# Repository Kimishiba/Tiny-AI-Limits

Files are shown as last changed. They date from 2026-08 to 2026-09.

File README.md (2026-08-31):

# ⚡ Tiny AI Limits & Desktop Companion (ESP32-C3)







An open-source, Wi-Fi enabled desktop telemetry companion powered by the ultra-compact **ESP32-C3 SuperMini** microcontroller.

👉 **[Try the In-Browser Hardware Simulator & Showcase Site](https://kimishiba.github.io/Tiny-AI-Limits/)**

It brings your AI developer environment to life with physical desktop hardware — monitoring real-time token quotas, **daily USD ($) spend**, and token telemetry across **Anthropic Claude**, **Google Antigravity**, **OpenRouter**, **DeepSeek**, and more, alerting you when AI agents require plan approvals, and serving as an expressive animated desk companion and synchronized clock.

---

## 🛠️ The Hardware You Can Build

**Tiny AI Limits** is built around a single physical form factor: the **GC9A01 1.28" Circular IPS Cyberdeck Edition**.

<p align="center">
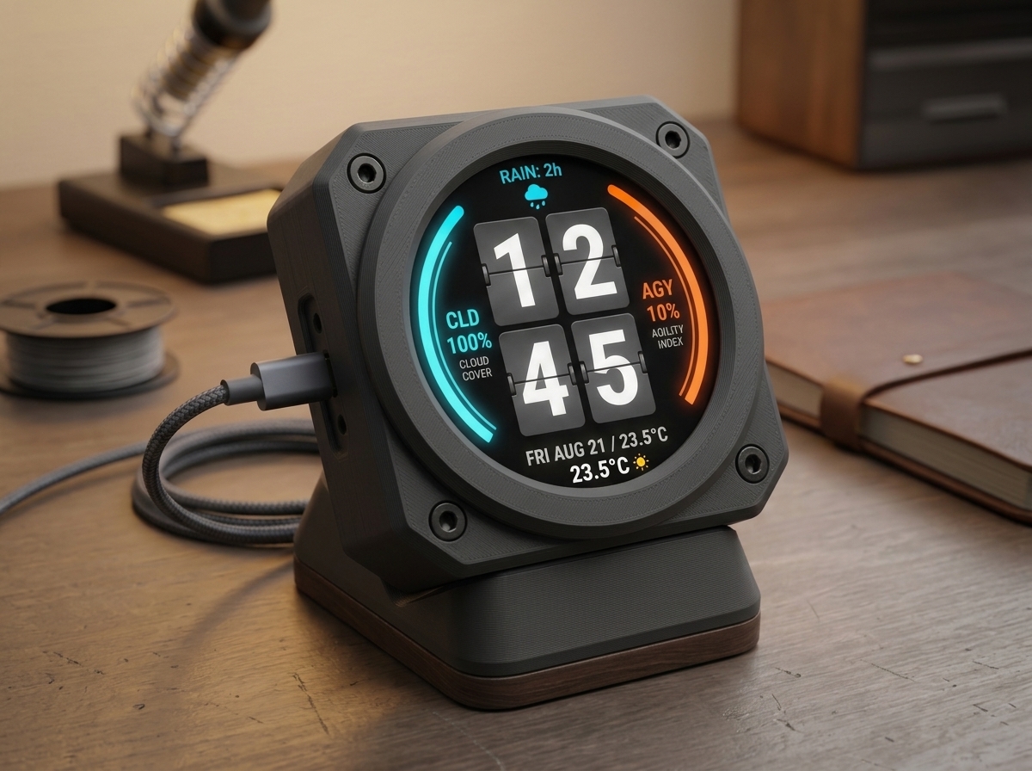
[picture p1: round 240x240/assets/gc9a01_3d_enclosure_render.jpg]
GC9A01 Circular Cyberdeck 3D Render
  
  &nbsp;&nbsp;&nbsp;&nbsp;
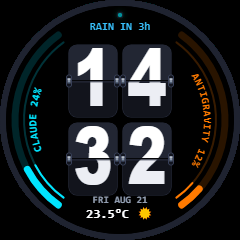
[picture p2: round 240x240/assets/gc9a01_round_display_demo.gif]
GC9A01 Circular Display UI Animation Demo
  
</p>

An industrial sci-fi desktop pod featuring a vibrant **1.28" Circular 240×240 IPS Color Display (GC9A01 SPI)** resting at an ergonomic $18^\circ$ backward tilt on a two-tier modular pedestal.

### ✨ Features:
* **Multi-Agent Status Monitor:** Dynamically replaces the central split-flap clock with a real-time HUD showing live agent activity across Claude Code CLI and Google Antigravity sessions (`WAITING 🟡`, `WORKING 🔵`, `COMPLETE 🟢`).
* **2×2 Split-Flap Flip Clock:** Mechanical split-card matrix animating hour and minute transitions when all agents are idle.
* **Universal Multi-Provider Gauges:** Independently assign any AI service to the Left and Right radial arcs (Claude, Google Antigravity, OpenRouter, DeepSeek, Groq, Mistral).
* **Standard Quota vs Enterprise Spend Modes:**
  * **Standard Quota Mode:** Real-time percentage remaining ($0\% \to 100\%$) and 5-hour rolling reset countdown timer (e.g. `4h 32m`).
  * **Enterprise / PAYG Mode:** Live calendar-day expenditure in **USD ($)** (e.g. `$0.13`), 24-hour token volume in the footer (`28.2k TOK`), and radial arc progression against a customizable **Daily Budget ($ USD)**.
* **Automatic Multi-Model Pricing:** Companion backend automatically scans local transcript turns and calculates exact pricing per model (Sonnet 3.7 / 3.5, Haiku, Opus, cache read/write).
* **Top Crown Connection & Rain Forecast:** Live telemetry heartbeat pulse and rain status (`Rain in 3h`, `Rain Now`, `No Rain`).
* **Stacked Bottom Sub-HUD:** Day & Date, live temperature with weather condition icons, and real-time **Agent Attention Alert** banner overrides (`AGENT ALERT: ALLOW BASH`, `ANSWER Q`, `APPROVE PLAN`).
* **Enclosure Architecture:** Support-free 3D-printable pod with $4\times$ counterbored brass M3 socket head cap screws, raised decorative ring, and a two-tier pedestal stand (Dark Walnut wood base plate with 4 alignment pillars + matte dark truncated trapezoidal cradle trunk).

<p align="center">
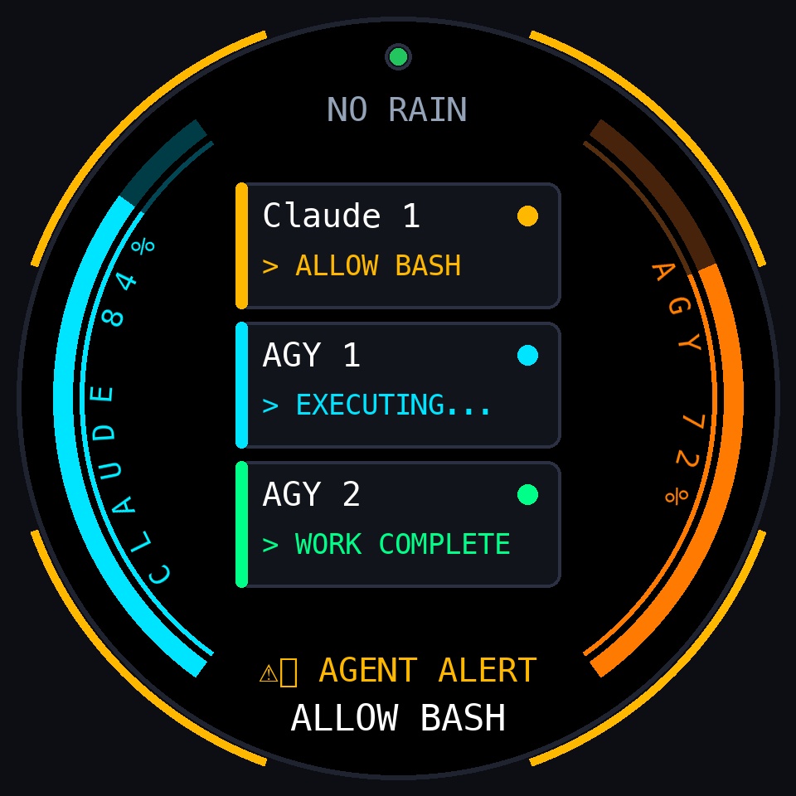
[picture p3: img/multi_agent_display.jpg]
Multi-Agent Status Monitor on GC9A01 Display
  
</p>

---

## 📊 Specifications

| Aspect | Detail |
| :--- | :--- |
| **Display Type** | 1.28" Round Color IPS (240×240) |
| **Interface** | High-Speed SPI |
| **Primary Theme** | Cyberdeck Split-Flap Clock & Dual Radial HUD |
| **Multi-Agent HUD** | Real-Time 3-Row Agent State Matrix (`WAITING`, `WORKING`, `COMPLETE`) |
| **Claude & Antigravity Gauges** | Dual Continuous $180^\circ$ Radial Arcs |
| **Agent Approval Warning** | High-Contrast Yellow/Orange Sub-HUD Alert + Kinetic Amber Hazard Ring |
| **Weather & Rain Forecast** | Top Crown Indicator + Temperature Sub-HUD |
| **Desk Stand** | Modular Two-Tier Pedestal (Walnut + Cradle) |

---

## 🛒 Bill of Materials (BOM) & Purchasing Guide

For a complete parts list, exact component specifications, and direct purchasing links (**Amazon**, **AliExpress**, **Waveshare**, **Adafruit**), see the dedicated BOM documentation:

* 📦 [**`BOM/README.md`**](bom/README.md) — Quick-Start Shopping Kit & Assembly Cost Summary.
* 📋 [**`BOM/BOM.md`**](bom/BOM.md) — Comprehensive Bill of Materials with verified purchasing links.

---

## 🔌 Hardware & Wiring Schematics

### 1. ESP32-C3 SuperMini Pinout (Microcontroller)
The ultra-compact ESP32-C3 SuperMini board powers the device via USB-C (3.3V logic).

---

### 2. GC9A01 Circular Display Wiring (Hardware SPI)

| GC9A01 Display Pin | ESP32-C3 SuperMini Pin | Description |
| :--- | :--- | :--- |
| **VCC** | **3V3** | 3.3V Power Rail |
| **GND** | **GND** | Ground |
| **SCL / SCLK** | **GPIO 4** | SPI Clock |
| **SDA / MOSI** | **GPIO 6** | SPI MOSI (Data) |
| **DC** | **GPIO 7** | Data / Command Control |
| **CS** | **GPIO 5** | Chip Select |
| **RST / RES** | **GPIO 1** | Hardware Reset |
| **BLK** | **GPIO 0** (or 3V3) | Backlight PWM / Enable |

*(For breadboard hookup instructions, see [`WIRING.md`](WIRING.md)).*

---

## 🖨️ 3D Printing & Enclosure Assembly

All enclosure CAD models are **100% support-free FDM 3D printable** and available in both parametric OpenSCAD sources and verified watertight STLs:

### Models Included (`round 240x240/enclosure/`):
* `gc9a01_springlatch_enclosure_flat.stl` — **Springlatch Edition:** 100% Print-in-Place articulated clamshell enclosure with Clockspring-style compliant wavy spring latch, push-button locking tabs, GC9A01 display mount, snap-fit ESP32-C3 cradle, and $18^\circ$ desktop kickstand pads (Flat 180° orientation, zero screws needed).
* `gc9a01_front_bezel.stl` — Front bezel display carrier with anti-shadow conical bevel and M3 counterbores.
* `gc9a01_main_housing.stl` — Enclosure bucket with lowered USB-C port and M3 corner pilot holes.
* `gc9a01_stand_tier1_base.stl` — Tier 1 base plate with 4 alignment pillars and rubber feet recesses (ideal for wood PLA or dark walnut).
* `gc9a01_stand_tier2_trunk.stl` — Tier 2 sculpted monolithic pedestal trunk with 4 slide sockets and $18^\circ$ V-saddle cradle notch.
* `gc9a01_desk_stand.stl` — Unified single-piece monolithic desk stand.

---

## 📖 Frequently Asked Questions (FAQ)

Have questions about the project, components, or setup? Check out the [FAQ](FAQ.md) for quick answers!

---

## 🚀 Getting Started

### 1. Build & Flash Firmware
Using **PlatformIO**:

```bash
# Build firmware
python -m platformio run

# Upload to ESP32 over USB-C
python -m platformio run --target upload
```

### 2. Launch the PC Companion Backend
The companion service monitors your local AI agent transcripts, queries live Antigravity token limits, fetches local weather data, and advertises itself via zero-config mDNS:

* **macOS:** Double-click **`Tiny Screen.app`** (native executable application with dedicated menu bar icon) or run `./TinyScreen.command`.
* **CLI / Cross-Platform:**
```bash
# Install dependencies
pip install -r backend/requirements.txt

# Launch backend
python backend/app.py
```
*(To rebuild or customize the macOS application bundle, run `./scripts/build_mac_app.sh`).*

### 3. USB WiFi Provisioning & Gauge Customization
With the device plugged in via USB-C, open **[`http://localhost:5000/setup`](http://localhost:5000/setup)** in Google Chrome or Microsoft Edge:
1. **Wi-Fi Setup:** Select the board's serial port, scan for networks, and enter your credentials. This also pairs the board to your machine.
2. **Configure Dual HUD Gauges:** Choose which AI service appears on the **Left** and **Right** radial arcs (Anthropic Claude, Google Antigravity, OpenRouter, DeepSeek, Groq, Mistral).
3. **Select Plan / Usage Mode per Provider:**
   * **Standard Quota (5h / Hourly Reset Timer):** Ideal for Claude Pro / Antigravity standard plans with 5-hour rolling quotas. Displays $\%$ remaining and time until quota resets (`4h 32m`).
   * **Enterprise Mode (Spend in $ & 24h Tokens):** Ideal for Enterprise, Team, or Pay-As-You-Go accounts. Displays live spend in **`$`** inside the corridor card (`$0.13`), total 24h token volume in the footer (`28.2k TOK`), and tracks progress against your customizable **Daily Budget ($ USD)**.
4. **Custom Cloud API Keys:** For cloud LLMs (OpenRouter, DeepSeek, Mistral, Groq), enter your API key in the collapsible accordion.

---

## 🔗 Multiple Boards on One Network

If several people run Tiny AI Screen on the same Wi-Fi (a shared office or household), each board needs to know *which* companion app is its own. Otherwise a board can pick up a colleague's app and display their Claude Code / Antigravity quotas.

**Pairing** solves this. Each companion app generates a stable `pair_id` (stored in `~/.tiny_ai_screen/config.json`), and a paired board talks only to the computer it was paired with.

* **Direct Serial Setup** (recommended) pairs the board automatically — no extra step.
* **"Connect & Set Up WiFi"** (Improv) can only send Wi-Fi credentials; the protocol has no room for an address. After it finishes, pair the board with the **"Pair an Existing Board"** box on the setup page, entering the board's IP.
* If your computer's IP changes (DHCP lease renewal), a paired board re-finds it automatically by matching `pair_id` against the mDNS TXT records. If that fails, re-pair with the same box.

**Pairing is one-way.** Once a board has been paired, it never goes back to picking whichever companion answers first — even if it loses track of its host. It will show no data and wait to be re-paired rather than risk reading someone else's stats.

**The top crown status arc tells you which mode a board is in:**

| Status Arc | Meaning |
| --- | --- |
| Green arc (pulsing) | Paired & connected, reading from your companion app |
| Amber arc | Connected but **unpaired** — the figures may not be yours |
| Red arc | No connection |

Each board also claims a unique mDNS name derived from its MAC — `tinyscreen-F030.local` rather than a shared `tinyscreen.local` — so several boards can coexist on one subnet.

> **Upgrading an existing board?** Boards flashed before pairing existed keep working: they fall back to mDNS discovery, and show the amber/unpaired indicator while they do. That fallback is exactly what can latch onto the wrong companion, so **re-run Direct Serial Setup once** after updating the firmware. After that the board is pinned for good.

---

## 🎨 Interactive Browser Prototype & Visualizer

Preview and interact with all screens, animations, and telemetry states in real time:

* **Full Display Emulator:** `http://localhost:5000/emulator`

---

## 📂 Repository Structure

```
├── backend/                  # Python Flask companion service & token trackers
│   ├── app.py
│   └── claude_statusline.py
├── round 240x240/            # GC9A01 1.28" Round IPS Edition
│   ├── enclosure/            # Parametric OpenSCAD & watertight STLs
│   │   ├── generate_stl.py
│   │   ├── gc9a01_cyberdeck_enclosure.scad
│   │   ├── gc9a01_front_bezel.stl
│   │   ├── gc9a01_main_housing.stl
│   │   ├── gc9a01_stand_tier1_base.stl
│   │   ├── gc9a01_stand_tier2_trunk.stl
│   │   └── gc9a01_desk_stand.stl
│   └── assets/               # 3D concept renders, animated demo GIF & mascot frames
│       ├── gc9a01_3d_enclosure_render.jpg
│       └── gc9a01_round_display_demo.gif
├── emulator/                 # Interactive browser visualizers & emulators
│   ├── index.html            # Canvas emulator for the round HUD
│   └── setup.html            # WebSerial USB Wi-Fi provisioning
├── img/                      # 3D product renders & animation demos
├── src/                      # ESP32-C3 Arduino C++ firmware
│   └── main.cpp
├── platformio.ini            # PlatformIO build configuration
├── WIRING.md                 # Detailed pinout & wiring documentation
└── README.md
```

---

## 📄 License
MIT License. Feel free to build, customize, and share your own desktop AI companion!

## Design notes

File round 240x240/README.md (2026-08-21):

# 🔘 GC9A01 1.28″ Round Display Cyberdeck (240×240)

An ultra-compact desktop telemetry HUD and 2×2 mechanical split-flap flip clock designed for the **GC9A01 1.28″ circular IPS display (240×240)** powered by the **ESP32-C3 SuperMini**.

Enclosure Front View
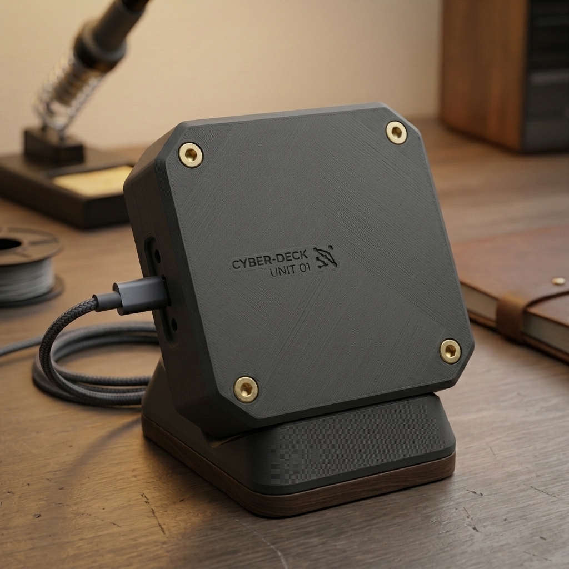
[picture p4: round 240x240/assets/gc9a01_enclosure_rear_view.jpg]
Enclosure Rear View


---

## 🌟 Features

* **Center 2×2 Split-Flap Clock:** Vintage mechanical flip digits (`12` top / `45` bottom) with tall $46\times 68\text{px}$ aspect ratio, dual-tone split creases, side hinge pin brackets, and animated 3D flap perspective folding.
* **Dual Flanking Radial Telemetry Gauges:**
  * **Left Gauge (Cyan):** Claude AI Quota remaining ($0\%$ at bottom $\to 100\%$ at top) with curved inside label `CLD %`.
  * **Right Gauge (Orange):** Antigravity Quota remaining ($0\%$ at bottom $\to 100\%$ at top) with curved inside label `AGY %`.
* **Top Crown Rain Metric:** Real-time weather integration indicating hours until next rain (`RAIN: 2h 🌧️` / `NO RAIN ☀️` / `RAIN NOW 🌧️`).
* **Stacked Bottom Sub-HUD:**
  * Line 1: Day & Date (`FRI AUG 21`)
  * Line 2: Live Temperature & Weather Icon (`23.5°C ☀️`)
  * Dynamic Alert Override: `⚠️ AGENT ALERT` + `APPROVE PLAN` with pulsing outer watch bezel.
* **Interactive Browser Emulator:** Full simulation at `http://localhost:5000/round` with screen type switcher, live telemetry sliders, and instant manual flip triggers.

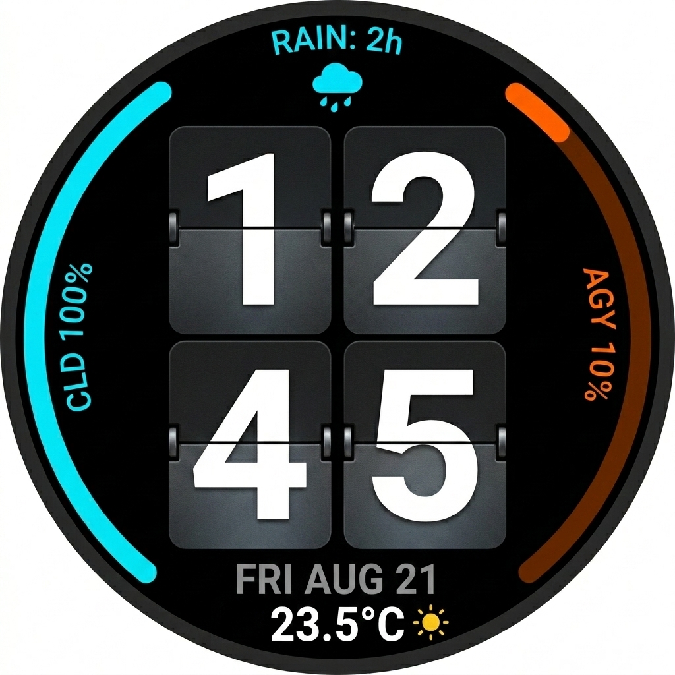
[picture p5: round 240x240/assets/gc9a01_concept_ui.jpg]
UI Concept


---

## 🖨️ 3D Printed Cyberdeck Enclosure

All 3D printable STL files and parametric CAD models are located in [`enclosure/`](enclosure/):

* **[`gc9a01_front_bezel.stl`](enclosure/gc9a01_front_bezel.stl):** Front plate with circular retention lip and counterbored M2 screw pockets.
* **[`gc9a01_main_housing.stl`](enclosure/gc9a01_main_housing.stl):** $22\text{mm}$ deep chassis with cavity for the ESP32-C3 SuperMini and USB-C port cutout.
* **[`gc9a01_desk_stand.stl`](enclosure/gc9a01_desk_stand.stl):** $20^\circ$ ergonomic angled desk base with cable relief channel.
* **[`gc9a01_cyberdeck_enclosure.scad`](enclosure/gc9a01_cyberdeck_enclosure.scad):** Parametric OpenSCAD source file.

---

## 🔌 Hardware Pinout (GC9A01 to ESP32-C3 SuperMini)

| GC9A01 Pin | ESP32-C3 SuperMini Pin | Function | Notes |
| :--- | :--- | :--- | :--- |
| **VCC** | `3V3` | Power Input | $3.3\text{V}$ Logic & Power |
| **GND** | `GND` | Ground | Common Ground |
| **SCL / SCK** | `GPIO 4` | SPI Clock | Hardware SPI SCLK |
| **SDA / MOSI** | `GPIO 6` | SPI MOSI | Hardware SPI Master Out |
| **DC** | `GPIO 7` | Data / Command | Command/Data Selection |
| **CS** | `GPIO 5` | Chip Select | Active Low |
| **RST** | `GPIO 1` | Hardware Reset | Active Low |
| **BLK / LED** | `3V3` or `GPIO 0` | Backlight | PWM Dimmable on GPIO 0 |

---

## 🚀 Running the Emulator

1. Start the Flask telemetry backend:
   ```bash
   python backend/app.py --server-only
   ```
2. Open your browser:
   * **Round Screen Direct:** [http://localhost:5000/round](http://localhost:5000/round)
   * **Main Emulator:** [http://localhost:5000/emulator](http://localhost:5000/emulator)

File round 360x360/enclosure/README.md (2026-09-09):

# 🖨️ GC9B72 2.1″ Round Display (360×360) Cyberdeck Enclosure (Heritage Edition)

3D printable enclosure files, slicer settings, hardware BOM, and assembly instructions for the **2.1-Inch GC9B72 Cyberdeck Desk Console**, engineered directly following the **240×240 Unit 01 Heritage Architecture** with the **Option 2 Rear-Loading Screen Architecture**:
* **100% Symmetrical 84mm Square Chassis ($84.0\text{mm} \times 84.0\text{mm}$)**
* **Option 2 Rear-Loading Screen Architecture (Direct M2 Tab Clamping):**
  * **100% Seamless Monolithic Front Face:** Clean solid front plate with a prominent raised circular bezel rim ($\varnothing 72.0\text{mm}$, $+2.8\text{mm}$ elevation) and a continuous anti-shadow conical viewing funnel expanding from $\varnothing 54.0\text{mm}$ at the screen shelf to $\varnothing 60.0\text{mm}$ at the ring summit.
  * **Zero Front Screws & Zero Exposed Cutouts:** The rectangular PCB tab, solder joints, flex ribbon, and 10-pin header are completely concealed inside the enclosure.
  * **Solid Front Retaining Lip:** $2.62\text{mm}$ continuous circular flange prevents display glass from ever pushing out the front.
  * **Direct M2 Screen Tab Clamping with Rising Boss Pillars:** 2x solid $\varnothing 4.40\text{mm}$ cylindrical boss pillars rise $1.80\text{mm}$ from the deepened tab pocket floor ($Z = 4.20\text{mm}$) up to the screen seating plane ($Z = 2.40\text{mm}$) at $X = \pm 12.20\text{mm}$, $Y = -31.50\text{mm}$ matching the blueprint `2-R1` holes. Each pillar contains a blind $\varnothing 1.70\text{mm}$ pilot hole ($3.6\text{mm}$ deep) allowing direct M2 screws from the back of the screen.
  * **Deepened Tab Relief & DuPont Clearance:** The tab pocket floor is recessed to $Z = 4.20\text{mm}$ with an extra $2.2\text{mm}$ trench over the header ($Y = -34.0\text{mm}$), giving ample room for forward-facing DuPont pins and solders around the rising pillars while leaving $\ge 2.40\text{mm}$ solid front wall thickness.
  * **Internal Rear Clamp Bracket (Optional / Legacy):** Preserved for backward compatibility, but no longer required when using the 2x direct M2 tab screws.
* **Chamfering & Edge Bevels:** $45^\circ$ outer bottom perimeter chamfer ($1.2\text{mm} \times 45^\circ$) + $7.0\text{mm} \times 45^\circ$ corner chamfers
* **Flush-Edge Microcontroller Mounting:** ESP32-S3/C3 SuperMini mounted **only $1.2\text{mm}$ from the outer left flank** for flush USB-C cable seating
* **Shaved-Depth USB-C Port:** Precision oval/stadium cutout ($r_{inner}=1.95\text{mm}$) with $45^\circ$ conical lead-in entry flare
* **High-Airflow Cooling System:**
  * 7 $\times$ vertical exhaust vents with $45^\circ$ peaked roof along top wall ($Y = +42\text{mm}$)
  * Contour-following horizontal rear aeration rows in outer zones ($|Y| \ge 16.5\text{mm}$)
  * Safe under-ESP32 cooling grille
* **Precision M.2-Style Screw Retention System (G0 Approved):**
  * **Bifurcated Front Capture Ears:** Left ($Y = -9.65\text{ to } -5.00\text{mm}$) and Right ($Y = +5.00\text{ to } +9.65\text{mm}$) ears with $45^\circ$ self-supporting lead-in chamfers trap front PCB shoulders against lift and pull-out, leaving central $10.0\text{mm}$ open for the USB-C metal shell.
  * **Expanded Clone Tolerances:** $19.30\text{mm}$ pocket width, $Z = 5.90\text{mm}$ ear height, $24.20\text{mm}$ longitudinal span swallows AliExpress board variations ($1.2 - 1.6\text{mm}$ thickness, $18.2 - 18.9\text{mm}$ width).
  * **Mechanical Thrust Stop Rib ($X = -17.0\text{mm}$):** Absorbs 100% of USB-C insertion forces directly into the chassis floor.
  * **Rear Standoff Post ($X = -11.5\text{mm}$):** $\varnothing 7.00\text{mm}$ post with thick $2.175\text{mm}$ solid plastic wall (5 perimeters) and $\varnothing 2.65\text{mm}$ pilot hole, eliminating hoop stress blowout. Positioned $> 5.5\text{mm}$ behind the ceramic antenna element to protect 2.4GHz Wi-Fi/BLE from RF detuning.
  * **Precision M3 Clamp Tab (`gc9b72_esp32_clamp_tab.stl`):** $11.50 \times 7.50 \times 4.00\text{mm}$ bridge tab with captive retention ring and 100% planar bed face for support-free printing in $\sim 2.5\text{ mins}$.
* **Dual Elevated DuPont Clearance Trenches:** Starts at $Z = 6.0\text{mm}$ with $45^\circ$ self-supporting bottom ramps along both the bottom wall (for screen 10-pin DuPont headers) and opposite right wall (for internal jumper bundle routing and side accessories).
* **Fasteners:**
  * 2x M2 $\times$ 4mm or 5mm Socket Head / Pan Head / Self-Tapping Screws for direct screen tab clamping ($\varnothing 1.70\text{mm}$ blind pilot holes in Front Face)
  * 4x M3 $\times$ 16mm Socket Head Cap Screws for Chassis Corners ($\varnothing 2.50\text{mm}$ direct-tap pilot posts)
  * 1x M3 $\times$ 6mm or 8mm Socket Head or Button Head Cap Screw for ESP32 Hold-Down Tab

---

## 📁 Included CAD & STL Files

All models are located in [`round 360x360/enclosure/`](./):

| File | Description | Outer Dims ($W \times D \times H$) | Print Time (est.) |
| :--- | :--- | :---: | :---: |
| **`gc9b72_front_face.stl`** | Monolithic Symmetrical 84mm Square Front Plate with prominent raised circular bezel rim, continuous conical viewing funnel, precision 31.2mm rear screen pocket, 2x direct M2 blind pilot holes, DuPont pin forward relief pocket, and 4x M3 corner countersunk holes | **$84.0 \times 84.0 \times 9.8\text{ mm}$** | ~45 mins |
| **`gc9b72_rear_clamp.stl`** | *(Optional / Heritage)* Slim Full-Footprint 84mm Sandwich Clamp Plate with 4x M3 corner clearance holes, center ventilation port, and precision 32.0mm screen PCB tab window | **$84.0 \times 84.0 \times 1.6\text{ mm}$** | ~12 mins |
| **`gc9b72_main_housing.stl`** | Symmetrical 84mm Square Housing Pod with tolerance-based press fit cradle, micro-crush ribs, front capture ears, shaved USB-C port, peaked roof vents, and 4x direct tap corner posts | **$84.0 \times 84.0 \times 28.0\text{ mm}$** | ~55 mins |
| **`gc9b72_stand_tier1_base.stl`** | Stand Tier 1 Accent Base Plate with 4x rubber feet pockets and alignment sockets | $94.0 \times 88.0 \times 6.0\text{ mm}$ | ~25 mins |
| **`gc9b72_stand_tier2_trunk.stl`** | Stand Tier 2 Cradle Trunk with $22^\circ$ V-saddle for 84mm pod and $26\text{mm}$ rear cable channel | $90.0 \times 85.0 \times 29.0\text{ mm}$ | ~50 mins |
| **`gc9b72_monolithic_stand.stl`** | Single-piece combined desk stand for 84mm square pod | $94.0 \times 88.0 \times 32.0\text{ mm}$ | ~70 mins |
| **`gc9b72_top_bezel.stl`** | *(Legacy / Optional)* External Circular Top Bezel Ring for front-clamping configurations | $74.6 \times 66.8 \times 4.5\text{ mm}$ | ~20 mins |
| **`gc9b72_cyberdeck_enclosure.scad`**| Fully parametric OpenSCAD master source model (Parts 0–6) | — | — |
| **`generate_stl.py`** | High-performance Python Manifold generator for watertight binary STLs | — | — |

---

## 🔩 Hardware Bill of Materials (BOM)

| Item | Quantity | Purpose | Notes |
| :--- | :---: | :--- | :--- |
| **GC9B72 2.1″ Round IPS TFT Display ($360\times 360$)** | 1 | Circular color display module | GoldenMorning / EstarDyn 10-pin SPI |
| **ESP32-S3 SuperMini / Zero (or C3 SuperMini)** | 1 | Microcontroller board | Press-fit into integrated cradle with crush ribs |
| **M2 $\times$ 4mm or 5mm Screws** | 2 | Clamps screen tab directly to Front Face | Direct taps into $\varnothing 1.70\text{mm}$ blind holes |
| **M3 $\times$ 16mm Socket Head Cap Screws** | 4 | Fastens Front Face directly to Main Housing Pod | Direct taps into $\varnothing 2.50\text{mm}$ corner posts |
| **8mm $\times$ 1.5mm Adhesive Rubber Feet** | 4 | Fitted into stand base recesses for non-slip desk grip | Optional |
| **USB-C Cable (Braided or Standard)** | 1 | Power & data connection through left port | Plugs into flush ESP32 port |

---

## 🛠️ Step-by-Step Assembly Sequence

1. **Install and Clamp the Display Module:**
   * Place the `gc9b72_front_face` face-down on a soft surface.
   * Drop the GC9B72 display module into the rear pocket cavity from behind. The round glass seats flush against the internal $2.62\text{mm}$ retaining lip, and the forward-facing DuPont header pins/solders clear into the dedicated relief trench.
   * Fasten 2x M2 $\times$ 4mm or 5mm screws through the screen's bottom tab mounting holes into the blind $\varnothing 1.70\text{mm}$ pilot holes. Tighten gently until snug. The screen is now 100% rigidly clamped to the front faceplate!
2. **Wire the Display:**
   * Plug female DuPont jumpers directly onto the 10-pin header.
3. **Install the Microcontroller (Tool-Free Drop-In Press Fit):**
   * Align the ESP32 directly over the open U-cradle with the USB-C connector facing the left wall port.
   * Press the board straight down onto the internal support ledges. The 4x vertical micro-crush ribs yield slightly against the fiberglass edges to firmly lock the board in place against the dual rear thrust corner shoulders ($X = -17.6\text{mm}$).
   * Connect the DuPont jumpers to the corresponding SPI pins on the ESP32.
4. **Close the Console:**
   * Mate the Main Housing Pod directly onto the back of the Front Face.
   * Thread the 4x M3 $\times$ 16mm screws into the corner counterbored holes from the front and tighten until snug. The entire console is assembled!

---

## ⚙️ Slicer Print Settings (Bambu Studio / PrusaSlicer / OrcaSlicer)

* **Material:** 
  * Main Housing & Rear Clamp: Matte Charcoal Black PLA / PETG.
  * Front Face Plate: Matte Charcoal Black with optional accent color ring or single color.
  * Stand Base: Wood PLA or Walnut Brown PLA.
* **Perimeters / Walls:** **`4` walls minimum** (ensures 100% solid plastic around the $\varnothing 2.05\text{mm}$ and $\varnothing 2.50\text{mm}$ pilot holes and cradle retaining clips).
* **Layer Height:** `0.16mm` or `0.20mm`.
* **Top / Bottom Solid Layers:** `4` top, `4` bottom.
* **Infill:** `20% Gyroid` or `Grid`.
* **Supports:** **NONE NEEDED** when oriented properly:
  * **Front Face:** Print flat front face-up (or face-down on a textured PEI sheet).
  * **Rear Clamp:** Print flat on build plate. Allow the spring steel build plate to cool completely to room temperature before removing to prevent deflection of the slim 1.6mm bottom bridge.
  * **Main Housing:** Print with rear backplate on build plate (cavity opening facing up).
  * **Desk Stand:** Print flat on bottom surface.

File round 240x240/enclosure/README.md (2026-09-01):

# 🖨️ GC9A01 1.28″ Round Display & ESP32-C3 SuperMini Cyberdeck Enclosure

3D printable enclosure files, slicer settings, hardware BOM, and assembly instructions for the **Tiny AI Limits Round Cyberdeck Desk Console** (reengineered directly from the concept 3D renders [`gc9a01_3d_enclosure_render.jpg`](../assets/gc9a01_3d_enclosure_render.jpg) and [`gc9a01_enclosure_rear_view.jpg`](../assets/gc9a01_enclosure_rear_view.jpg)).

> [!IMPORTANT]
> **Bottom DuPont Wire Drop Trench + Slim 26mm Depth:**
> * **Bottom Wire Drop Trench ($20\text{mm} \times 12\text{mm}$):** Positioned directly beneath the GC9A01 7-pin header ($Y = -24.74\text{mm}$), allowing DuPont connectors to plug in and drop directly into the desk stand's $20\text{mm}$ cable channel with zero vertical pinch.
> * **Direct Screen Bolting:** 2 $\times$ M2 threaded pilot holes on the front bezel matching the GC9A01 bottom tab mounting holes ($19.26\text{mm}$ pitch).
> * **Self-Locking Pin Standoffs:** 16 pin-registration blind holes ($2.54\text{mm}$ pitch) + rear thrust stop to lock the ESP32-C3 against insertion force.
> * **Sculpted Two-Tier Pedestal Stand:** $22^\circ$ ergonomic V-saddle cradle with tapered body, $20\text{mm}$ rear cable channel, and optional standalone accent base plate.

---

## 📁 Included CAD & STL Files

All models are located in [`round 240x240/enclosure/`](file:///c:/Users/Alex/Documents/Antigravity/Tiny%20AI%20Limits/round%20240x240/enclosure/):

| File | Description | Outer Dims ($W \times D \times H$) | Print Time (est.) |
| **[`gc9a01_springlatch_enclosure_flat.stl`](file:///Users/alessandrolongoni/Documents/Antigravity/Tiny%20AI%20Limits/round%20240x240/enclosure/gc9a01_springlatch_enclosure_flat.stl)** | **Springlatch 100% Print-in-Place Enclosure** with Clockspring-style compliant wavy spring latch, push-button locking tabs, GC9A01 viewing window, ESP32-C3 snap cradle, and kickstand pads (Flat 180° unfolded) | $56 \times 116 \times 20.0\text{mm}$ | ~60 mins |
| **[`gc9a01_springlatch_base.stl`](file:///Users/alessandrolongoni/Documents/Antigravity/Tiny%20AI%20Limits/round%20240x240/enclosure/gc9a01_springlatch_base.stl)** | Springlatch Lower Base Housing with $18^\circ$ kickstand pads, 4x rubber feet pockets, USB-C port, and ESP32-C3 cradle | $56 \times 58 \times 20.0\text{mm}$ | ~40 mins |
| **[`gc9a01_springlatch_lid.stl`](file:///Users/alessandrolongoni/Documents/Antigravity/Tiny%20AI%20Limits/round%20240x240/enclosure/gc9a01_springlatch_lid.stl)** | Springlatch Upper Hinged Lid with conical anti-shadow bezel, screen pocket, and compliant serpentine spring latch | $56 \times 58 \times 9.5\text{mm}$ | ~25 mins |
| **[`gc9a01_springlatch_enclosure.scad`](file:///Users/alessandrolongoni/Documents/Antigravity/Tiny%20AI%20Limits/round%20240x240/enclosure/gc9a01_springlatch_enclosure.scad)** | Parametric OpenSCAD source for Springlatch Edition (Parts 0–3: Flat PiP, Base, Lid, Closed preview) | — | — |
| **[`generate_springlatch_stl.py`](file:///Users/alessandrolongoni/Documents/Antigravity/Tiny%20AI%20Limits/round%20240x240/enclosure/generate_springlatch_stl.py)** | High-performance Python Manifold generator for watertight Springlatch STLs | — | — |
| **[`gc9a01_front_bezel.stl`](file:///Users/alessandrolongoni/Documents/Antigravity/Tiny%20AI%20Limits/round%20240x240/enclosure/gc9a01_front_bezel.stl)** | **V2.2 Front Bezel Plate** with flat flush mating base at $Z = 0$, $\varnothing 33.0\text{mm}$ conical anti-shadow window, $\varnothing 39.4\text{mm}$ screen pocket, 2 blind M2 pilot holes, and 4 M3 counterbored corner pockets | $54.4 \times 54.4 \times 11.0\text{mm}$ | ~25 mins |
| **[`gc9a01_mid_clamp.stl`](file:///Users/alessandrolongoni/Documents/Antigravity/Tiny%20AI%20Limits/round%20240x240/enclosure/gc9a01_mid_clamp.stl)** | Sandwich mid clamp diagonal X-brace with $7.0\text{mm}$ cross arms, forward compression pads, $\varnothing 14.0\text{mm}$ center component-relief hole, and open wiring quadrants | $54.4 \times 54.4 \times 2.6\text{mm}$ | ~10 mins |
| **[`gc9a01_main_housing.stl`](file:///Users/alessandrolongoni/Documents/Antigravity/Tiny%20AI%20Limits/round%20240x240/enclosure/gc9a01_main_housing.stl)** | Support-free $27.5\text{mm}$ deep **V2.2 Main Housing Pod** with 100% flat flush mating rim at $Z = 27.5\text{mm}$, snug $3.90\text{mm}$ USB-C port cutout ($Z = 6.60\text{mm}$), widened $18.70\text{mm}$ ESP32 carriage ($+0.20\text{mm}$ clearance), inside floor debossed "V2.2", 4x conical corner coring pockets, and dual DuPont trenches | $54.4 \times 54.4 \times 27.5\text{mm}$ | ~38 mins |
| **[`gc9a01_main_housing_legacy.stl`](file:///Users/alessandrolongoni/Documents/Antigravity/Tiny%20AI%20Limits/round%20240x240/enclosure/gc9a01_main_housing_legacy.stl)** | Legacy $27.5\text{mm}$ deep main housing with single bottom DuPont wire trench (preserved for rollback) | $54.4 \times 54.4 \times 27.5\text{mm}$ | ~45 mins |
| **[`gc9a01_minimalist_stand.stl`](file:///Users/alessandrolongoni/Documents/Antigravity/Tiny%20AI%20Limits/round%20240x240/enclosure/gc9a01_minimalist_stand.stl)** | Minimalist open A-frame cradle desk stand with $22^\circ$ tilt, front retaining lip, open triangular side window, and cable slot | $48 \times 62 \times 44.0\text{mm}$ | ~30 mins |
| **[`gc9a01_desk_stand.stl`](file:///Users/alessandrolongoni/Documents/Antigravity/Tiny%20AI%20Limits/round%20240x240/enclosure/gc9a01_desk_stand.stl)** | Sculpted two-tier pedestal cradle stand with $22^\circ$ V-saddle & slide-in pod channel | $64 \times 68 \times 29.0\text{mm}$ | ~45 mins |
| **[`gc9a01_stand_tier1_base.stl`](file:///Users/alessandrolongoni/Documents/Antigravity/Tiny%20AI%20Limits/round%20240x240/enclosure/gc9a01_stand_tier1_base.stl)** | Standalone Tier-1 bottom plate with 4 alignment pillars for wood PLA or dual-material printing | $64 \times 68 \times 8.5\text{mm}$ | ~20 mins |
| **[`gc9a01_stand_tier2_trunk.stl`](file:///Users/alessandrolongoni/Documents/Antigravity/Tiny%20AI%20Limits/round%20240x240/enclosure/gc9a01_stand_tier2_trunk.stl)** | Tier-2 cradle trunk with alignment sockets and $22^\circ$ V-saddle | $62 \times 66 \times 24.0\text{mm}$ | ~40 mins |
| **[`gc9a01_cyberdeck_enclosure.scad`](file:///Users/alessandrolongoni/Documents/Antigravity/Tiny%20AI%20Limits/round%20240x240/enclosure/gc9a01_cyberdeck_enclosure.scad)** | Fully parametric OpenSCAD source file (part 0 to 7) | — | — |
| **[`generate_stl.py`](file:///Users/alessandrolongoni/Documents/Antigravity/Tiny%20AI%20Limits/round%20240x240/enclosure/generate_stl.py)** | Standalone Boolean CSG mesh generator script generating 100% watertight binary STLs | — | — |

---

## 🔩 Hardware Bill of Materials (BOM)

| Item | Quantity | Purpose |
| :--- | :---: | :--- |
| **GC9A01 1.28″ Round IPS SPI Display** | 1 | Circular $240\times 240$ color screen module |
| **ESP32-C3 SuperMini** | 1 | Microcontroller board (pin headers soldered facing up) |
| **Female-to-Female DuPont Jumpers (10cm)** | 7 | Standard jumper wires for SPI wiring harness |
| **M3 $\times$ 35mm Socket Head Cap Screws** | 4 | Fastens Front Bezel $\to$ Mid Clamp $\to$ Main Housing |
| **M3 Brass Heat-Set Inserts / Direct Tap** | 4 | Main housing corner posts |
| **8mm $\times$ 1.5mm Adhesive Rubber Feet** | 4 | Fitted into stand base recesses for non-slip desk grip |
| **USB-C Cable (Braided or Right-Angle)** | 1 | Power delivery & firmware flashing |

---

## ⚙️ Slicer Print Settings (Cura / PrusaSlicer / Bambu Studio / OrcaSlicer)

* **Material:** Matte Charcoal Black PLA / PETG for the housing & bezel, Accent color (e.g. Orange / Cyan / White) for the Mid Clamp, Wood PLA or Walnut Brown for the stand base.
* **Layer Height:** `0.16mm` or `0.20mm`.
* **Perimeters / Walls:** `3` walls (for solid screw hole threading and spring flexures).
* **Top/Bottom Solid Layers:** `4` top, `4` bottom.
* **Infill:** `20% Gyroid` or `Grid`.
* **Supports:** **NO SUPPORTS NEEDED** when oriented properly:
  * **Springlatch Full PiP Assembly (`gc9a01_springlatch_enclosure_flat.stl`):** Print flat unfolded on build plate ($180^\circ$ orientation). The self-supporting $45^\circ$ conical hinge pins and compliant spring air slits print completely support-free.
  * **Front Bezel:** Print face-down on build plate (flat side down).
  * **Mid Clamp:** Print flat on build plate (compression lip facing up).
  * **Main Housing:** Print with rear face on build plate (open front cavity facing up).
  * **Desk Stand:** Print flat on base bottom (angled V-saddle cradle facing up).

---

## 🪗 Springlatch Edition: Zero-Hardware Tool-less Operation

The **Springlatch Edition** (`gc9a01_springlatch_enclosure_flat.stl`) allows 100% screwless, tool-less assembly:

1. **Print in One Piece:** Print the entire assembly unfolded flat on your 3D printer bed in ~60 minutes.
2. **First Flex (Break-In):** Gently wiggle the hinge to break free the $0.38\text{mm}$ print-in-place clearance cones until it swings smoothly through $180^\circ$.
3. **Mount Electronics:**
   * Snap the **ESP32-C3 SuperMini** into the lower tub cradle (held securely by the compliant snap arm).
   * Insert the **GC9A01 1.28″ Round Display** into the upper lid's rear pocket.
   * Connect the 7-wire SPI harness between the board and display.
4. **Push-to-Close Auto Latch:** Swing the lid closed. The dual front locking hooks ride up the base's $45^\circ$ lead-in ramps, flexing the serpentine spring back until snapping securely into the undercut catches.
5. **Desk Operation:** The integrated rear kickstand pads keep the console resting at an ergonomic $18^\circ$ viewing angle on your desk. Press the center tactile thumb button to flex the spring and pop open the lid anytime.

---

## 🪛 Assembly Step-by-Step

1. **Insert Screen into Front Bezel:** Drop the GC9A01 display face-down into the rear pocket of the front bezel.
2. **Position Mid Clamp:** Place the **Mid Clamp** behind the screen so the circular compression collar rests against the rear fiberglass rim of the PCB.
3. **Mount ESP32-C3 & Wire Harness:** Drop the ESP32-C3 SuperMini into the main housing standoffs and connect the 7 SPI jumper wires between the **GC9A01** and **ESP32-C3 SuperMini**:
   * `SCL` $\to$ `GPIO 4`
   * `SDA` $\to$ `GPIO 6`
   * `CS` $\to$ `GPIO 5`
   * `DC` $\to$ `GPIO 7`
   * `RST` $\to$ `GPIO 1`
   * `BLK` $\to$ `3V3` or `GPIO 0`
   * `VCC` $\to$ `3V3` / `GND` $\to$ `GND`
4. **Fasten 3-Piece Sandwich:** Mate Front Bezel $\to$ Mid Clamp $\to$ Main Housing and secure with 4 $\times$ M3 corner screws. Tightening the corner screws compresses the mid clamp against the screen PCB, locking it rigidly against the front window.
5. **Slot into Stand:** Slide the assembled pod into the sculpted $22^\circ$ V-saddle desk cradle and connect your USB-C cable through the chamfered port opening.

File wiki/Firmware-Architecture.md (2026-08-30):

# 💻 Firmware Architecture & Internals

The **Tiny AI Limits** firmware is written in C++ for the ESP32-C3 microcontroller using the Arduino framework and **PlatformIO**. It features a non-blocking rendering engine, hardware-accelerated SPI communication, smooth antialiased circular HUD math, and low-latency mDNS network discovery.

---

## 🛠️ Build System & PlatformIO Configuration

The project uses `platformio.ini` to declare hardware architecture, compiler optimizations, and pin definitions for `TFT_eSPI` directly in `build_flags`:

```ini
[env:esp32-c3-supermini]
platform = espressif32
board = esp32-c3-devkitm-1
framework = arduino
monitor_speed = 115200
board_build.flash_mode = dio
board_build.f_flash = 80000000L
board_build.f_cpu = 160000000L

lib_deps =
    bodmer/TFT_eSPI@^2.5.43
    bblanchon/ArduinoJson@^7.0.0
    ESPmDNS

build_flags =
    -DUSER_SETUP_LOADED=1
    -DGC9A01_DRIVER=1
    -DTFT_WIDTH=240
    -DTFT_HEIGHT=240
    -DTFT_MISO=-1
    -DTFT_MOSI=6
    -DTFT_SCLK=4
    -DTFT_CS=5
    -DTFT_DC=7
    -DTFT_RST=1
    -DTFT_BL=0
    -DSPI_FREQUENCY=40000000
```

---

## 🎨 Graphics Pipeline & Double-Buffered Sprites

To eliminate screen tearing and flickering on the 240×240 circular display, all HUD elements are rendered into off-screen **`TFT_eSprite`** memory buffers in the ESP32-C3 internal SRAM before being pushed via DMA/Hardware SPI to the GC9A01 controller.

```
 ┌─────────────────────────────────────────────────────────────┐
 │                      ESP32-C3 SRAM                          │
 │                                                             │
 │  ┌───────────────────────────────────────────────────────┐  │
 │  │                 TFT_eSprite HUD Layer                 │  │
 │  │                                                       │  │
 │  │   [Radial Arcs]       [Text Glyphs]   [Mascot Frame]  │  │
 │  │        │                    │               │         │  │
 │  │        └──────────────┬─────┴───────────────┘         │  │
 │  │                       ▼                               │  │
 │  │              Rendered HUD Buffer (240x240)            │  │
 │  └───────────────────────┬───────────────────────────────┘  │
 └──────────────────────────┼──────────────────────────────────┘
                            ▼ High-Speed SPI (40 MHz)
 ┌─────────────────────────────────────────────────────────────┐
 │            GC9A01 Controller Framebuffer                    │
 │               (Circular 240×240 IPS Panel)                  │
 └─────────────────────────────────────────────────────────────┘
```

---

## 📐 Radial Arc Trigonometric Math

The dual gauge HUD renders continuous arcs spanning from $135^\circ$ to $405^\circ$ ($270^\circ$ sweep) or twin $180^\circ$ semi-circles.

### Arc Coordinate Projection Formula
For a given center $(x_0, y_0)$ and radius $r$, points on the radial arc at angle $\theta$ (in radians) are calculated as:

$$x = x_0 + r \cdot \cos(\theta)$$
$$y = y_0 + r \cdot \sin(\theta)$$

In the firmware, angles are interpolated linearly between starting angle $\theta_{\text{start}}$ and ending angle $\theta_{\text{end}}$ corresponding to normalized percentage $p \in [0.0, 1.0]$:

$$\theta(p) = \theta_{\text{start}} + p \cdot (\theta_{\text{end}} - \theta_{\text{start}})$$

Smooth segmented antialiasing is achieved by stepping in $\Delta\theta \approx 1^\circ$ increments, drawing thick line segments between inner radius $r_{\text{inner}}$ and outer radius $r_{\text{outer}}$.

---

## 🚦 Firmware State Machine

The main execution loop operates as an asynchronous, non-blocking finite state machine (FSM):

```mermaid
stateDiagram-v2
    [*] --> STATE_BOOT: Power On / Reset
    STATE_BOOT --> STATE_WIFI_CONNECTING: Load NVS Credentials
    
    STATE_WIFI_CONNECTING --> STATE_MDNS_DISCOVERY: Wi-Fi Connected
    STATE_WIFI_CONNECTING --> STATE_PAIRING_RADAR: No Wi-Fi / Bad Creds
    
    STATE_MDNS_DISCOVERY --> STATE_ACTIVE_HUD: Host Found & Paired
    STATE_MDNS_DISCOVERY --> STATE_UNPAIRED_FALLBACK: Host Found (Unpaired)
    STATE_MDNS_DISCOVERY --> STATE_DISCONNECTED: Host Lookup Timeout
    
    STATE_ACTIVE_HUD --> STATE_ACTIVE_HUD: HTTP 200 OK (every 2s)
    STATE_ACTIVE_HUD --> STATE_DISCONNECTED: Consecutive HTTP Errors
    
    STATE_DISCONNECTED --> STATE_MDNS_DISCOVERY: Retry mDNS Poll
    STATE_PAIRING_RADAR --> STATE_WIFI_CONNECTING: Serial Config Received
```

### State Definitions
1. **`STATE_BOOT`:** Initializes hardware GPIOs, SPI bus, TFT display, loads saved configuration from Non-Volatile Storage (NVS).
2. **`STATE_WIFI_CONNECTING`:** Attempts connection to stored SSID. Displays connecting spinner.
3. **`STATE_PAIRING_RADAR`:** Activated when no Wi-Fi credentials exist. Listens for WebSerial configuration and pulses the radar ring.
4. **`STATE_MDNS_DISCOVERY`:** Queries the local subnet for `_tinyscreen._tcp` services to resolve the host companion IP address.
5. **`STATE_ACTIVE_HUD`:** Actively polls `/api/limits` every 2000ms. Renders the real-time agent matrix, dual arcs, weather crown, and alert indicators.
6. **`STATE_DISCONNECTED`:** Triggered if 3 consecutive HTTP poll attempts fail. Renders red status crown and retries mDNS host resolution.

---

## 💾 Non-Volatile Storage (NVS Preferences)

The firmware uses the ESP32 `Preferences` library (stored in the flash NVS partition) to maintain persistent state across power cycles:

| Key | Type | Description |
| :--- | :--- | :--- |
| `wifi_ssid` | `String` | Wi-Fi network SSID |
| `wifi_pass` | `String` | Wi-Fi WPA2 pre-shared key |
| `pair_id` | `String` | UUIDv4 token matching the host companion app |
| `host_ip` | `String` | Last known static/cached IP address of the host |
| `gauge_l` | `String` | Left gauge provider identifier (e.g. `claude`) |
| `gauge_r` | `String` | Right gauge provider identifier (e.g. `antigravity`) |

---

## ⚡ Serial Command Protocol

In addition to standard Improv Wi-Fi serial frames, the ESP32 firmware accepts ASCII commands over USB-C CDC:

* `WIFI:<ssid>:<password>:<pair_id>\n` — Stores Wi-Fi credentials and binds the board to the provided host `pair_id`.
* `PAIR:<pair_id>\n` — Updates or overrides the paired host UUID without changing Wi-Fi credentials.
* `INFO?\n` — Returns board MAC address, firmware version, IP address, and current pairing status.
* `RESET\n` — Clears NVS preferences and reboots into setup mode.

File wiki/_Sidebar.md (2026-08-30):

### 🚀 Getting Started
* [[Home]]
* [[Quick Start Guide|Quick-Start-Guide]]
* [[Hardware & Wiring|Hardware-&-Wiring]]

### 💻 Architecture & Internals
* [[Firmware Architecture|Firmware-Architecture]]
* [[Backend Companion App|Backend-Companion-App]]
* [[AI Providers & Quota Tracking|AI-Providers-&-Quota-Tracking]]
* [[Pairing & Multi-Board Setup|Pairing-&-Multi-Board-Setup]]
* [[WebSerial Provisioning & Web UI|WebSerial-Provisioning-&-Web-UI]]

### 🛠️ Hardware & Fabrication
* [[3D Printing & Enclosure Assembly|3D-Printing-&-Enclosure-Assembly]]
* [[Bill of Materials (BOM)|Hardware-&-Wiring#bill-of-materials-bom]]

### ❓ Support & Diagnostics
* [[Troubleshooting & FAQ|Troubleshooting-&-FAQ]]

---
[⭐ GitHub Repository](https://github.com/Kimishiba/Tiny-AI-Limits)

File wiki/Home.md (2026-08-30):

# Welcome to the Tiny AI Limits Wiki

**Tiny AI Limits** (also known as **Tiny AI Screen**) is an open-source, ultra-compact physical desktop telemetry HUD. Powered by an **ESP32-C3 SuperMini** microcontroller and a vibrant **GC9A01 240×240 circular IPS display**, it provides continuous, ambient visibility into your AI coding workflows, token quotas, agent state lifecycles, and environmental context.

```
                  ┌─────────────────────────────────┐
                  │       TINY AI SCREEN HUD        │
                  │                                 │
                  │      ╭───────────────────╮      │
                  │    ╭─╯  TOP CROWN ARC    ╰─╮    │
                  │   ╭╯   (Weather / Rain)   ╰╮    │
                  │  ╭╯                        ╰╮   │
                  │  │ [CLAUDE]        [AGY]    │   │
                  │  │  84% LEFT      $0.12     │   │
                  │  │ (5h Reset)   (Daily Lim) │   │
                  │  │ ──────────────────────── │   │
                  │  │ AGENT 1: WAITING  (Gray) │   │
                  │  │ AGENT 2: WORKING  (Blue) │   │
                  │  │ AGENT 3: COMPLETE (Grn)  │   │
                  │  ╰╮                        ╭╯   │
                  │   ╰╮   HAZARD ALERT RING  ╭╯    │
                  │    ╰─╮ (Needs Approval!) ╭─╯    │
                  │      ╰───────────────────╯      │
                  │        ESP32-C3 SuperMini       │
                  └─────────────────────────────────┘
```

---

## 🌟 Core Highlights

* **Dual $180^\circ$ Continuous Radial Gauges:** Track any two supported AI providers simultaneously (e.g. Anthropic Claude on the left, Google Antigravity on the right).
* **Multi-Agent 3-Row State Matrix:** Real-time visual matrix displaying subagent lifecycle states (`WAITING`, `WORKING`, `COMPLETE`) with color-coded pulsing badges.
* **Intelligent Plan & Quota Tracking Modes:**
  * **Standard Quota Mode:** Real-time percentage remaining and countdown to the next rolling 5-hour quota reset window (`4h 32m`).
  * **Enterprise Mode:** Live dollar spend tracking (`$0.13`), total 24-hour token volume (`28.2k TOK`), and progress bars measured against a customizable daily budget limit.
* **Agent Approval Ring & Sub-HUD Alert:** High-contrast kinetic amber hazard ring when an agent is awaiting interactive tool approval or user confirmation.
* **Dynamic Weather & Precipitation Crown:** Integrated top-crown arc showing temperature, weather conditions, and rain forecasts from Open-Meteo.
* **Zero-Config mDNS & Secure Host Pairing:** Automatic host discovery via `_tinyscreen._tcp.local.` with cryptographic `pair_id` verification to prevent cross-talk in multi-board office environments.
* **WebSerial Browser Provisioning:** Zero-driver Wi-Fi and gauge configuration directly from Google Chrome or Microsoft Edge via WebSerial.
* **100% Support-Free 3D Printable Enclosure:** Parametric OpenSCAD design with snap-fit bezels, M3 counterbores, and modular two-tier wooden/PLA desk pedestal stands.

---

## 📚 Complete Wiki Documentation

| Chapter | Topic & Overview |
| :--- | :--- |
| 🚀 [[Quick Start Guide\|Quick-Start-Guide]] | 15-minute quickstart from hardware assembly and flashing to backend pairing. |
| 🔌 [[Hardware & Wiring\|Hardware-&-Wiring]] | Complete BOM, ESP32-C3 SuperMini pinouts, GC9A01 SPI schematics, and power rails. |
| 💻 [[Firmware Architecture\|Firmware-Architecture]] | Deep dive into the ESP32 C++ firmware, TFT_eSPI sprites, radial math, and state machines. |
| 🐍 [[Backend Companion App\|Backend-Companion-App]] | Flask architecture, Zero-Config mDNS daemon, REST API schema, and transcript parsers. |
| 🤖 [[AI Providers & Quota Tracking\|AI-Providers-&-Quota-Tracking]] | Complete guide to configuring Claude, Antigravity, OpenRouter, DeepSeek, Groq, Mistral, and more. |
| 🔐 [[Pairing & Multi-Board Setup\|Pairing-&-Multi-Board-Setup]] | Deep dive into `pair_id` handshakes, mDNS TXT records, and crown status indicators. |
| 🌐 [[WebSerial Provisioning & Web UI\|WebSerial-Provisioning-&-Web-UI]] | USB-C serial provisioning, gauge customizer, and real-time browser Canvas emulator. |
| 🖨️ [[3D Printing & Enclosure Assembly\|3D-Printing-&-Enclosure-Assembly]] | OpenSCAD parametric parameters, slicer settings, assembly instructions, and stand models. |
| 🩺 [[Troubleshooting & FAQ\|Troubleshooting-&-FAQ]] | Solutions for flashing errors, SPI glitches, Wi-Fi connectivity, mDNS issues, and quota parsing. |

---

## 🏗️ Architecture Overview

```mermaid
graph TD
    subgraph "Workstation / Laptop"
        A[Claude Code / Antigravity Transcripts] --> D[Python Companion App]
        B[Cloud AI APIs: OpenRouter / DeepSeek] --> D
        C[Open-Meteo Weather API] --> D
        D --> E[mDNS Daemon _tinyscreen._tcp]
        D --> F[Flask REST API :5000/api/limits]
    end

    subgraph "Tiny AI Screen (ESP32-C3)"
        G[mDNS Discovery Engine] -.->|Locates Host| E
        H[HTTP Client] -->|Polls JSON Telemetry| F
        H --> I[HUD Telemetry Engine]
        I --> J[TFT_eSPI Sprite Renderer]
        J --> K[GC9A01 240x240 Circular IPS]
    end

    subgraph "Web Browser (Chrome/Edge)"
        L[WebSerial USB Provisioner] -->|Serial WiFi & Pairing| TinyScreen_USB[ESP32 USB-C]
    end
```

---

## 🤝 Community & Support

* **Source Code Repository:** [GitHub - Kimishiba/Tiny-AI-Limits](https://github.com/Kimishiba/Tiny-AI-Limits)
* **Bug Reports & Feature Requests:** [GitHub Issues](https://github.com/Kimishiba/Tiny-AI-Limits/issues)
* **License:** [MIT License](https://github.com/Kimishiba/Tiny-AI-Limits/blob/main/README.md#license)

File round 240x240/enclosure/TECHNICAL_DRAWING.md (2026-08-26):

# 📐 GC9A01 1.28″ Cyberdeck Desk Enclosure — Technical Drawing & CAD Specification

**Document ID:** `DOC: CD-240-DWG`  
**Revision:** `v2.4 (DuPont-Cleared Edition)`  
**Source Vector Blueprint:** [`gc9a01_cyberdeck_technical_drawing.svg`](gc9a01_cyberdeck_technical_drawing.svg)  
**High-Resolution Render:** [`gc9a01_cyberdeck_technical_drawing.png`](gc9a01_cyberdeck_technical_drawing.png)  
**Parametric CAD Source:** [`gc9a01_cyberdeck_enclosure.scad`](gc9a01_cyberdeck_enclosure.scad)  
**Direct 3D Mesh Generator:** [`generate_stl.py`](generate_stl.py)

---

## 🖼️ Multi-View Engineering Blueprint

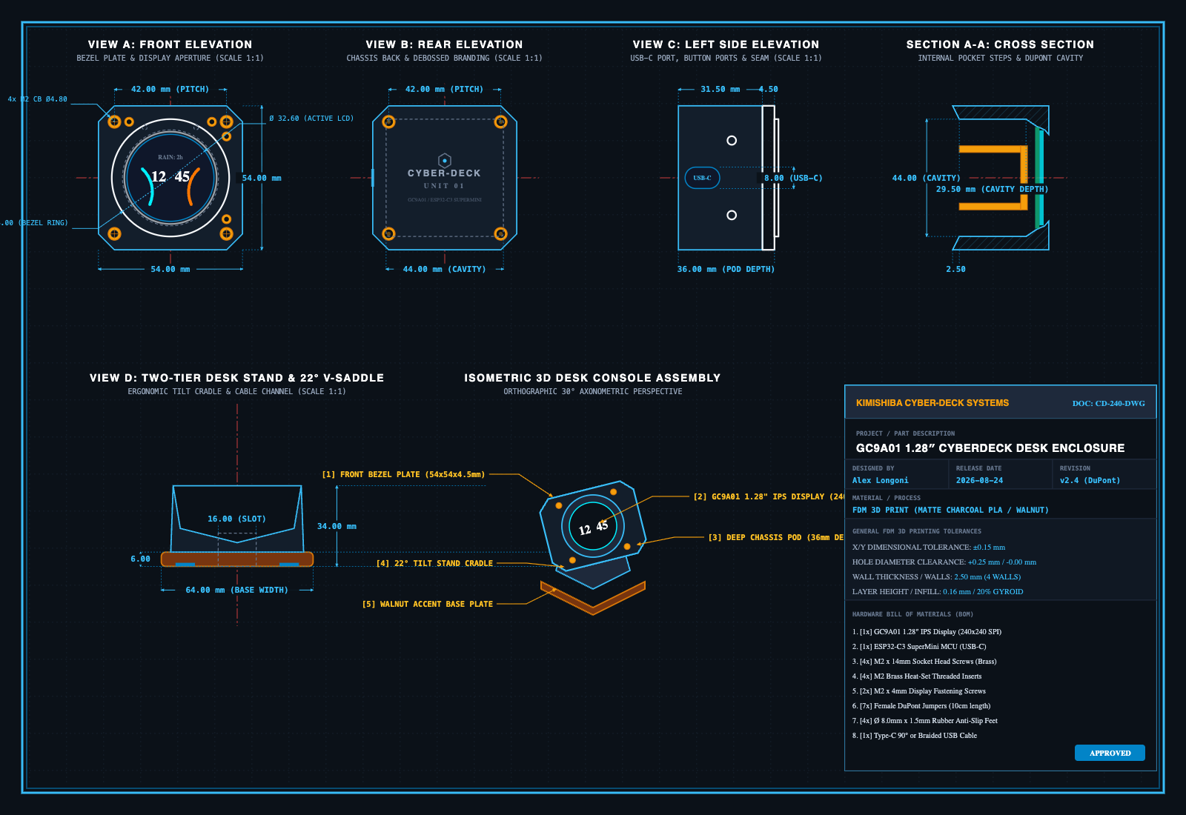
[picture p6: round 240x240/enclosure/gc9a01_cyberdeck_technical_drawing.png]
Engineering Blueprint


---

## 🎯 Coordinate Origin & Datum System

* **Primary Coordinate Datum $(0, 0, 0)$:** Center of the front display glass aperture on the front face of the bezel plate.
* **$X$-Axis:** Horizontal (Left $-X$, Right $+X$).
* **$Y$-Axis:** Vertical (Bottom $-Y$, Top $+Y$).
* **$Z$-Axis:** Depth (Front Bezel Face $+Z$, Rear Wall $-Z$).

---

## 📐 Dimensional Specification by View

### 1. View A: Front Elevation (Bezel Plate)
* **Outer Profile:** Chamfered Square / Octagon: $54.00\text{mm} \times 54.00\text{mm}$.
* **Corner Chamfers:** $4 \times 6.00\text{mm} \times 45^\circ$.
* **Raised Visor Trim Ring:** $\varnothing 44.00\text{mm}$ outer diameter, height $+1.50\text{mm}$ ($Z = 4.5\text{mm} \to 6.0\text{mm}$).
* **Active Display Window Aperture:** $\varnothing 32.60\text{mm}$ through-hole with an inner $45^\circ$ viewing chamfer expanding to $\varnothing 34.60\text{mm}$ on the front.
* **Glass Retention Recess Step:** $\varnothing 36.00\text{mm} \times 1.60\text{mm}$ deep (locates the $35.6\text{mm}$ display glass lens).
* **Primary Corner Fastener Array:** 
  * 4 Holes at $(X, Y) = (\pm 21.00\text{mm}, \pm 21.00\text{mm})$ ($42.00\text{mm}$ square pitch).
  * Through-hole: $\varnothing 2.60\text{mm}$ (M2 / M2.5 clearance).
  * Counterbore Head Pocket: $\varnothing 4.80\text{mm} \times 2.20\text{mm}$ deep.
* **Secondary Accent Screw Pockets:**
  * Paired brass screw pockets at $(+15.5, -21.0)$, $(+21.0, -15.5)$, $(-15.5, -21.0)$, $(+21.0, +15.5)\text{mm}$.
  * Recess: $\varnothing 3.40\text{mm} \times 1.20\text{mm}$ deep with $\varnothing 1.80\text{mm}$ pilot.
* **Direct Screen Fastening Holes:**
  * 2 M2 pilot holes on rear of bezel at $(X = \pm 9.63\text{mm}, Y = -18.91\text{mm})$.
  * Thread depth: $3.20\text{mm}$, hole diameter: $\varnothing 1.80\text{mm}$.

---

### 2. View B: Rear Elevation (Chassis Back)
* **Chassis Outer Profile:** $54.00\text{mm} \times 54.00\text{mm}$ with $6.00\text{mm} \times 45^\circ$ corner chamfers.
* **Rear Wall Thickness:** $2.50\text{mm}$ solid floor.
* **Rear Corner Threaded Insert Sockets:**
  * 4 Pockets at $(X, Y) = (\pm 21.00\text{mm}, \pm 21.00\text{mm})$.
  * M2 Brass Insert Bore: $\varnothing 3.20\text{mm} \times 4.00\text{mm}$ deep with $\varnothing 4.80\text{mm}$ outer collar.
* **Debossed Branding Area:**
  * **Hex Circuit Icon:** Width $16.00\text{mm}$, centered at $(0, +23.00\text{mm})$, depth $0.60\text{mm}$.
  * **Typography Line 1:** `"CYBER-DECK"` (Font Height: $3.50\text{mm}$, Tracking: $+2.0$, depth $0.50\text{mm}$).
  * **Typography Line 2:** `"UNIT 01"` (Font Height: $2.80\text{mm}$, Tracking: $+3.0$, depth $0.50\text{mm}$).

---

### 3. View C: Left Side Elevation (Ports & Profile)
* **Total Assembly Pod Depth:** $36.00\text{mm}$.
  * Front Bezel Plate Thickness: $4.50\text{mm}$ ($+1.50\text{mm}$ raised ring = $6.00\text{mm}$ total).
  * Main Housing Chassis Depth: $31.50\text{mm}$.
* **USB-C Port Cutout:**
  * Dimensions: $13.00\text{mm}$ wide (along $Y$) $\times 8.00\text{mm}$ tall (along $Z$).
  * Corner Radius: $R = 4.00\text{mm}$ (Full stadium oval).
  * Center Position: $X = -27.00\text{mm}$ (outer left face), $Y = 0.00\text{mm}$, $Z = 9.00\text{mm}$ from back face.
* **Side Tactile Button / LED Ports:**
  * 2 Ports: $\varnothing 3.20\text{mm}$ at $Y = \pm 14.00\text{mm}$, $Z = 20.00\text{mm}$ from back face.

---

### 4. Section A-A: Internal Cavity Cross-Section
* **Main Electronics Cavity:** $44.00\text{mm} \times 44.00\text{mm} \times 29.50\text{mm}$ usable interior depth.
* **DuPont Connector Clearance:** Provides $>28\text{mm}$ vertical/horizontal clearance for standard $14.0\text{mm}$ female DuPont housings.
* **GC9A01 Display Pocket (Front):**
  * Circular PCB Section: $\varnothing 38.60\text{mm} \times 4.00\text{mm}$ deep.
  * Connector Tab Extension: $23.60\text{mm}$ wide $\times 26.80\text{mm}$ long from center.
* **ESP32-C3 SuperMini Mounting Rails:**
  * Standoff Height: $2.50\text{mm}$ above rear floor (solder joint clearance).
  * Rail Spacing: Centered along pin rows at $Y = \pm 7.62\text{mm}$ ($15.24\text{mm} / 0.60\text{″}$ pitch).
  * **16 Pin-Locking Registration Holes:** 2 rows of 8 holes ($\varnothing 1.50\text{mm} \times 2.00\text{mm}$ deep, $2.54\text{mm} / 0.10\text{″}$ pitch).
  * **Rear Mechanical Thrust Stop:** $+X$ end stop block ($2.50\text{mm} \times 18.40\text{mm} \times 5.50\text{mm}$) absorbing Type-C insertion force.

---

### 5. View D: Two-Tier Desk Stand & 22° V-Saddle
* **Base Footprint (Tier 1):** $64.00\text{mm} \times 68.00\text{mm} \times 6.00\text{mm}$ with $R = 6.00\text{mm}$ rounded corners.
* **Pyramidal Trunk (Tier 2):** Height $28.00\text{mm}$, tapering from $58\text{mm} \times 58\text{mm}$ to $54\text{mm} \times 54\text{mm}$ top.
* **Ergonomic Cradle Tilt Angle:** $22.00^\circ$ backward incline.
* **V-Saddle Pocket Dimensions:** Octagonal cutout $54.80\text{mm} \times 40.00\text{mm} \times 6.20\text{mm}$ chamfer.
* **Rear Cable Pass-Through Channel:** $16.00\text{mm}$ wide $\times 14.00\text{mm}$ tall.
* **Underside Anti-Slip Foot Recesses:** 4 Pockets $\varnothing 8.20\text{mm} \times 1.40\text{mm}$ deep at $(X, Y) = (\pm 22.00\text{mm}, \pm 24.00\text{mm})$.

---

## 🛠️ Recommended CAD Reconstruction Steps (Fusion 360 / SolidWorks / FreeCAD)

```mermaid
graph TD
    A[1. Base Octagon Sketch: 54x54mm with 6mm Chamfers] --> B[2. Extrude Main Housing: 31.5mm Depth]
    B --> C[3. Shell / Pocket Internal Cavity: 44x44x29.5mm]
    C --> D[4. Front GC9A01 Blueprint Pocket: 38.6mm Dia + 23.6mm Tab]
    D --> E[5. Cut Left USB-C Slot: 13x8mm Oval]
    E --> F[6. Add ESP32 Pin-Locking Standoff Rails & Thrust Stop]
    F --> G[7. Drill 4 Corner M2 Pilot Holes: 42mm Pitch x 14mm Deep]
    
    H[8. Front Bezel Sketch: 54x54mm Octagon] --> I[9. Extrude Bezel Base: 4.5mm + 1.5mm Visor Ring]
    I --> J[10. Cut Active Window: 32.6mm Dia + 45° Chamfer]
    J --> K[11. Step Glass Pocket: 36.0mm Dia x 1.6mm Deep]
    K --> L[12. Drill 4 M2 Counterbore Holes & 2 Screen Tab Pilots]
```

---

## 🔩 Hardware Fastener & Bill of Materials Table

| Ref | Component | Spec / Dimensions | Qty | Mounting Location |
| :---: | :--- | :--- | :---: | :--- |
| **1** | GC9A01 LCD Module | 1.28″ Round IPS SPI ($240\times 240$) | 1 | Front stepped pocket |
| **2** | ESP32-C3 SuperMini | RISC-V 160MHz MCU with USB-C | 1 | Internal bottom rails |
| **3** | Bezel Fastening Screws | $\text{M2} \times 14\text{mm}$ Socket Cap (Brass) | 4 | Corner holes into housing |
| **4** | Threaded Heat-Set Inserts | $\text{M2} \times 3.5\text{mm}$ Brass Inserts | 4 | Housing corner posts |
| **5** | Display Tab Screws | $\text{M2} \times 4\text{mm}$ Self-tapping or Machine | 2 | Bezel rear tab pilots |
| **6** | Wiring Harness | 7-Pin Female-to-Female DuPont ($10\text{cm}$) | 7 | SPI internal loop |
| **7** | Anti-Slip Desk Bumpers | $\varnothing 8.0\text{mm} \times 1.5\text{mm}$ Silicone/Rubber | 4 | Base plate underside pockets |
| **8** | USB Power Cable | USB-C Right-Angle or Braided Type-C | 1 | Left-side port routing |

---

## 🖨️ FDM 3D Printing Guidelines

* **No Supports Required:**
  * **Front Bezel:** Print face-down on smooth/textured PEI sheet.
  * **Main Housing:** Print with rear face flat on build plate (open pocket facing $+Z$).
  * **Desk Stand:** Print base-down with V-saddle pointing up.
* **Filament Recommendation:** Matte Charcoal Black PLA / PETG (body) + Walnut Wood PLA (Tier 1 base plate).

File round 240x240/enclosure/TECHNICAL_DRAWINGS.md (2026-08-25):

# 📐 GC9A01 Cyberdeck Enclosure - Mechanical Engineering Technical Drawings

Comprehensive mechanical engineering drawing sheets and dimensional specifications for CAD modeling (Fusion 360, FreeCAD, SolidWorks, Blender, Onshape, Rhino).

---

## 📑 Drawing Sheets Overview

### 1. Sheet 1: Front Bezel Display Carrier (`GC9A01-BEZEL-01`)
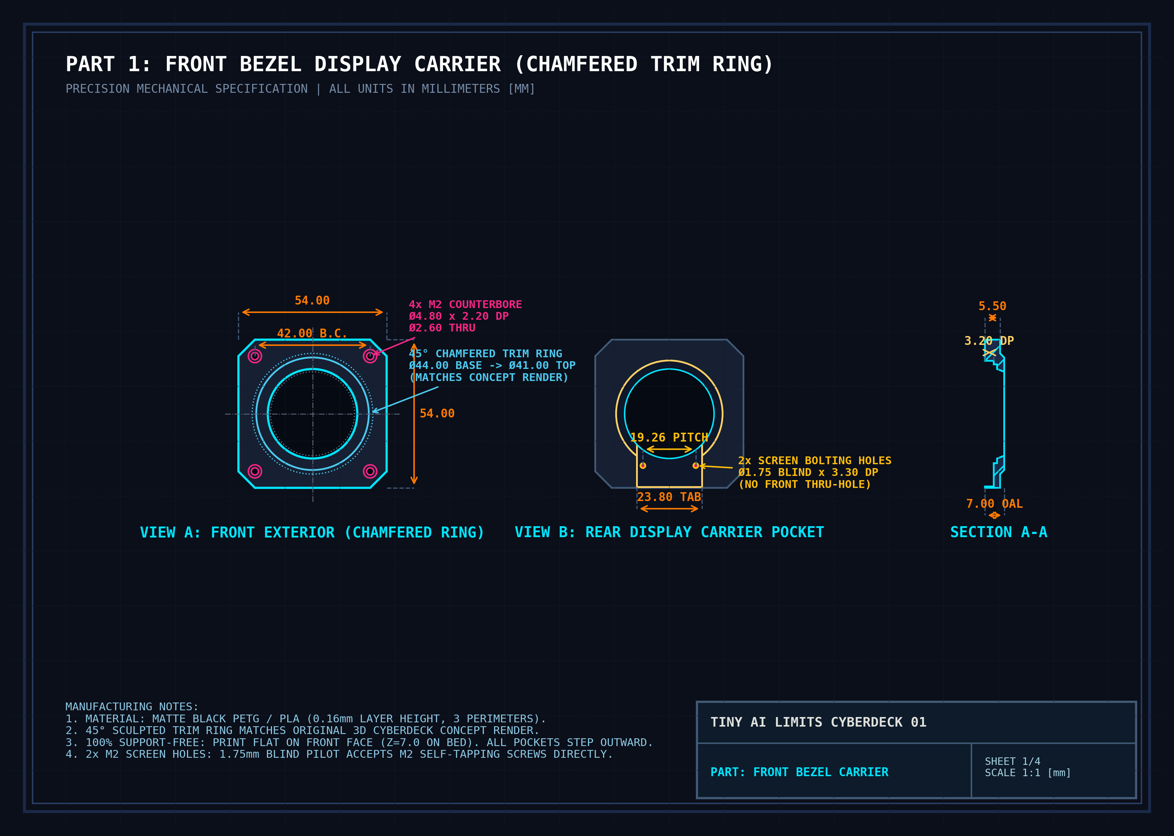
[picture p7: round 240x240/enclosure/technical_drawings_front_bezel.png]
Sheet 1: Front Bezel Plate


* **Function:** Precision carrier holding the display glass, PCB, and retaining screws flush.
* **Outer Profile:** $54.00\text{mm} \times 54.00\text{mm}$ with $6.00\text{mm} \times 45^\circ$ corner chamfers.
* **Plate Thickness:** $5.50\text{mm}$ carrier body $+ 1.50\text{mm}$ raised decorative trim ring ($\varnothing 44.00\text{mm}$) = $7.00\text{mm}$ Overall Length (OAL).
* **Active Screen Viewport:** $\varnothing 33.00\text{mm}$ through-hole with $36.4^\circ$ inner bevel ring (aperture dia $\varnothing 38.60\text{mm}$).
* **Glass Lens Retention Step:** $\varnothing 36.40\text{mm} \times 1.80\text{mm}$ deep (from rear, $+0.80\text{mm}$ clearance).
* **Full PCB Retention Pocket:** $\varnothing 39.00\text{mm}$ circular top $+ 24.00\text{mm}$ wide bottom tab down to $Y = -26.60\text{mm}$ ($3.30\text{mm}$ deep into bezel from rear, $+1.00\text{mm}$ tolerance, straight cylinder).
* **Top Relief Notch:** $18.00\text{mm} \text{ wide} \times 23.00\text{mm} \text{ height}$ extended clearance for top solder/ribbon overhang.
* **Reverse Catch Detents:** $4 \times$ discrete $0.35\text{mm}$ forward-locking shelves at rear pocket entrance ($Z = 1.1\text{mm}$) locking the PCB forward against the front stop.
* **Screen Bolting Pilot Holes:** $2 \times \varnothing 1.75\text{mm}$ blind pilot holes at $X = \pm 9.63\text{mm}, Y = -18.91\text{mm}$ ($19.26\text{mm}$ pitch), depth $3.30\text{mm}$ from rear (leaves solid front face).

* **Corner Enclosure Screws:** $4 \times$ M2 through-holes ($\varnothing 2.60\text{mm}$) with counterbore pockets ($\varnothing 4.80\text{mm} \times 2.20\text{mm}$ deep) at $X = \pm 21.00\text{mm}, Y = \pm 21.00\text{mm}$ ($42.00\text{mm}$ Bolt Circle).
* **3D Print Orientation:** Print flat on front face ($Z = 7.0\text{mm}$ on bed). **Zero supports required.**

---

### 2. Sheet 2: Main Housing Pod (Open Tub - 100% Support-Free) (`GC9A01-BODY-26`)
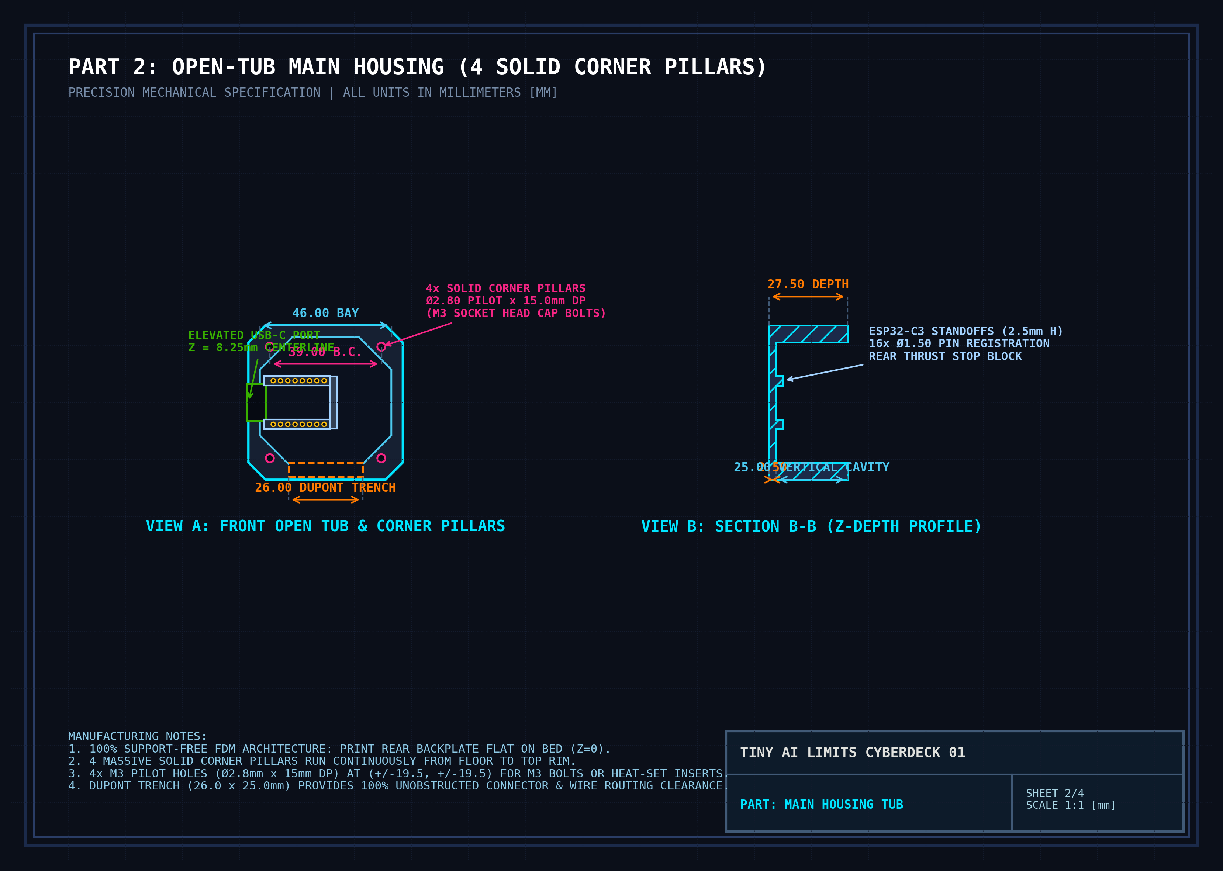
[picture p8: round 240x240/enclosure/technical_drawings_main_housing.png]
Sheet 2: Main Housing Pod


* **Function:** Open electronics bucket with continuous vertical walls and zero mid-air ceilings.
* **Outer Profile:** $54.00\text{mm} \times 54.00\text{mm} \times 27.50\text{mm}$ depth with $6.00\text{mm} \times 45^\circ$ corner chamfers.
* **Solid Enclosed Bottom Wall:** 100% continuous, solid outer perimeter walls (zero exterior bottom slits or holes).
* **Electronics & Wire Cavity:** $46.00\text{mm} \times 46.00\text{mm} \times 25.00\text{mm}$ continuous vertical open tub from floor ($Z = 2.5\text{mm}$) to top rim ($Z = 27.5\text{mm}$).
* **Corner Screw Pillars:** $4 \times$ solid pillars running from floor to rim with $\varnothing 2.80\text{mm} \times 15.00\text{mm}$ pilot holes at $X = \pm 19.50\text{mm}, Y = \pm 19.50\text{mm}$ ($39.00\text{mm}$ Bolt Circle) for M3 screws or heat-set brass inserts.
* **DuPont Connector & Wire Trench:** $26.00\text{mm} \text{ wide} \times 5.00\text{mm} \text{ deep}$ internal trench ($Y = -21.00\text{mm} \to -26.00\text{mm}$) running full depth ($25.00\text{mm}$), keeping a solid $1.00\text{mm}$ outer bottom wall.
* **Elevated USB-C Port:** Precision oval cutout with $45^\circ$ lead-in chamfer centered at $Z = 8.25\text{mm}$ on left wall at $X = -27.00\text{mm}$.
* **ESP32-C3 SuperMini Mounting:**
  * Standoff rails at $Y = \pm 7.62\text{mm}$ ($0.6''$ pin row spacing), height $2.50\text{mm}$.
  * $16 \times \varnothing 1.50\text{mm}$ blind pin-registration holes ($2.00\text{mm}$ deep) at $2.54\text{mm}$ pitch along $X$.
  * Rear mechanical thrust stop block ($2.50\text{mm}$ thick) at $+X$ end.
* **3D Print Orientation:** Print flat on rear backplate ($Z = 0$ on bed). **Zero supports required.**

---

### 3. Sheet 3: Sculpted Two-Tier Desk Stand (`GC9A01-STAND-01`)
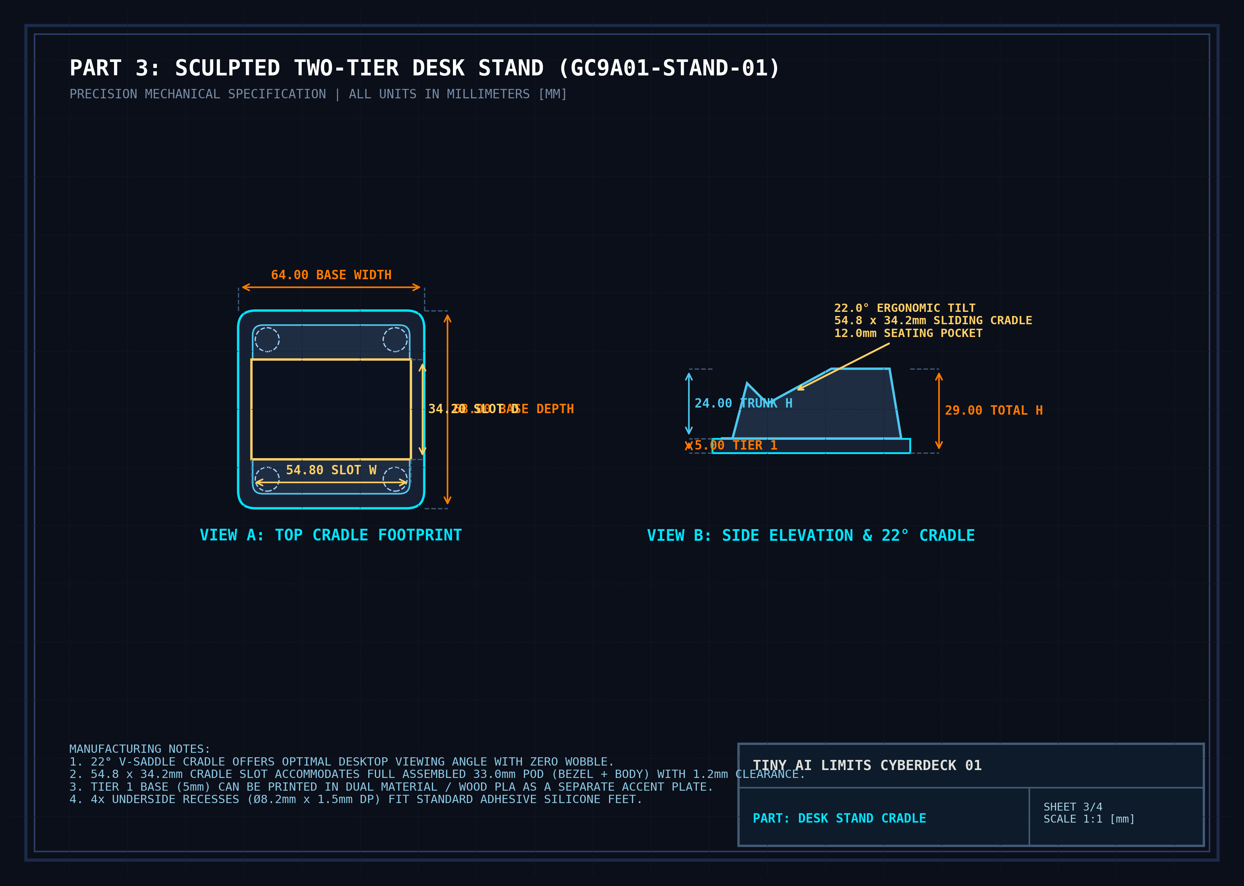
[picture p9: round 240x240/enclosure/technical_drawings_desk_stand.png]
Sheet 3: Sculpted Desk Stand


* **Tier 1 Base Plate:** $64.00\text{mm} \text{ wide} \times 68.00\text{mm} \text{ deep} \times 5.00\text{mm} \text{ height}$ with $R = 6.00\text{mm}$ rounded corners and $4 \times$ upward alignment pins ($\varnothing 5.00\text{mm} \times 3.50\text{mm}$).
* **Tier 2 Pyramidal Trunk:** $24.00\text{mm}$ height ($62.0\times 66.0\text{mm}$ base tapering to $54.0\times 58.0\text{mm}$ top) for a $29.00\text{mm}$ total stand height.
* **Cradle Sliding Slot:** $54.80\text{mm} \text{ wide} \times 34.20\text{mm} \text{ depth} \times 12.00\text{mm} \text{ seating pocket}$ at an ergonomic **$22.0^\circ$ backward tilt**, accommodating the full $33.00\text{mm}$ assembled pod (housing + bezel) with $1.20\text{mm}$ smooth slide clearance.
* **Anti-Slip Rubber Foot Recesses:** $4 \times \varnothing 8.20\text{mm} \times 1.50\text{mm}$ deep on underside ($X = \pm 22.00\text{mm}, Y = \pm 24.00\text{mm}$).

---

### 4. Sheet 4: Exploded System Assembly & Hardware BOM
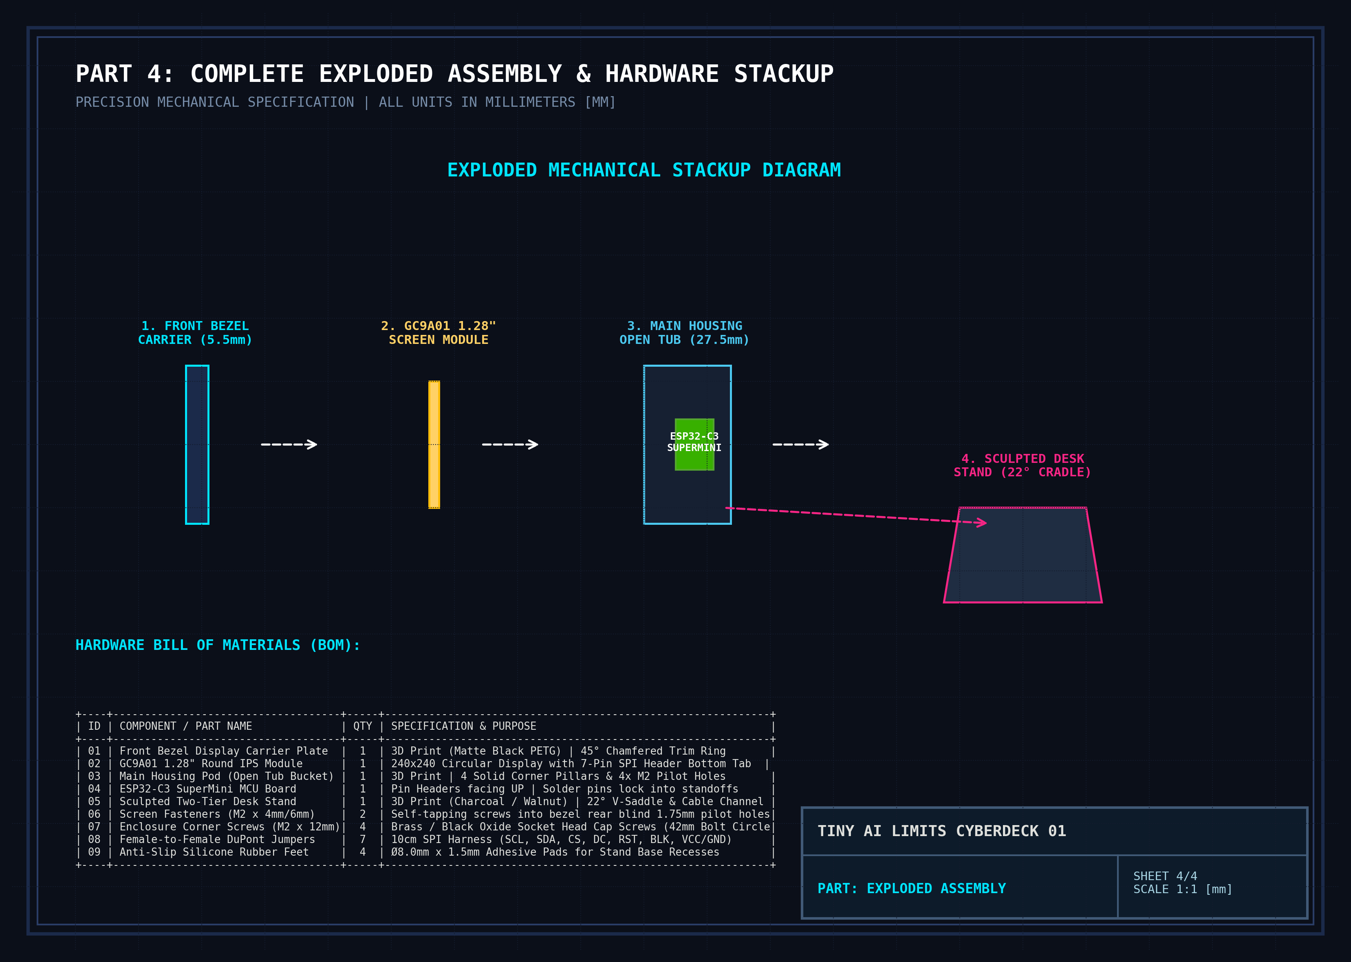
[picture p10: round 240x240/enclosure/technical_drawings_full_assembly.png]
Sheet 4: Exploded Assembly & BOM


* **Stackup Sequence:**
  1. Front Bezel Display Carrier ($5.50\text{mm}$)
  2. GC9A01 1.28″ Round Display Module ($3.10\text{mm}$) — fastened to bezel with $2 \times$ M2 screws
  3. Main Housing Pod Open Tub ($27.50\text{mm}$) with ESP32-C3 SuperMini inside
  4. Sculpted Two-Tier Desk Stand ($29.00\text{mm}$)
* **Hardware BOM:**
  * $2 \times \text{M2} \times 4\text{mm} / 6\text{mm}$ pan/socket screws (screen to bezel)
  * $4 \times \text{M3} \times 12\text{mm} / 16\text{mm}$ socket head cap screws (bezel to housing)
  * $4 \times \varnothing 8.0\text{mm}$ adhesive rubber feet
  * $7 \times 10\text{cm}$ female-to-female DuPont jumper wires

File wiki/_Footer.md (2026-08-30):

---
*Tiny AI Limits Wiki — Open-source physical desktop companion for autonomous AI coding agents.*  
*Maintained with ❤️ by the Tiny AI Limits Community.*

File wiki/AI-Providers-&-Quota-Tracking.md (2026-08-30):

# 🤖 AI Providers & Quota Tracking

**Tiny AI Limits** includes modular provider adapters capable of parsing local agent session transcripts, reading statusline hooks, or querying cloud model management APIs.

---

## 📋 Supported Providers Matrix

| Provider Identifier | Service Name | Data Source / Mechanism | Supported Modes |
| :--- | :--- | :--- | :--- |
| **`claude`** | Anthropic Claude | Claude Code session transcripts & statusline | Standard (5h Reset) / Enterprise |
| **`antigravity`** | Google Antigravity | Antigravity engine telemetry & token logs | Standard / Enterprise |
| **`openrouter`** | OpenRouter.ai | Cloud `/api/v1/auth/key` endpoint | Enterprise (\$ Spend & Credits) |
| **`deepseek`** | DeepSeek | Cloud `/user/balance` API | Enterprise (\$ Spend & Tokens) |
| **`groq`** | Groq Cloud | Cloud rate limits & token analytics | Standard / Enterprise |
| **`mistral`** | Mistral AI | Cloud usage analytics API | Standard / Enterprise |
| **`copilot`** | GitHub Copilot | Local editor session telemetry | Standard (% Quota) |
| **`cursor`** | Cursor IDE | Local composer session transcripts | Standard (% Quota) |
| **`gemini`** | Google Gemini API | Cloud Generative Language API | Standard / Enterprise |
| **`codex`** | OpenAI Codex / GPT-4o | Usage & Billing API | Enterprise (\$ Spend) |

---

## ⚙️ Gauge Modes: Standard vs. Enterprise

Each of the two radial arcs (Left Gauge and Right Gauge) can be independently configured in either of two operating modes:

```
    STANDARD QUOTA MODE                     ENTERPRISE SPEND MODE
 ╭─────────────────────────╮             ╭─────────────────────────╮
 │     [CLAUDE CODE]       │             │      [ANTIGRAVITY]      │
 │                         │             │                         │
 │        84.5%            │             │         $0.13           │
 │      REMAINING          │             │       SPEND TODAY       │
 │                         │             │                         │
 │     Resets: 4h 32m      │             │      28.2k TOKENS       │
 ╰─────────────────────────╯             ╰─────────────────────────╯
```

### 1. Standard Quota Mode
* **Target Users:** Claude Pro, Claude Team, Antigravity standard plans with 5-hour sliding-window quotas.
* **Corridor Center:** Displays remaining quota percentage (`84.5%`).
* **Footer:** Displays active countdown until the current rolling 5-hour quota window resets (`4h 32m`).
* **Radial Arc Sweep:** Tracks remaining quota from $100\%$ down to $0\%$.

### 2. Enterprise / Pay-As-You-Go Mode
* **Target Users:** Enterprise accounts, pay-as-you-go API keys (OpenRouter, DeepSeek, Groq, Mistral).
* **Corridor Center:** Displays today's live dollar spend in **`$`** (e.g. `$0.13`).
* **Footer:** Displays total 24-hour token consumption (e.g. `28.2k TOK`).
* **Radial Arc Sweep:** Fills upward against your user-defined **Daily Budget ($ USD)**.

---

## 🔑 Provider Configuration Guide

### 1. Anthropic Claude (Claude Code)
Claude Code stores real-time session transcripts and usage metrics locally on your machine.
* **Automatic Detection:** The companion app automatically detects Claude Code statusline files at `~/.claude/` or active shell hooks.
* **No API Key Required:** Runs 100% locally from your local CLI session.

### 2. Google Antigravity
The companion connects directly to the local Antigravity daemon and workspace transcripts to calculate real-time token utilization and active subagent states.

### 3. OpenRouter.ai
1. Generate an API Key at [openrouter.ai/keys](https://openrouter.ai/keys).
2. Open `http://localhost:5000/setup`.
3. In the **Cloud API Keys** accordion, paste your key into the **OpenRouter API Key** field.
4. Click **Save Settings**.

### 4. DeepSeek, Groq, and Mistral
1. Acquire your API keys from their respective developer dashboards.
2. Enter them into the configuration UI at `http://localhost:5000/setup`.
3. The companion service will automatically query token usage and account balances on a 60-second polling cycle.

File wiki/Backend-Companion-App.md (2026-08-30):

# 🐍 Backend Companion App & Server Architecture

The **Tiny AI Limits** companion application is a lightweight Python service built on **Flask** and **Zeroconf**. It runs locally on your workstation, continuously aggregating agent state telemetry, monitoring quota budgets, fetching local weather forecasts, and serving a high-performance REST API to paired hardware displays.

---

## 🏛️ System Architecture

```
 ┌────────────────────────────────────────────────────────────────────────┐
 │                      Host Workstation (Python 3.10+)                    │
 │                                                                        │
 │  ┌─────────────────────────┐         ┌──────────────────────────────┐  │
 │  │   AI Agent Transcripts  │         │    Cloud Provider APIs       │  │
 │  │  (Claude Code / AGY)    │         │ (OpenRouter / DeepSeek / etc)│  │
 │  └────────────┬────────────┘         └──────────────┬───────────────┘  │
 │               │                                     │                  │
 │               ▼                                     ▼                  │
 │  ┌──────────────────────────────────────────────────────────────────┐  │
 │  │                 Provider Adapter Engine (providers/)             │  │
 │  │        Standard 5h Reset Calculator  |  Spend & Token Aggregator  │  │
 │  └──────────────────────────────────┬───────────────────────────────┘  │
 │                                     │                                  │
 │                                     ▼                                  │
 │  ┌──────────────────────────────────────────────────────────────────┐  │
 │  │                         Flask REST Service                       │  │
 │  │                                                                  │  │
 │  │   /api/limits      /api/pairing      /setup      /emulator        │  │
 │  └────────────┬─────────────────────────────────────────────────────┘  │
 │               │                                                        │
 │               ▼                                                        │
 │  ┌─────────────────────────┐                                           │
 │  │    mDNS Zeroconf Daemon │ ──> Advertises _tinyscreen._tcp.local.     │
 │  │   (Broadcasts pair_id)  │     with host IP & TXT record             │
 │  └─────────────────────────┘                                           │
 └────────────────────────────────────────────────────────────────────────┘
```

---

## 🌐 REST API Endpoints

### 1. `GET /api/limits`
The primary telemetry payload polled by both physical displays and the browser emulator.

#### Example JSON Response
```json
{
  "status": "ok",
  "pair_id": "e83f12a9-c091-49b8-a726-0e7841c5d98a",
  "left_gauge": {
    "provider": "claude",
    "name": "Claude 3.7 Sonnet",
    "percent_remaining": 84.5,
    "reset_in_seconds": 16320,
    "reset_formatted": "4h 32m",
    "mode": "standard",
    "status": "healthy"
  },
  "right_gauge": {
    "provider": "antigravity",
    "name": "Google Antigravity",
    "spend_usd": 0.13,
    "budget_usd": 5.00,
    "tokens_24h": 28240,
    "tokens_formatted": "28.2k",
    "percent_used": 2.6,
    "mode": "enterprise",
    "status": "healthy"
  },
  "agents": [
    {
      "id": "agent-1",
      "name": "CAD Specialist",
      "state": "WORKING",
      "requires_approval": false,
      "updated_at": 1740000000
    },
    {
      "id": "agent-2",
      "name": "Firmware Architect",
      "state": "WAITING",
      "requires_approval": true,
      "updated_at": 1740000010
    },
    {
      "id": "agent-3",
      "name": "QA Tester",
      "state": "COMPLETE",
      "requires_approval": false,
      "updated_at": 1740000020
    }
  ],
  "weather": {
    "temperature_c": 21.5,
    "weather_code": 0,
    "condition": "Clear Sky",
    "precipitation_probability": 0,
    "is_day": 1
  }
}
```

### 2. `POST /api/pairing`
Handles browser pairing requests and manual IP pinning.
* **Payload:** `{"pair_id": "UUID", "device_ip": "192.168.1.150"}`
* **Response:** `{"status": "paired", "message": "Device successfully registered"}`

### 3. `GET /api/weather`
Returns standalone meteorological data calculated from Open-Meteo's non-commercial geocoded API.

---

## 📡 Zero-Config mDNS Discovery

The companion backend automatically starts a Zeroconf service daemon advertising on the local network:

```python
from zeroconf import ServiceInfo, Zeroconf

desc = {
    b'pair_id': current_pair_id.encode('utf-8'),
    b'version': b'2.0.0',
    b'port': b'5000'
}

info = ServiceInfo(
    "_tinyscreen._tcp.local.",
    f"TinyScreen-{hostname}._tinyscreen._tcp.local.",
    addresses=[socket.inet_aton(local_ip)],
    port=5000,
    properties=desc
)

zeroconf.register_service(info)
```

When an ESP32 boots, it scans for `_tinyscreen._tcp` services, inspects the `pair_id` property in the TXT record, and immediately resolves the host's IP address without requiring hardcoded network settings.

---

## 📁 Configuration File (`~/.tiny_ai_screen/config.json`)

User configurations, provider API keys, and paired hardware UUIDs are stored in your home directory:

```json
{
  "pair_id": "e83f12a9-c091-49b8-a726-0e7841c5d98a",
  "left_provider": "claude",
  "left_mode": "standard",
  "right_provider": "antigravity",
  "right_mode": "enterprise",
  "daily_budget_usd": 5.00,
  "weather": {
    "enabled": true,
    "latitude": 37.7749,
    "longitude": -122.4194
  },
  "api_keys": {
    "openrouter": "sk-or-v1-...",
    "deepseek": "sk-...",
    "groq": "gsk_...",
    "mistral": "..."
  }
}
```

---

## 🧪 Automated Testing & QA

The backend features a comprehensive `pytest` test suite with 100% endpoint coverage:

```bash
# Run backend test suite
pytest backend/tests/ -v

# Run with test coverage report
pytest --cov=backend backend/tests/
```

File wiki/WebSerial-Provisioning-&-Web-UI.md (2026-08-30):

# 🌐 WebSerial Provisioning & Web UI

**Tiny AI Limits** provides a browser-based management and emulation suite accessible at `http://localhost:5000`. It features zero-install **WebSerial API** USB provisioning, live gauge configuration, and a full-fidelity HTML5 Canvas hardware emulator.

---

## ⚡ WebSerial USB Provisioning Interface (`/setup`)

Built using the modern W3C **WebSerial API**, the setup interface enables direct bidirectional serial communication between Google Chrome / Microsoft Edge and the ESP32-C3 microcontroller over standard USB-C without requiring external driver installations or CLI flashing tools.

```
 ┌────────────────────────────────────────────────────────────────────────┐
 │                    TINY AI SCREEN - DEVICE SETUP                       │
 │                                                                        │
 │  ┌──────────────────────────────────────────────────────────────────┐  │
 │  │ 🔌 STEP 1: CONNECT & PROVISION VIA SERIAL                        │  │
 │  │                                                                  │  │
 │  │   [ Connect Board (Direct Serial Setup) ]                         │  │
 │  │                                                                  │  │
 │  │   SSID: [ MyOfficeWiFi          ]                                │  │
 │  │   PASS: [ •••••••••••••••••     ]                                │  │
 │  │                                                                  │  │
 │  │   [ CONFIGURE & PAIR TO THIS HOST ]                              │  │
 │  └──────────────────────────────────────────────────────────────────┘  │
 │                                                                        │
 │  ┌──────────────────────────────────────────────────────────────────┐  │
 │  │ 🎛️ STEP 2: DUAL HUD GAUGE CUSTOMIZER                             │  │
 │  │                                                                  │  │
 │  │   LEFT GAUGE:   [ Anthropic Claude   ▼ ]   MODE: (•) 5h Reset    │  │
 │  │   RIGHT GAUGE:  [ Google Antigravity ▼ ]   MODE: (•) Spend ($)   │  │
 │  │                                                                  │  │
 │  │   DAILY BUDGET ($ USD): [   5.00 ]                               │  │
 │  └──────────────────────────────────────────────────────────────────┘  │
 └────────────────────────────────────────────────────────────────────────┘
```

### Key Features of `/setup`:
* **Direct Serial Protocol:** Sends `WIFI:<ssid>:<pass>:<pair_id>` strings directly over the WebSerial text stream.
* **Improv Wi-Fi Compatibility:** Full fallback support for the standardized Improv-WiFi BLE/Serial protocol.
* **Live Configuration Sync:** Changes made to gauge providers or daily budget limits are immediately saved to `~/.tiny_ai_screen/config.json` and pushed to the display.
* **Collapsible Cloud API Keys:** Clean, secure accordions for entering OpenRouter, DeepSeek, Groq, and Mistral API keys with local encryption.

---

## 🖥️ Full Display Browser Emulator (`/emulator`)

The project includes an interactive 60 FPS HTML5 Canvas visualizer that faithfully reproduces all graphics routines, radial math, mascot animations, and alert states of the physical circular display.

```
                       ╭────────────────────────╮
                     ╭─╯        21.5°C          ╰─╮
                    ╭╯      CLEAR SKY (0% RAIN)   ╰╮
                   ╭╯                              ╰╮
                   │  [CLAUDE]           [AGY]      │
                   │   84.5%             $0.13      │
                   │  REMAINING         SPEND TODAY │
                   │  (4h 32m)          (28.2k TOK) │
                   │ ────────────────────────────── │
                   │ AGENT 1: CAD SPECIALIST (WORK) │
                   │ AGENT 2: ARCHITECT     (WAIT)  │
                   │ AGENT 3: QA TESTER     (DONE)  │
                   ╰╮                              ╭╯
                    ╰╮     PULSING GREEN CROWN    ╭╯
                     ╰─╮   (PAIRED & ACTIVE)    ╭─╯
                       ╰────────────────────────╯
```

### Capabilities of the Browser Visualizer:
1. **Live Data Binding:** Polls `/api/limits` in real time, reflecting exactly what the physical hardware renders.
2. **State Simulation Controls:** Test suite toolbar to inject mock states, trigger agent approval warnings, simulate network disconnections, and test weather forecast transitions.
3. **Circular Anti-Aliasing:** Replicates the 240×240 pixel circular boundary mask and pixel aspect ratio of the GC9A01 panel.
4. **Development Sandboxing:** Perfect for designing new UI widgets, mascot animations, or themes without needing hardware connected.

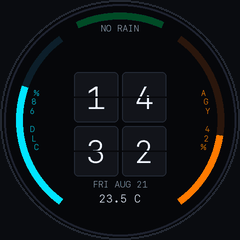
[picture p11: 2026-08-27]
docs/assets/concepts/concept_b_breathing_glow.gif

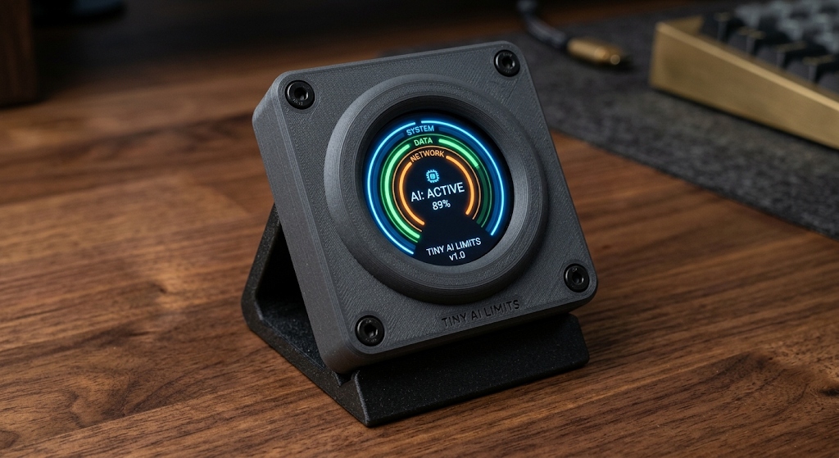
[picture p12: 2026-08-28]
docs/assets/concepts/minimalist_desk_stand_reference.jpg

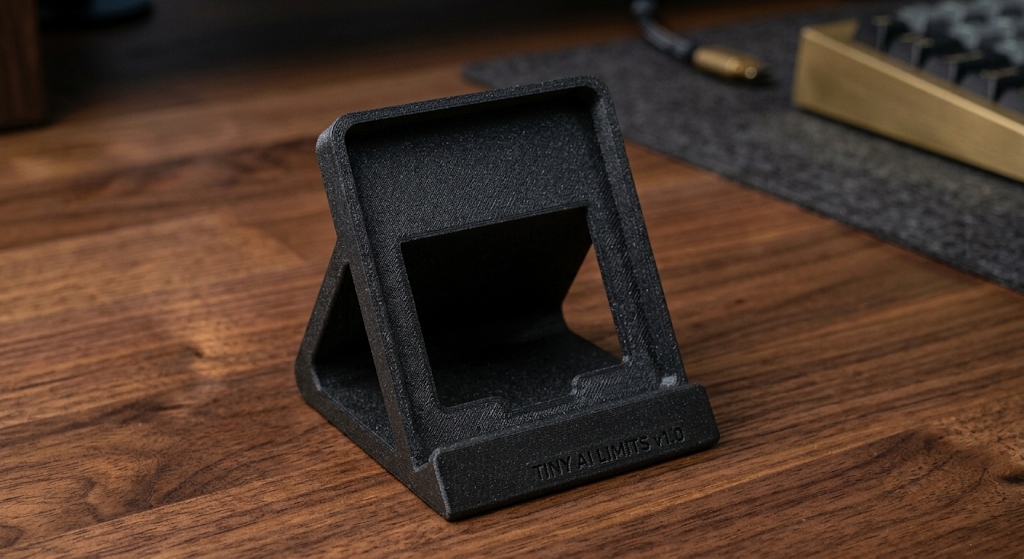
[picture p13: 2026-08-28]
docs/assets/concepts/stand_empty_reference.jpg

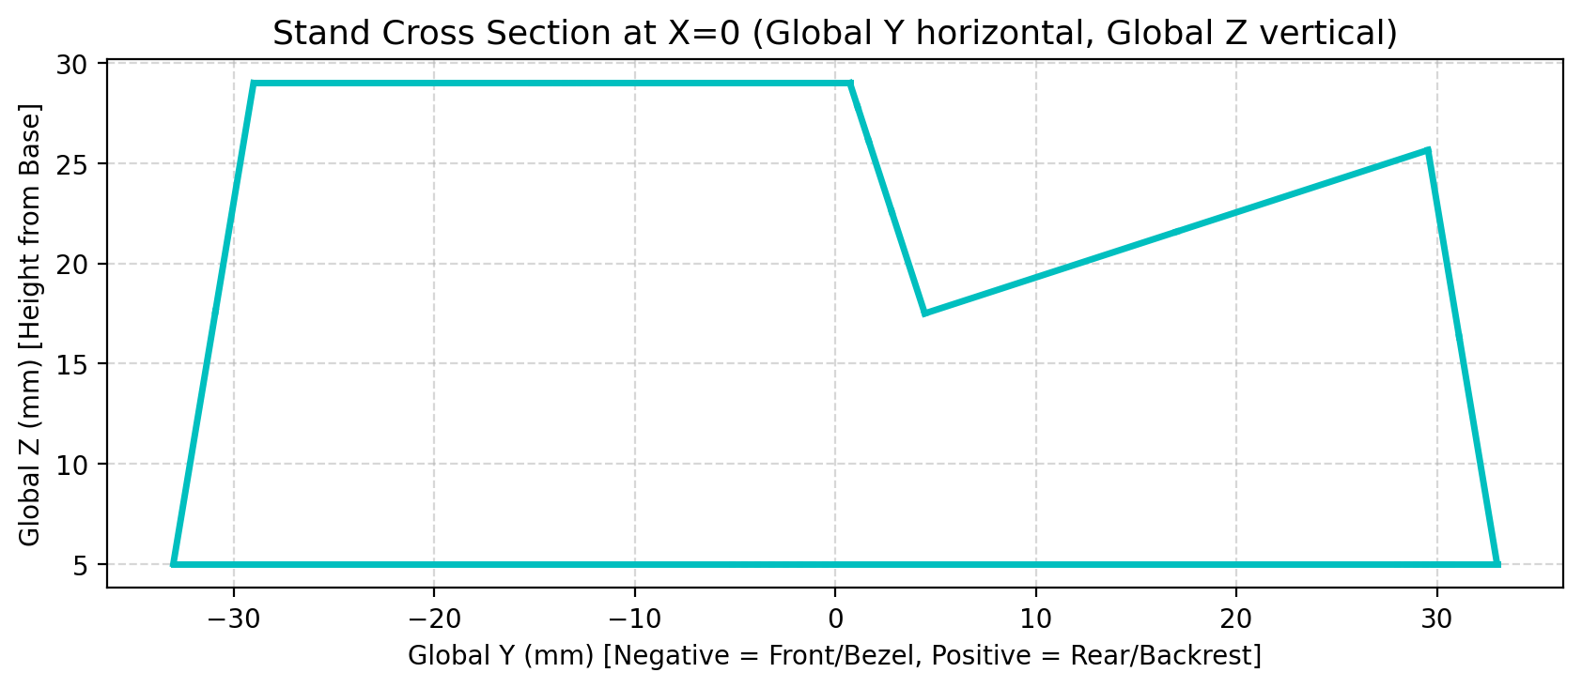
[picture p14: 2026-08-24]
docs/assets/round/stand_cross_section.png

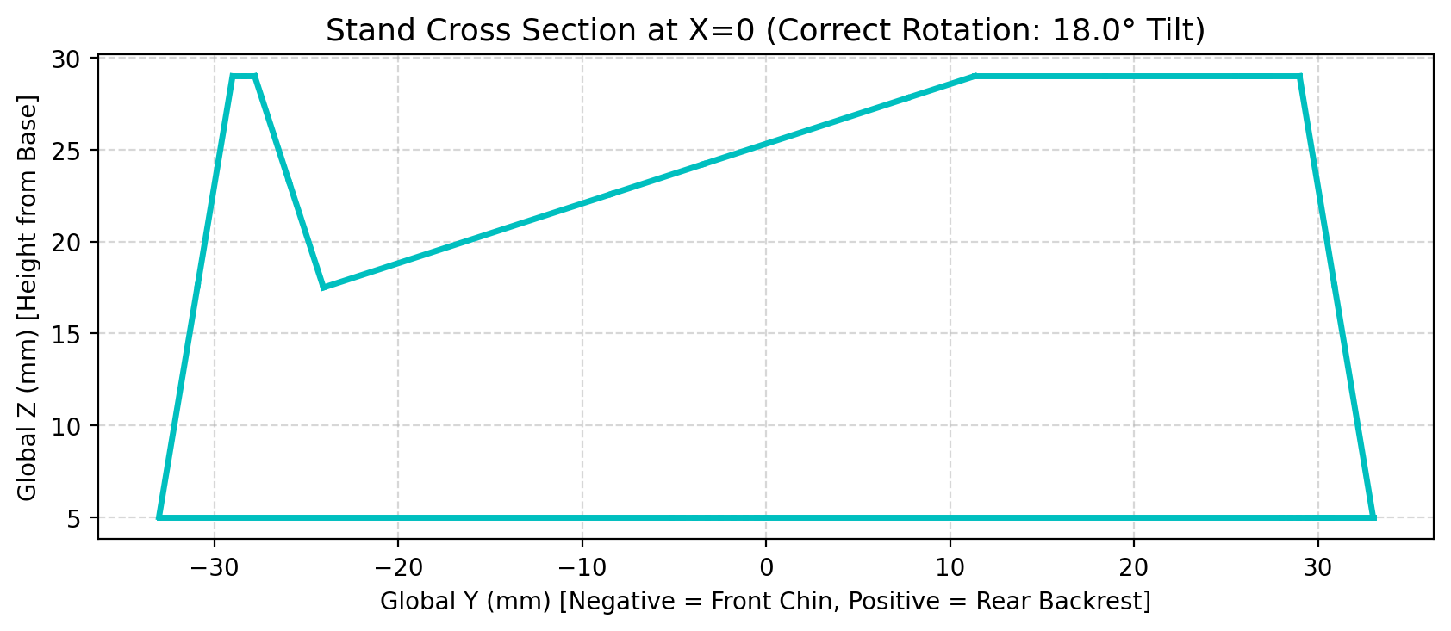
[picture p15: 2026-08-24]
docs/assets/round/stand_cross_section_corrected.png

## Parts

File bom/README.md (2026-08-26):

# 🛒 Bill of Materials (BOM) & Purchasing Guide

Welcome to the hardware sourcing guide for **Tiny AI Limits & Desktop Companion**!

This guide lists all the electronic components, hardware fasteners, wiring, and 3D printing supplies needed to assemble your device, along with verified purchasing links across global retailers (**Amazon US/EU**, **AliExpress**, **Waveshare**, and **Adafruit**).

---

## 📦 Quick-Start Shopping Kit

Everything you need for one complete build:

```mermaid
graph TD
    A["GC9A01 Round Cyberdeck Build"] --> B["ESP32-C3 SuperMini (~$3.00)<br>1.28' GC9A01 IPS Screen (~$4.50)<br>4x M3x16mm Socket Screws (~$1.00)<br>4x DuPont/Silicone Wires (~$0.50)"]
    B --> C["Total Estimated Cost: ~$9.00 - $15.00"]
```

---

## 📋 Comprehensive Parts List

For full part numbers, direct links, and component notes, see the dedicated [**`BOM.md`**](./BOM.md) file.

### 1.28" Circular IPS Cyberdeck Edition

| Component | Quantity | Key Spec | Estimated Price |
| :--- | :---: | :--- | :---: |
| **ESP32-C3 SuperMini** | 1 | USB-C, RISC-V, Wi-Fi 4 + BLE 5, 3.3V | $2.50 – $4.00 |
| **GC9A01 1.28" Round IPS LCD** | 1 | 240×240 SPI (8-pin or 7-pin header) | $3.80 – $6.00 |
| **M3 × 16mm Socket Head Screws** | 4 | Brass or Black Oxide Stainless Steel | $1.00 |
| **Hookup Wires / DuPont Jumpers** | 7–8 | 28/30 AWG flexible silicone (10cm) | $0.50 |
| **Rubber Bumper Feet** | 4 | 6mm–8mm self-adhesive silicone pads | $0.50 |
| **USB-C Data Cable** | 1 | USB-A to USB-C or USB-C to USB-C | Existing / $2.00 |

---

## 🖨️ 3D Printing Materials

* **Main Enclosure & Stand Trunk:** Matte Charcoal, Gunmetal Gray, or Galaxy Black PLA / PETG / ABS.
* **Tier 1 Stand Base Plate (Optional):** Wood PLA (Dark Walnut or Pine) for an organic contrast finish, or standard Black PLA.
* **Slicer Settings:**
  * Layer Height: `0.16mm` or `0.20mm`
  * Infill: `15% - 20%` (Gyroid or Grid)
  * Supports: **None needed** (all models designed 100% support-free with 45° self-supporting chamfers)

---

## 🛠️ Recommended Tools

* 2.5mm Hex / Allen Key (for M3 socket head screws)
* Soldering iron (only needed if your ESP32-C3 or display module ships without pre-soldered header pins)
* Wire stripper / snips (if using bare silicone hookup wire)

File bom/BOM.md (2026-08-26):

# 📋 Bill of Materials (BOM) — Tiny AI Limits

Complete component specifications and verified purchasing links for building the **Tiny AI Limits & Desktop Companion**.

---

## ⚡ Core Electronics

### 1. ESP32-C3 SuperMini Microcontroller (Required)
* **Description:** Ultra-compact development board featuring the Espressif ESP32-C3 RISC-V 32-bit single-core SoC (160 MHz), built-in 2.4 GHz Wi-Fi 4 & Bluetooth 5 (LE), 400KB SRAM, 4MB Flash, and native USB-C.
* **Dimensions:** 22.5 mm × 18 mm × 4 mm
* **Quantity:** 1
* **Purchasing Links:**
  * [AliExpress (ESP32-C3 SuperMini ~ $2.50)](https://www.aliexpress.com/w/wholesale-ESP32-C3-SuperMini.html)
  * [Amazon US (ESP32-C3 SuperMini 3-Pack ~ $12.99)](https://www.amazon.com/s?k=esp32-c3+supermini)
  * [Amazon EU/DE (ESP32-C3 SuperMini ~ €4.50)](https://www.amazon.de/s?k=esp32-c3+supermini)

---

### 2. Display: GC9A01 1.28" Circular IPS Color LCD (240×240)
* **Description:** 1.28-inch round full-color IPS TFT LCD screen module with GC9A01 controller, SPI 4-wire interface, 240×240 resolution, 65K RGB colors, and 3.3V logic level.
* **Header Pins:** 8-pin or 7-pin header (`VCC`, `GND`, `SCL`, `SDA`, `DC`, `CS`, `RST`, `BLK`).
* **Quantity:** 1
* **Purchasing Links:**
  * [Waveshare 1.28" Round LCD Module (Official ~ $7.99)](https://www.waveshare.com/1.28inch-touch-lcd-240x240.htm)
  * [AliExpress (GC9A01 1.28" Round Display ~ $3.80)](https://www.aliexpress.com/w/wholesale-GC9A01-1.28-inch-round-lcd.html)
  * [Amazon US (GC9A01 1.28" Round SPI Display ~ $8.99)](https://www.amazon.com/s?k=GC9A01+1.28+round+display)
  * [Amazon EU/DE (GC9A01 1.28 Zoll Rundes Display ~ €8.50)](https://www.amazon.de/s?k=GC9A01+1.28+display)

---

## 🔩 Hardware Fasteners & Enclosure Components

### 3. M3 × 16mm (or M3 × 12mm) Socket Head Cap Screws
* **Description:** M3 metric machine screws with cylindrical socket cap head (DIN 912 / ISO 4762), 2.5mm hex drive. Brass provides a premium industrial cyberdeck aesthetic; black oxide or stainless steel also look great.
* **Quantity:** 4 per pod
* **Purchasing Links:**
  * [Amazon US (M3 Brass Socket Head Screws Assortment ~ $9.99)](https://www.amazon.com/s?k=m3+brass+socket+head+cap+screws)
  * [Amazon EU/DE (M3 Zylinderschrauben Innensechskant ~ €7.99)](https://www.amazon.de/s?k=M3+Zylinderschrauben+Innensechskant)
  * [AliExpress (M3 Brass / Black Socket Screws ~ $1.50)](https://www.aliexpress.com/w/wholesale-M3-socket-head-cap-screws-brass.html)

---

### 4. Non-Slip Adhesive Rubber Bumper Feet
* **Description:** 6 mm to 8 mm diameter hemispherical clear or black silicone rubber bumper pads with adhesive backing. Fits into the 4 molded recesses on the bottom of the Tier 1 stand base to prevent sliding.
* **Quantity:** 4 per stand
* **Purchasing Links:**
  * [Amazon US (Self-Adhesive Rubber Bumper Pads ~ $4.99)](https://www.amazon.com/s?k=rubber+bumper+feet+adhesive+small)
  * [Amazon EU/DE (Selbstklebende Gummifüße ~ €3.99)](https://www.amazon.de/s?k=Gummifuesse+selbstklebend)
  * [AliExpress (Silicone Bumper Pads 100pcs ~ $1.20)](https://www.aliexpress.com/w/wholesale-silicone-rubber-feet-adhesive.html)

---

### 5. Flexible Hookup Wire / Female-to-Female DuPont Jumpers
* **Description:** 28 AWG or 30 AWG stranded silicone flexible wire (or 10cm Female-to-Female 2.54mm pitch DuPont ribbon cables).
* **Quantity:** 7–8 wires for the GC9A01 SPI hookup.
* **Purchasing Links:**
  * [Amazon US (28/30 AWG Silicone Hookup Wire Spool Kit ~ $9.99)](https://www.amazon.com/s?k=30+awg+silicone+wire)
  * [Amazon US (10cm Female-to-Female DuPont Jumpers ~ $4.99)](https://www.amazon.com/s?k=dupont+cables+female+to+female+10cm)
  * [AliExpress (Silicone Wire 30AWG / DuPont Cables ~ $1.50)](https://www.aliexpress.com/w/wholesale-30awg-silicone-wire.html)

---

### 6. USB-C Cable (Data & Power)
* **Description:** Standard USB Type-C cable (USB-A to USB-C or USB-C to USB-C) capable of data transfer (required for initial firmware flashing and Web Serial Wi-Fi setup).
* **Length:** 0.5m – 1.5m
* **Quantity:** 1

---

## 🧵 3D Printing Filament Guide

| Part | Recommended Filament Type | Recommended Color / Finish | Approx. Filament Weight |
| :--- | :--- | :--- | :---: |
| **Main Housing Bucket** | PLA / PETG / ABS | Matte Charcoal / Galaxy Black | ~18 g |
| **Front Display Bezel** | PLA / PETG / ABS | Matte Black or Gunmetal Gray | ~10 g |
| **Tier 2 Pedestal Trunk** | PLA / PETG / ABS | Matte Dark Gray or Black | ~24 g |
| **Tier 1 Base Plate** | Wood PLA / Standard PLA | Dark Walnut / Teak Wood PLA | ~14 g |

---

## 📊 Summary of Total Build Cost

| Item | Budget Source (AliExpress) | Fast Domestic Source (Amazon) |
| :--- | :---: | :---: |
| **ESP32-C3 SuperMini** | $2.50 | $4.50 |
| **GC9A01 1.28" Round LCD** | $3.80 | $7.99 |
| **M3 Screws & Bumper Feet** | $1.20 | $3.00 |
| **Wires & Filament** | $1.00 | $1.50 |
| **Estimated Total:** | **~$8.50** | **~$16.99** |

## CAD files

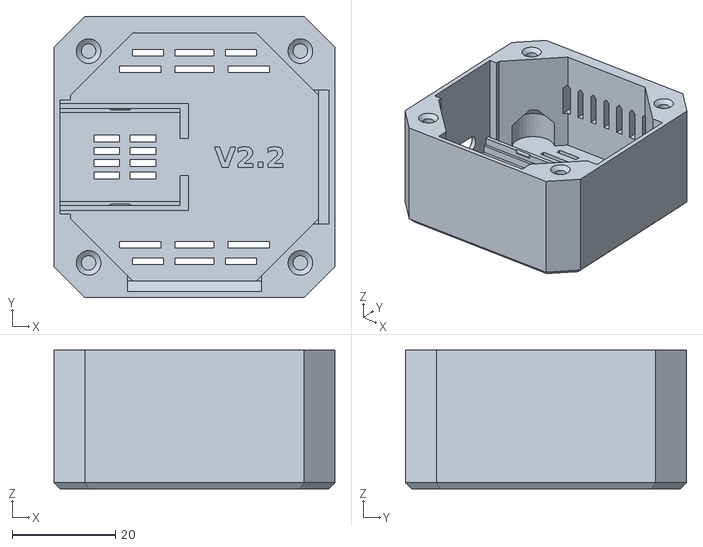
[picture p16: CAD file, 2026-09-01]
round 240x240/enclosure/gc9a01_main_housing.stl
54.4 x 54.4 x 26.8

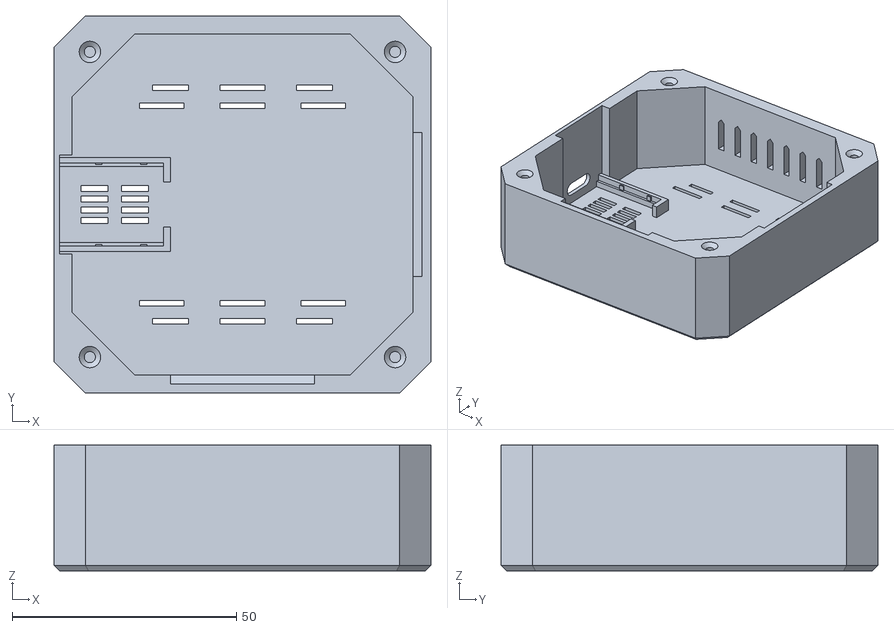
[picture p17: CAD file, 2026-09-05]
round 360x360/enclosure/gc9b72_main_housing.stl
84.0 x 84.0 x 28.0

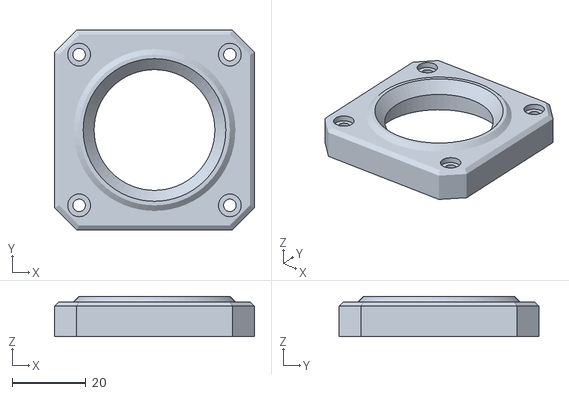
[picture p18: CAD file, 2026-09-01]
round 240x240/enclosure/gc9a01_front_bezel.stl
54.4 x 54.4 x 11.0

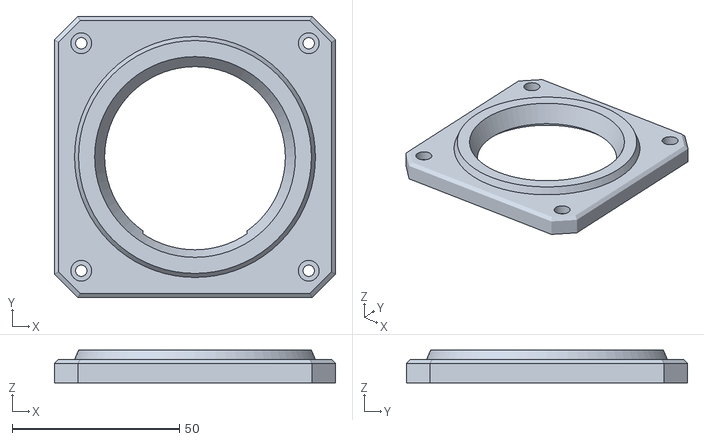
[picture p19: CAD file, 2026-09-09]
round 360x360/enclosure/gc9b72_front_face.stl
84.0 x 84.0 x 9.80

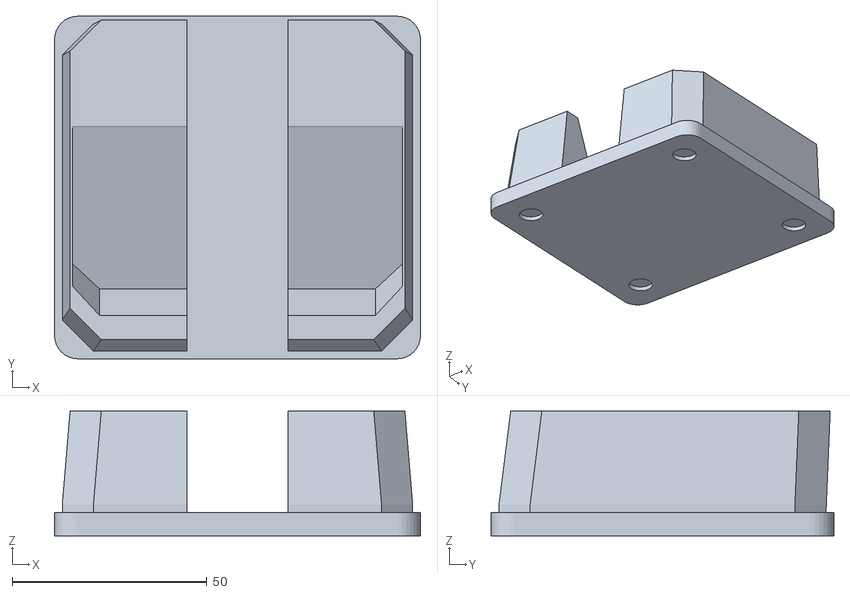
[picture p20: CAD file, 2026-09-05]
round 360x360/enclosure/gc9b72_monolithic_stand.stl
94.0 x 88.0 x 32.0

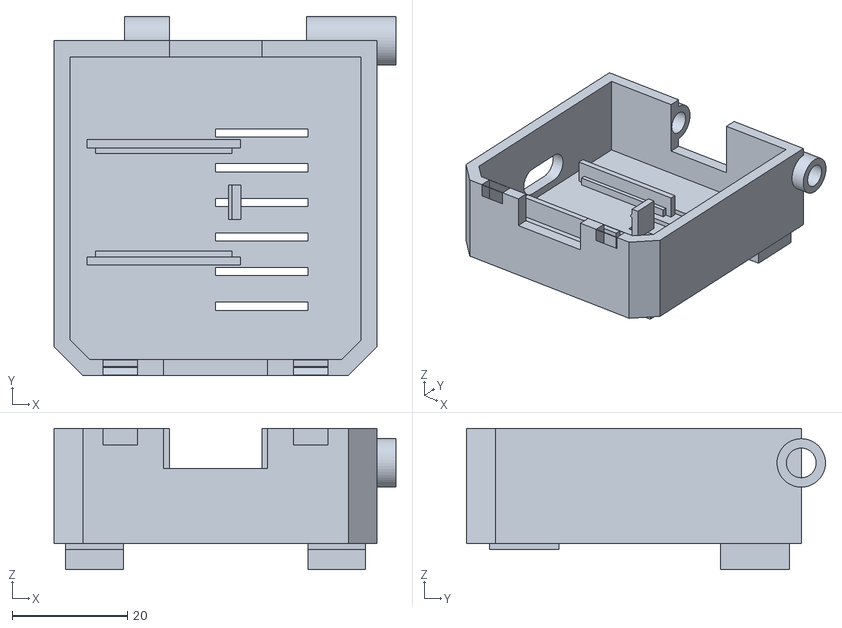
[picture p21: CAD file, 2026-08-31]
round 240x240/enclosure/gc9a01_springlatch_base.stl
59.2 x 62.2 x 24.5

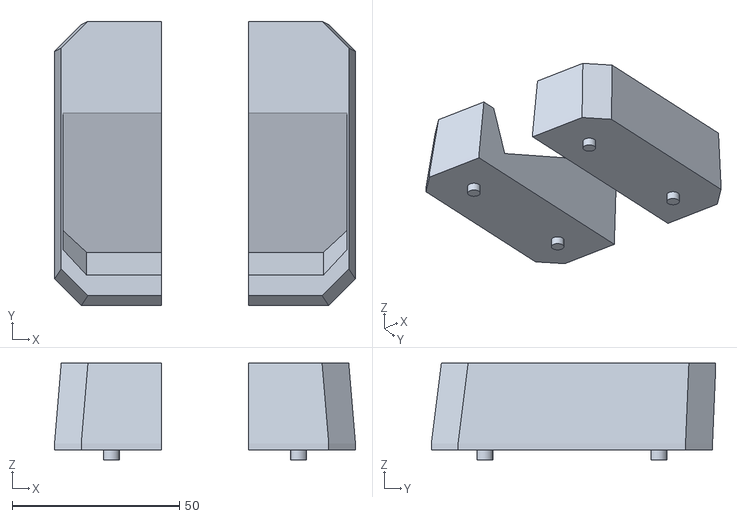
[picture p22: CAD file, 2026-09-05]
round 360x360/enclosure/gc9b72_stand_tier2_trunk.stl
90.0 x 85.0 x 29.0

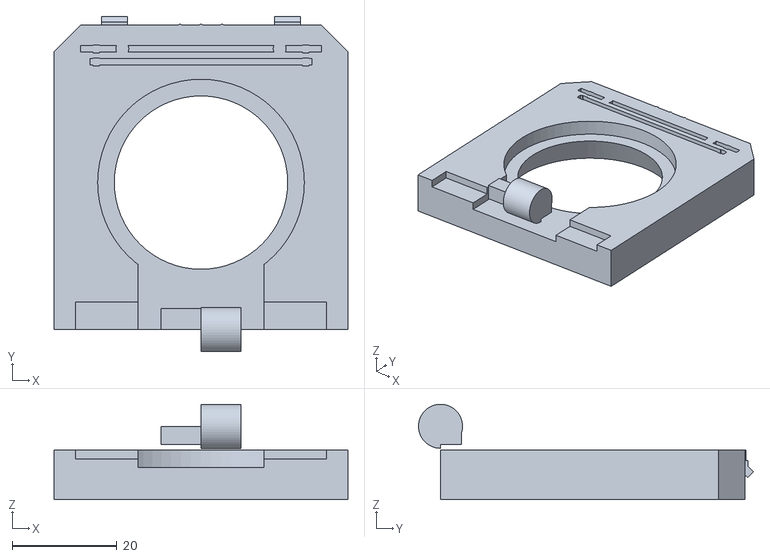
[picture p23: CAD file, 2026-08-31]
round 240x240/enclosure/gc9a01_springlatch_lid.stl
56.0 x 63.9 x 18.2

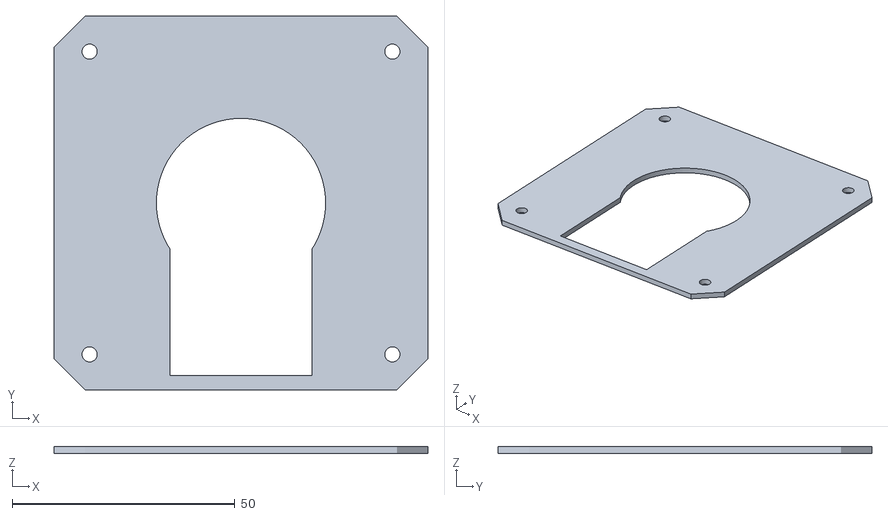
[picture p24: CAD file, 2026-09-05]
round 360x360/enclosure/gc9b72_rear_clamp.stl
84.0 x 84.0 x 1.60

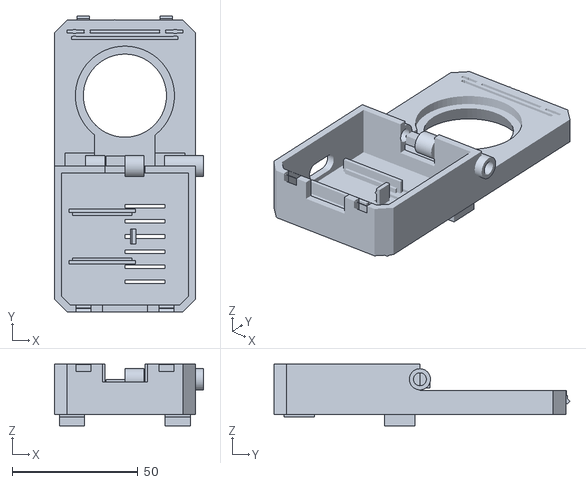
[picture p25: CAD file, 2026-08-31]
round 240x240/enclosure/gc9a01_springlatch_enclosure_flat.stl
59.2 x 117.7 x 24.5

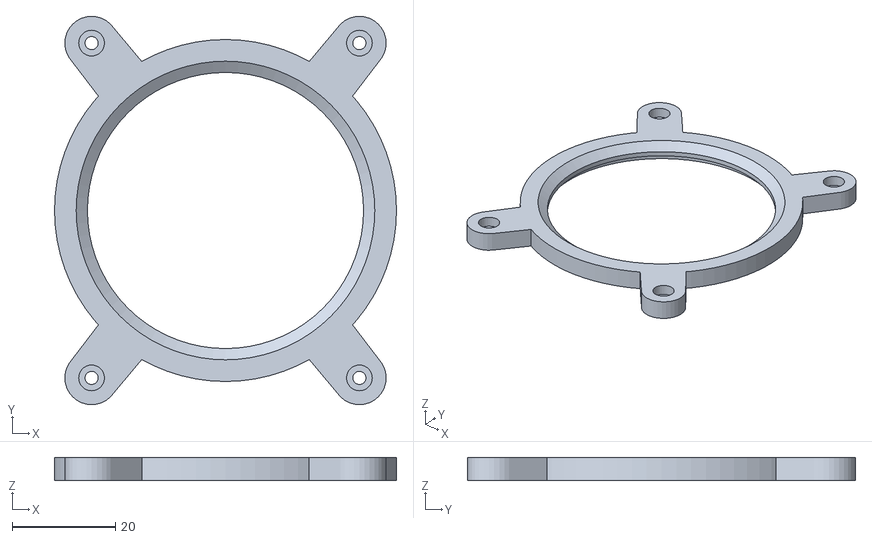
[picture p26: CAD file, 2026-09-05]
round 360x360/enclosure/gc9b72_top_bezel.stl
66.4 x 75.4 x 4.50

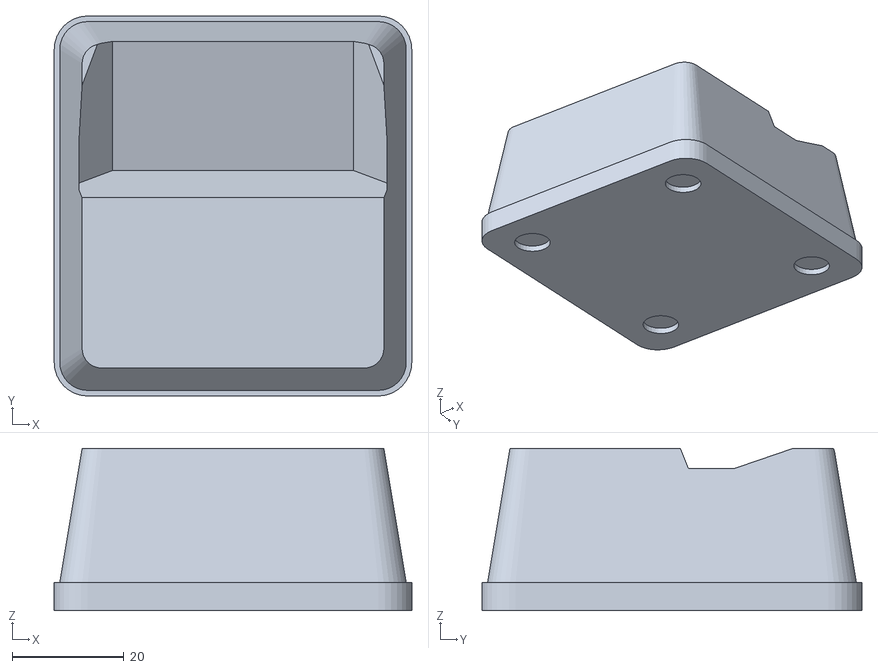
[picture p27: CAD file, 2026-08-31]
round 240x240/enclosure/gc9a01_desk_stand.stl
64.0 x 68.0 x 29.0

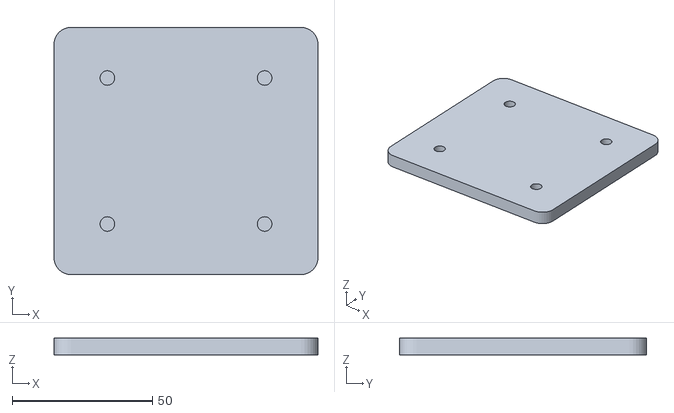
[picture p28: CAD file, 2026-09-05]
round 360x360/enclosure/gc9b72_stand_tier1_base.stl
94.0 x 88.0 x 6.00

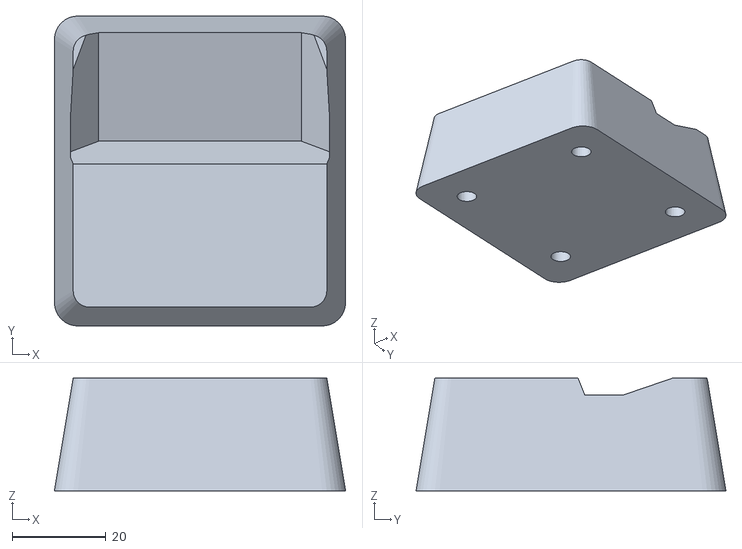
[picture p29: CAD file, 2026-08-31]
round 240x240/enclosure/gc9a01_stand_tier2_trunk.stl
62.0 x 66.0 x 24.0

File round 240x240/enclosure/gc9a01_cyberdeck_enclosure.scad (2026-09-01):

// =========================================================================
// GC9A01 1.28" Circular IPS Display & ESP32-C3 SuperMini Cyberdeck Enclosure
// Parametric OpenSCAD Source Model (Replicating the Cyberdeck Unit 01 Desk Concept)
// 100% Support-Free FDM 3D Printable Architecture
// =========================================================================

$fn = 64; // High resolution curves for 3D printing

// --- PARAMETERS ---
part = is_undef(part) ? 2 : part; // 0 = Assembly Preview, 1 = Front Bezel (60° Male Tongue), 2 = Main Housing (V2.1, 60° Female Socket), 4 = Stand Tier 1 Base, 5 = Stand Tier 2 Trunk, 6 = Monolithic Pedestal Stand, 7 = Minimalist Cradle Stand, 8 = Main Housing Legacy (Single Trench)

// Outer Dimensions
enclosure_width  = 54.4; // Outer width & height (mm) — 54.4mm yields exact 1.2mm (3x 0.4mm perimeters) thin walls
housing_depth    = 26.84; // Open-tub housing depth (mm) - capped uniformly at 26.84mm
bezel_thickness  = 5.5;  // Display carrier front bezel plate thickness (mm)
chamfer_size     = 6.0;  // Cyberdeck corner chamfers (mm)
outer_chamfer    = 1.2;  // Standard perimeter 45-degree outer edge chamfer (mm)

// Display Pocket Dimensions
display_active_dia = 33.0; // Active LCD A.A clearing diameter at glass plane (mm)
display_funnel_top = 38.8; // Wide front opening diameter (36.4° conical anti-shadow slope) (mm)
display_glass_dia  = 36.6; // Glass / Backlight step (mm)
display_pcb_dia    = 39.6; // Circular PCB body (38.0mm blueprint + 1.6mm generous clearance) (mm)
display_tab_w      = 26.0; // Bottom connector tab width (mm) - Expanded for soldered DuPont connector clearance
display_tab_h      = 25.90; // Tab height from center (mm) - Leaves exactly 1.30mm outer wall (3 perimeters)
display_pcb_depth  = 3.4;  // Bezel rear pocket depth (mm)

// Mid Clamp Sandwich Plate Parameters
mid_clamp_thickness = 2.0;  // Mid clamp sandwich plate thickness (mm)
mid_clamp_lip_h     = 0.6;  // Forward circular compression collar protrusion (mm)
mid_clamp_inner_dia = 34.0; // Central component clearance opening (mm)
mid_clamp_outer_dia = 38.6; // Outer compression rim diameter (mm)

// Direct Screen Bolting Blind Pilot Holes
screen_bolt_x      = 9.63;  // Half of 19.26mm hole-to-hole pitch (mm)
screen_bolt_y      = -18.91; // Y distance from screen center (mm)
screen_bolt_dia    = 1.75;  // Blind pilot holes (mm)
screen_bolt_depth  = 3.2;   // Blind depth from rear pocket (mm)

// Bezel Corner Screws (M3 Socket Cap Screws)
screw_bolt_circle  = 41.0; // 41mm center-to-center square (x=+/-20.50, y=+/-20.50)
screw_hole_dia     = 3.4;  // M3 clearance through-hole (mm)
screw_head_dia     = 6.2;  // M3 socket cap head counterbore (mm)
screw_head_depth   = 3.2;  // Counterbore pocket depth (mm)
screw_pilot_dia    = 2.8;  // M3 pilot / self-tapping hole (mm)

// Internal Cavity & ESP32-C3 SuperMini Mounting
cavity_w           = 48.0; // 48mm wide internal bay (3.0mm slim perimeter walls) (mm)
cavity_chamfer     = 12.0; // 12.0mm corner chamfers (mm)
floor_t            = 2.0;  // Rear wall floor thickness (mm)
esp_l              = 23.2; // ESP32-C3 PCB length along X (mm)
esp_w              = 18.70; // ESP32-C3 SuperMini PCB width along Y (mm) (+0.20mm tolerance)
esp_standoff_h     = 3.2;  // ESP32 standoff rail height (mm)
esp_center_x       = -10.0;// Center offset along X (mm)
usbc_center_z      = 6.60; // USB-C port centerline (centered on USB-C metal shell at Z=6.60mm)

// Stand Parameters
stand_base_w       = 64.0; // Tier 1 base width (mm)
stand_base_d       = 68.0; // Tier 1 base depth (mm)
stand_base_h       = 5.0;  // Tier 1 base height (mm)
stand_trunk_h      = 24.0; // Tier 2 cradle trunk height (mm)
stand_tilt_deg     = 22.0; // Backward tilt angle from vertical (degrees)
pin_dist_x         = 20.0; // Alignment pillar X distance from center (mm)
pin_dist_y         = 21.0; // Alignment pillar Y distance from center (mm)
pin_dia            = 5.0;  // Alignment pillar diameter (mm)
pin_h              = 3.5;  // Alignment pillar height (mm)

// --- MODULES ---

// Chamfered Octagonal Prism
module octagonal_prism(w, h, c) {
    hw = w / 2;
    linear_extrude(height = h) {
        polygon([
            [-hw + c, -hw], [hw - c, -hw],
            [hw, -hw + c],  [hw, hw - c],
            [hw - c, hw],   [-hw + c, hw],
            [-hw, hw - c],  [-hw, -hw + c]
        ]);
    }
}

// Chamfered Octagonal Base with Perimeter Chamfer
module chamfered_octagonal_base(w, h, c, ch, chamfer_top=true) {
    hw1 = w / 2;
    hw2 = (w - 2 * ch) / 2;
    c2 = c - ch * 0.414;
    
    if (chamfer_top) {
        hull() {
            linear_extrude(height = h - ch) {
                polygon([
                    [-hw1 + c, -hw1], [hw1 - c, -hw1],
                    [hw1, -hw1 + c],  [hw1, hw1 - c],
                    [hw1 - c, hw1],   [-hw1 + c, hw1],
                    [-hw1, hw1 - c],  [-hw1, -hw1 + c]
                ]);
            }
            translate([0, 0, h - 0.001])
            linear_extrude(height = 0.001) {
                polygon([
                    [-hw2 + c2, -hw2], [hw2 - c2, -hw2],
                    [hw2, -hw2 + c2],  [hw2, hw2 - c2],
                    [hw2 - c2, hw2],   [-hw2 + c2, hw2],
                    [-hw2, hw2 - c2],  [-hw2, -hw2 + c2]
                ]);
            }
        }
    } else {
        // Chamfer bottom only (100% flat mating top face at Z=h)
        hull() {
            linear_extrude(height = 0.001) {
                polygon([
                    [-hw2 + c2, -hw2], [hw2 - c2, -hw2],
                    [hw2, -hw2 + c2],  [hw2, hw2 - c2],
                    [hw2 - c2, hw2],   [-hw2 + c2, hw2],
                    [-hw2, hw2 - c2],  [-hw2, -hw2 + c2]
                ]);
            }
            translate([0, 0, ch])
            linear_extrude(height = h - ch) {
                polygon([
                    [-hw1 + c, -hw1], [hw1 - c, -hw1],
                    [hw1, -hw1 + c],  [hw1, hw1 - c],
                    [hw1 - c, hw1],   [-hw1 + c, hw1],
                    [-hw1, hw1 - c],  [-hw1, -hw1 + c]
                ]);
            }
        }
    }
}

// Rounded Rectangular Prism
module rounded_rect_prism(w, d, h, r) {
    hw = w / 2 - r;
    hd = d / 2 - r;
    linear_extrude(height = h) {
        hull() {
            translate([hw, hd]) circle(r = r);
            translate([-hw, hd]) circle(r = r);
            translate([-hw, -hd]) circle(r = r);
            translate([hw, -hd]) circle(r = r);
        }
    }
}

// Precision Classic Oval/Stadium USB-C Cutter with Accentuated Lead-in Chamfer
module usbc_stadium_cutter() {
    y_span = 3.40;
    r_in   = 1.95; // Snug 3.90mm opening height (eliminates top gap above USB-C port)
    r_out  = 2.85; // 5.70mm outer flare for cable overmold entry
    
    // Outer to inner through-wall tunnel (X = -32.0mm to -25.5mm)
    translate([-32.0, 0, usbc_center_z]) {
        rotate([0, 90, 0]) {
            hull() {
                translate([0, -y_span, 0]) cylinder(r = r_in, h = 7.0, $fn = 32);
                translate([0,  y_span, 0]) cylinder(r = r_in, h = 7.0, $fn = 32);
            }
        }
    }
    // External lead-in entry chamfer on outside wall (X = -29.2 to -27.2)
    translate([-29.2, 0, usbc_center_z]) {
        rotate([0, 90, 0]) {
            hull() {
                translate([0, -y_span, 0]) cylinder(r1 = r_out, r2 = r_in, h = 2.0, $fn = 32);
                translate([0,  y_span, 0]) cylinder(r1 = r_out, r2 = r_in, h = 2.0, $fn = 32);
            }
        }
    }
}
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

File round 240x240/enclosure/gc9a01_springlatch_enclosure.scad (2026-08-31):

// =========================================================================
// GC9A01 1.28" Circular IPS Display & ESP32-C3 SuperMini
// Springlatch Edition - 100% Print-in-Place (PiP) Clamshell Enclosure
// Inspired by Clockspring 3D Compliant Springlatch Mechanisms
// 100% Support-Free FDM 3D Printable Architecture
// =========================================================================

$fn = 64; // High resolution curves for 3D printing

// --- PART SELECTOR ---
// 0 = Full Print-in-Place Assembly (Flat 180° Unfolded for 3D Printing)
// 1 = Main Lower Housing (Base Only)
// 2 = Upper Hinged Bezel (Lid Only)
// 3 = Closed Enclosure Assembly Preview (Desk Operating Mode)
part = 0;

// --- GLOBAL DIMENSIONS ---
box_w         = 56.0;  // Enclosure width (X, mm)
box_d         = 58.0;  // Enclosure depth (Y, mm from hinge center to front)
base_h        = 20.0;  // Base lower tub height (Z, mm)
lid_h         = 9.5;   // Upper lid thickness (Z, mm)
wall_t        = 2.8;   // Outer perimeter wall thickness (mm)
floor_t       = 2.0;   // Base floor thickness (mm)
chamfer_c     = 5.0;   // Front corner 45-degree chamfers (mm)
outer_ch      = 1.2;   // Perimeter edge chamfer (mm)

// --- HINGE PARAMETERS ---
hinge_z       = 14.0;  // Hinge axis height above print bed (mm)
hinge_rad_out = 4.2;   // Outer knuckle radius (mm)
hinge_pin_rad = 2.2;   // Axle pin radius (mm)
hinge_clear   = 0.38;  // Radial print-in-place clearance gap (mm)
hinge_gap_x   = 0.40;  // Axial knuckle separation gap (mm)

// Knuckle spans along X:
knuckle_mid_w = 15.2;
knuckle_out_w = 15.5;
knuckle_out_x = 15.75;

// --- SPRINGLATCH PARAMETERS ---
spring_beam_t = 0.95;  // Thickness of compliant serpentine spring ribbon (mm)
spring_slit_w = 1.25;  // Air clearance gap between spring waves (mm)
spring_h      = 5.0;   // Height of spring flexure in Z (mm)
latch_tab_w   = 14.0;  // Center push-button tab width (mm)
latch_hook_w  = 5.0;   // Left/right latch locking hooks width (mm)
latch_hook_x  = 16.5;  // Offset distance of locking hooks from center (mm)
latch_lip_dep = 1.20;  // Depth of locking undercut hook (mm)
cam_ramp_ang  = 45.0;  // Auto-camming lead-in ramp angle (degrees)

// --- DISPLAY POCKET PARAMETERS (LID) ---
disp_center_y = 28.0;  // Screen center Y offset from hinge (mm)
disp_active_d = 33.0;  // Active display viewing opening (mm)
disp_funnel_d = 38.6;  // Conical anti-shadow viewing bezel opening (mm)
disp_glass_d  = 36.6;  // Glass step diameter (mm)
disp_pcb_d    = 39.4;  // PCB circular body pocket (mm)
disp_depth    = 3.4;   // Internal pocket depth (mm)

// --- ESP32-C3 SUPERMINI MOUNTING (BASE) ---
esp_l         = 23.6;  // Length (+0.6mm clearance)
esp_w         = 18.9;  // Width (+0.5mm clearance)
esp_rail_h    = 1.8;   // Support ledge height (mm)
esp_cx        = -9.0;  // Center X offset (mm)
esp_cy        = -28.0; // Center Y offset from hinge (mm)
usbc_z        = 7.0;   // USB-C port centerline height (mm)

// --- KICKSTAND PADS PARAMETERS ---
kickstand_h   = 4.5;   // Height of rear kickstand elevation wedges (mm)
feet_pocket_d = 8.2;   // Non-slip rubber bumper pocket diameter (mm)
feet_pocket_h = 1.4;   // Bumper pocket depth (mm)


// =========================================================================
// 2D PROFILE HELPERS (CCW WINDING)
// =========================================================================

module box_perimeter_2d(w, d, c) {
    hw = w / 2.0;
    polygon(points=[
        [-hw, 0],
        [-hw, -d + c],
        [-hw + c, -d],
        [hw - c, -d],
        [hw, -d + c],
        [hw, 0]
    ]);
}

module lid_perimeter_2d(w, d, c) {
    hw = w / 2.0;
    polygon(points=[
        [-hw, 0],
        [hw, 0],
        [hw, d - c],
        [hw - c, d],
        [-hw + c, d],
        [-hw, d - c]
    ]);
}


// =========================================================================
// MODULE: BASE HOUSING (LOWER TUB WITH KICKSTAND & ESP32 CRADLE)
// =========================================================================

module base_housing() {
    difference() {
        union() {
            // 1. Main outer tub solid
            linear_extrude(base_h)
                box_perimeter_2d(box_w, box_d, chamfer_c);

            // 2. Base Hinge Knuckles (Left and Right)
            for (sx = [-1, 1]) {
                translate([sx * knuckle_out_x, 0, hinge_z])
                    rotate([0, 90, 0])
                        cylinder(r=hinge_rad_out, h=knuckle_out_w, center=true);
                
                translate([sx * knuckle_out_x, -2.0, hinge_z / 2.0])
                    cube([knuckle_out_w, 4.0, hinge_z], center=true);
            }

            // 3. Integrated Angled Desk Kickstand Pads (Rear elevation wedges)
            translate([-box_w/2 + 7.0, -8.0, -kickstand_h/2])
                cube([10.0, 12.0, kickstand_h], center=true);
            translate([box_w/2 - 7.0, -8.0, -kickstand_h/2])
                cube([10.0, 12.0, kickstand_h], center=true);
            translate([-box_w/2 + 7.0, -box_d + 10.0, -1.0/2])
                cube([10.0, 12.0, 1.0], center=true);
            translate([box_w/2 - 7.0, -box_d + 10.0, -1.0/2])
                cube([10.0, 12.0, 1.0], center=true);
        }

        // --- CUTOUTS ---

        // 1. Main Internal Electronics Cavity
        translate([0, 0, floor_t])
            linear_extrude(base_h + 1.0)
                offset(r=-wall_t)
                    box_perimeter_2d(box_w, box_d, chamfer_c);

        // 2. Hinge Pin Clearance Bores (Outer Knuckles)
        for (sx = [-1, 1]) {
            translate([sx * knuckle_out_x, 0, hinge_z])
                rotate([0, 90, 0])
                    cylinder(r=hinge_pin_rad + hinge_clear, h=knuckle_out_w + 2.0, center=true);
        }

        // 3. Center Knuckle Clearance Pocket for Lid
        translate([0, 0, hinge_z])
            cube([knuckle_mid_w + 2 * hinge_gap_x, 2 * hinge_rad_out + 2.0, 2 * hinge_rad_out + 4.0], center=true);

        // 4. USB-C Port Cutout on Left Wall (X = -box_w/2)
        translate([-box_w/2 - 1.0, esp_cy, usbc_z])
            rotate([0, 90, 0])
                hull() {
                    translate([0, -4.0, 0]) cylinder(r=3.25, h=wall_t + 3.0);
                    translate([0, 4.0, 0]) cylinder(r=3.25, h=wall_t + 3.0);
                }

        // 5. Front Latch Catches & 45° Auto-Camming Lead-in Ramps (Y = -box_d)
        for (sx = [-latch_hook_x, latch_hook_x]) {
            translate([sx, -box_d + wall_t - 0.2, base_h - 4.5])
                cube([latch_hook_w + 1.0, latch_lip_dep + 0.8, 3.2], center=true);
            
            translate([sx, -box_d + wall_t/2.0, base_h - 1.5])
                rotate([cam_ramp_ang, 0, 0])
                    cube([latch_hook_w + 1.0, 4.0, 4.0], center=true);
        }

        // 6. Central Thumb Push Recess
        translate([0, -box_d + wall_t/2.0, base_h - 3.0])
            cube([latch_tab_w + 4.0, wall_t + 1.0, 8.0], center=true);

        // 7. Passive Aeration Slots on Bottom Floor
        for (y_slot = [-16, -22, -28, -34, -40, -46]) {
            translate([8.0, y_slot, -kickstand_h - 0.1])
                cube([16.0, 1.4, kickstand_h + floor_t + 1.0], center=true);
        }

        // 8. Rubber Bumper Feet Recess Pockets
        translate([-box_w/2 + 7.0, -8.0, -kickstand_h - 0.1])
            cylinder(r=feet_pocket_d/2.0, h=feet_pocket_h + 0.1);
        translate([box_w/2 - 7.0, -8.0, -kickstand_h - 0.1])
            cylinder(r=feet_pocket_d/2.0, h=feet_pocket_h + 0.1);
        translate([-box_w/2 + 7.0, -box_d + 10.0, -1.0 - 0.1])
            cylinder(r=feet_pocket_d/2.0, h=feet_pocket_h + 0.1);
        translate([box_w/2 - 7.0, -box_d + 10.0, -1.0 - 0.1])
            cylinder(r=feet_pocket_d/2.0, h=feet_pocket_h + 0.1);
    }

    // --- INTERNAL ESP32-C3 SUPERMINI CRADLE ---
    translate([esp_cx, esp_cy, floor_t])
        esp32_cradle();
}


// =========================================================================
// MODULE: ESP32-C3 SNAP-FIT CRADLE
// =========================================================================

module esp32_cradle() {
    hw = esp_w / 2.0;
    hl = esp_l / 2.0;
    
    // Side Guide Rails with PCB resting ledge
    difference() {
        union() {
            translate([-hl - 1.5, -hw - 1.4, 0])
                cube([esp_l + 3.0, 1.4, 5.0]);
            translate([-hl - 1.5, hw, 0])
                cube([esp_l + 3.0, 1.4, 5.0]);
            translate([-hl, -hw, 0])
                cube([esp_l, 1.0, esp_rail_h]);
            translate([-hl, hw - 1.0, 0])
                cube([esp_l, 1.0, esp_rail_h]);
        }
    }

    // Rear Compliant Cantilever Snap Arm (X = +hl)
    translate([hl, -3.0, 0]) {
        cube([1.6, 6.0, 7.2]);
        translate([-0.55, 0, 5.2])
            rotate([0, 30, 0])
                cube([0.8, 6.0, 1.6]);
    }
}
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

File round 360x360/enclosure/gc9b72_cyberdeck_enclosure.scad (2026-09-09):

// =========================================================================
// GC9B72 2.1" Round TFT (360x360) Cyberdeck Desk Console Enclosure
// Parametric OpenSCAD Master Model
// Form Factor: 100% Symmetrical Square Housing Pod (84.0mm x 84.0mm)
// Re-engineered directly from the 240x240 Unit 01 Heritage Architecture:
// - 45° outer bottom chassis chamfer (1.2mm x 45°) + 45° corner chamfers (7.0mm)
// - Precision flush-edge ESP32 cradle (board 1.2mm from outer edge, x_front = -40.8mm)
// - Shaved-depth USB-C port with 45° conical lead-in flare
// - 45° peaked-roof top vertical exhaust vents + horizontal rear aeration rows
// - Elevated DuPont clearance trench with 45° bottom ramp
// - M2.3 socket head screws for Top Bezel with 100% direct plastic tapping
// =========================================================================

$fn = 72; // Smooth curves for 3D printing

// --- SELECT PART TO RENDER ---
// 0 = Full Assembly Exploded/Closed Preview
// 1 = Circular Top Bezel Ring (M2.3 4-Screw Screen Clamp)
// 2 = Front Face Carrier Plate (84x84mm Square + Ø1.90mm Direct Tap Pilot Holes)
// 3 = Main Housing Pod (84x84mm Square + Flush ESP32 Cradle + Left USB-C Port)
// 4 = Stand Tier 1 Base Accent Plate (Wood/Walnut Base)
// 5 = Stand Tier 2 Cradle Trunk (22° V-Saddle for 84mm Pod)
// 6 = Monolithic Combined Desk Stand
part = is_undef(part) ? 0 : part;

// =========================================================================
// PARAMETERS (All in millimeters)
// =========================================================================

// --- Screen Blueprint Dimensions (GoldenMorning GC9B72) ---
screen_pcb_w        = 59.24; // Screen PCB width
screen_pcb_h        = 67.47; // Screen PCB total height
screen_lcm_w        = 55.92; // Outer display module width
screen_lcm_h        = 57.58; // Outer display module height
screen_glass_w      = 55.52; // Outer glass width
screen_glass_h      = 57.18; // Outer glass height
screen_active_dia   = 52.92; // Active circular display diameter
screen_thickness    = 2.40;  // Total glass + PCB thickness
screen_circle_cy    = 0.0;   // Origin is aligned with the center of the active circle

// Top of PCB: +29.62mm, Bottom of PCB: -37.85mm
screen_pcb_top      = 29.62;
screen_pcb_bottom   = -37.85;
screen_tab_half_w   = 15.24; // Official blueprint dimension: (10 - 1)*2.54/2 + 3.81 = 15.24mm (30.48mm width)
screen_tab_w        = 30.48; // Official blueprint tab width
screen_pocket_depth = 2.00;  // Recess depth in front face carrier plate
screen_tolerance    = 0.36;  // Printing tolerance (pocket width = 31.20mm)

// --- Enclosure Outer Footprint (100% Symmetrical Square Pod) ---
housing_w           = 84.0;  // Pod outer width (84mm square)
housing_h           = 84.0;  // Pod outer height (84mm square)
housing_depth       = 28.0;  // Main housing depth
front_face_thick    = 7.0;   // Front face carrier plate thickness
bezel_thick         = 4.5;   // Top bezel ring total thickness
chamfer_outer       = 7.0;   // Cyberdeck 45° corner chamfer size
edge_chamfer        = 1.2;   // Outer perimeter 45° edge bevel
floor_thick         = 2.0;   // Rear housing floor thickness
cavity_depth        = housing_depth - floor_thick;

// --- Option 2: Rear-Loading Architecture Parameters ---
rear_pocket_depth   = 2.40;  // Recessed cavity depth on rear of Front Face
integrated_bezel_h  = 2.80;  // Raised circular bezel rim height on front (increased from 1.60mm)
integrated_bezel_od = 72.00; // Raised circular bezel outer diameter (increased from 66.40mm)
screen_aperture_dia = 54.00; // Central circular viewing aperture at screen retaining lip
screen_aperture_top = 60.00; // Continuous conical viewing funnel top diameter at ring summit

// --- Direct M2 Screen Tab Clamping & Rising Boss Pillars ---
screen_mount_hole_x = 12.20; // Blueprint 2-R1 mounting hole X offset (+/-12.20mm, 24.4mm pitch)
screen_mount_hole_y = -31.50;// Blueprint 2-R1 mounting hole Y offset (2.54mm above pin row)
screen_pillar_dia   = 4.40;  // Reinforced rear mounting boss pillar diameter
tab_relief_depth    = 1.80;  // Extra relief depth for tab pocket floor (Z = 2.40 to 4.20mm)
m2_pilot_dia        = 1.70;  // Blind pilot hole for direct M2 plastic tapping (PLA/PETG)
m2_pilot_depth      = 3.60;  // Deep thread engagement down into pillar (leaves 1.00mm solid front wall)

dupont_front_relief_w = 21.00; // Width of forward pin clearance pocket (centered over pins 2-9, X = +/-10.5mm)
dupont_front_relief_h = 3.60;  // Height of forward pin clearance pocket (Y = -35.80 to -32.20mm)
dupont_front_relief_y = -34.00;// Centerline of 10-pin header row
dupont_front_relief_depth = 2.20; // Depth into front face from rear pocket floor (leaves 2.40mm solid front wall)

// --- Rear Clamp Plate Parameters (Sandwich Architecture - Retained for Compatibility) ---
clamp_thick         = 1.60;  // Slim 1.6mm intermediate sandwich clamp plate (8 layers at 0.2mm)

// --- Legacy Circular Top Bezel Parameters (Retained for reference) ---
bezel_inner_dia     = 53.60;
bezel_funnel_top    = 58.00;
bezel_ring_dia      = 66.40;
bezel_retaining_dia = 56.80;
bezel_retaining_depth = 0.80;

// --- Legacy M2.3 Fasteners ---
bezel_screw_x       = 26.00;
bezel_screw_y       = 32.50;
m2_3_clearance      = 2.55;
m2_3_cb_dia         = 5.00;
m2_3_cb_depth       = 2.40;
m2_3_pilot_dia      = 1.90;
m2_3_pilot_depth    = 5.20;

// --- Symmetrical Square Housing Corner Fasteners (Direct Plastic Tapping) ---
corner_screw_x      = 34.00; // Symmetrical square pattern (+/-34mm)
corner_screw_y      = 34.00; // Symmetrical square pattern (+/-34mm)
m3_clearance        = 3.40;  // Front face clearance through-hole
m3_cb_dia           = 6.20;  // M3 socket head counterbore diameter
m3_cb_depth         = 3.50;  // M3 counterbore depth
m3_pilot_dia        = 2.50;  // Direct plastic tap pilot hole in housing corner posts
m3_pilot_depth      = 14.00; // Deep thread engagement in corner posts
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

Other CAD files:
round 240x240/enclosure/gc9a01_minimalist_stand.stl
round 240x240/enclosure/gc9a01_u_bracket_kickstand.stl
round 240x240/enclosure/esp32_s3_supermini_carrier.stl
round 240x240/enclosure/gc9a01_stand_tier1_base.stl
round 240x240/enclosure/gc9a01_main_housing_legacy.stl
round 240x240/enclosure/gc9a01_stand_accent_base.stl

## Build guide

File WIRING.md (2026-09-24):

# ⚡ Hardware Wiring Guide: ESP32-C3 SuperMini

This guide provides complete visual wiring diagrams and pin mapping references for connecting the display to the **ESP32-C3 SuperMini**.

---

> 🌟 **Looking for the 2.1″ GC9B72 360×360 screen wiring?** See [`round 360x360/WIRING.md`](./round%20360x360/WIRING.md).

---

## 🔘 GC9A01 1.28" Circular IPS Display (SPI)

The GC9A01 circular display communicates over high-speed hardware **SPI**.

<p align="center">
  GC9A01 1.28 Round Display SPI Wiring Diagram
</p>

### 📍 GC9A01 SPI Pin Mapping:

| Display Pin (GC9A01) | ESP32-C3 SuperMini Pin | Physical Header Location | Wire Color Cue | Description |
| :--- | :--- | :--- | :--- | :--- |
| **VCC** | **3V3** | Left Header (Pin 3) | 🔴 **Red** | 3.3V Power Supply |
| **GND** | **GND** | Left Header (Pin 2) | ⚫ **Black / Slate** | Common Ground |
| **SCL / SCK** | **GPIO 4** | Left Header (Pin 8) | 🟡 **Yellow** | Hardware SPI Clock |
| **SDA / MOSI** | **GPIO 6** | Right Header (Pin 16) | 🔵 **Cyan** | Hardware SPI MOSI (Data) |
| **DC** | **GPIO 7** | Right Header (Pin 15) | 🟢 **Green** | Data / Command Selection |
| **CS** | **GPIO 5** | Left Header (Pin 9) | 🟣 **Purple** | SPI Chip Select |
| **RST / RES** | **GPIO 1** | Left Header (Pin 5) | 🟠 **Orange** | Hardware Reset |
| **BLK** | **GPIO 0** | Left Header (Pin 4) | 🌸 **Pink** | Backlight Control (PWM/On-Off) |

---

## 📍 ESP32-C3 SuperMini Physical Pin Reference

Looking at the board top-down with the **USB-C port pointing UP**:

```
                       [ USB-C PORT ]
                   +--------------------+
         [ 5V  ] --|  [1]          [16] |-- [ GPIO6  ] ---> GC9A01 SDA (MOSI)
         [ GND ] --|  [2]          [15] |-- [ GPIO7  ] ---> GC9A01 DC
         [ 3V3 ] --|  [3]          [14] |-- [ GPIO8  ]
 GC9A01 -[ GPIO0] -|  [4]          [13] |-- [ GPIO9  ]
 GC9A01 -[ GPIO1] -|  [5]          [12] |-- [ GPIO10 ] ---> WS2812B DIN (Data)
         [ GPIO2] -|  [6]          [11] |-- [ GPIO20 / RX ]
         [ GPIO3] -|  [7]          [10] |-- [ GPIO21 / TX ]
 GC9A01 -[ GPIO4] -|  [8]          [9]  |-- [ GND    ] ---> WS2812B GND
 GC9A01 -[ GPIO5] -|  [9]          [8]  |-- [ 5V     ] ---> WS2812B VCC (5V Rail)
                   +--------------------+
```

---

## 💡 WS2812B Addressable LED Ring / Strip Pin Mapping

The WS2812B addressable status LEDs (such as a 12- or 16-LED ring around the GC9A01 bezel) provide physical desk notification for agent status (e.g. glowing/pulsing amber when an agent is waiting for input).

| LED Pin (WS2812B) | ESP32-C3 SuperMini Pin | Physical Location | Wire Color Cue | Description |
| :--- | :--- | :--- | :--- | :--- |
| **VCC (+5V)** | **5V (VBUS)** | Right Header (Pin 8) or Left (Pin 1) | 🔴 **Red** | Power directly from 5V USB (NOT 3V3) |
| **GND** | **GND** | Right Header (Pin 9) or Left (Pin 2) | ⚫ **Black** | Common Ground |
| **DIN (Data In)** | **GPIO 10** | Right Header (Pin 12) | 🟡 **Yellow / White** | RMT DMA Data Signal |

### ⚡ Electrical Safety & Protection Guidelines:
1. **Never use the 3.3V pin for LEDs:** The SuperMini's onboard 3.3V LDO regulator is rated for ~300mA–500mA. Running the ESP32 chip + GC9A01 screen uses ~200mA. Connect WS2812B `VCC` to the board's **`5V` (VBUS)** pin so power is drawn directly from the USB-C source.
2. **Current Clamping:** The firmware and companion API enforce a hard ceiling of `brightness <= 100` (~39% duty cycle), ensuring that a 16-LED ring draws no more than ~180–220mA even at full amber.
3. **Decoupling Capacitor:** Place a **1000µF (minimum 100µF) electrolytic capacitor** across the 5V and GND power leads directly at the LED strip/ring to absorb inrush current spikes and prevent LED damage during USB hot-plugging.
4. **Data Series Resistor:** Place a **330Ω – 470Ω resistor** in series between ESP32 GPIO 10 and the first LED `DIN` pad to absorb high-frequency reflections and protect the GPIO against voltage spikes.
5. **Logic-Level Voltage Translation:** The WS2812B specification states input high threshold $V_{IH} \ge 0.7 \times V_{DD} = 3.5\text{V}$. While modern WS2812B-V5 / SK6812 chips trigger reliably with direct 3.3V logic over short desk wiring (<15cm), for maximum immunity against flickering and long cable runs, a 3.3V-to-5V level shifter (e.g. 74AHCT125) or a sacrificial diode buffer is recommended.

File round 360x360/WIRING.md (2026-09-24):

# ⚡ Hardware Wiring Guide: GC9B72 2.1″ Round Display (360×360)

Complete pinout and hardware wiring guide for connecting the **GC9B72 2.1″ circular IPS display (360×360)** to the **ESP32-C3 SuperMini** microcontroller.

---

## 🔘 GC9B72 10-Pin Header Mapping

The GC9B72 module interfaces via a 10-pin single-row header ($2.54\text{mm}$ pitch) communicating over high-speed hardware SPI.

| Pin # | Silk Label | ESP32-C3 SuperMini Pin | Physical Location | Status / Action | Description |
| :---: | :--- | :--- | :--- | :---: | :--- |
| **1** | **VCC** | **3V3** | Left Header (Pin 3) | **Required** | 3.3V Logic & Power Supply |
| **2** | **GND** | **GND** | Left Header (Pin 2) | **Required** | Common Ground |
| **3** | **SCL / SCK** | **GPIO 3** | Left Header (Pin 7) | **Required** | Hardware SPI Clock |
| **4** | **SDA / MOSI** | **GPIO 4** | Left Header (Pin 8) | **Required** | Hardware SPI MOSI (Data In) |
| **5** | **RST / RES** | **GPIO 5** | Left Header (Pin 9) | **Required** | Hardware Reset |
| **6** | **DC** | **GPIO 6** | Right Header (Pin 16) | **Required** | Data / Command Selection |
| **7** | **CS** | **GPIO 7** | Right Header (Pin 15) | **Required** | SPI Chip Select |
| **8** | **BLK** | **GPIO 0** *(or 3V3)* | Left Header (Pin 4) | **Required** | Backlight Control (Driven HIGH in FW) |
| **9** | **TE** | *(Not Connected)* | — | **NC (Leave Open)** | Tearing Effect Sync output from driver |
| **10** | **SDO** | *(Not Connected)* | — | **NC (Leave Open)** | SPI MISO (Serial Data Out / Read) |

---

## 💡 Notes on Unused Pins (TE & SDO)

1. **`SDO` (Pin 10 - SPI MISO):**
   - The firmware initializes the display bus in transmit-only mode (`Arduino_ESP32SPI` with `miso_pin = GFX_NOT_DEFINED`).
   - The ESP32 pushes framebuffers directly into display GRAM and never reads back display contents. Leaving SDO disconnected saves a vital GPIO pin for peripherals (e.g. WS2812B addressable LEDs on GPIO 10).
2. **`TE` (Pin 9 - Tearing Effect):**
   - The TE signal provides an optional V-Sync frame sync pulse.
   - Because the display runs over high-speed SPI ($40\text{--}80\text{MHz}$) updating circular telemetry gauges and split-flap numbers, software raster synchronization without TE is tear-free and avoids dedicating an interrupt GPIO.

---

## 📍 ESP32-C3 SuperMini Pinout Reference

Looking top-down at the ESP32-C3 SuperMini board with the **USB-C port pointing UP**:

```
                       [ USB-C PORT ]
                   +--------------------+
         [ 5V  ] --|  [1]          [16] |-- [ GPIO 6 ] ---> GC9B72 DC   (Pin 6)
         [ GND ] --|  [2]          [15] |-- [ GPIO 7 ] ---> GC9B72 CS   (Pin 7)
         [ 3V3 ] --|  [3]          [14] |-- [ GPIO 8 ]
GC9B72 - [ GPIO0] -|  [4]          [13] |-- [ GPIO 9 ]
         [ GPIO1] -|  [5]          [12] |-- [ GPIO 10] ---> WS2812B DIN (if used)
         [ GPIO2] -|  [6]          [11] |-- [ GPIO 20]
GC9B72 - [ GPIO3] -|  [7]          [10] |-- [ GPIO 21]
GC9B72 - [ GPIO4] -|  [8]          [9]  |-- [ GND    ]
GC9B72 - [ GPIO5] -|  [9]          [8]  |-- [ 5V     ]
                   +--------------------+

GC9B72 Pin 1 (VCC) ---> ESP32-C3 Pin 3 (3V3)
GC9B72 Pin 2 (GND) ---> ESP32-C3 Pin 2 (GND)
GC9B72 Pin 8 (BLK) ---> ESP32-C3 Pin 4 (GPIO 0)
GC9B72 Pin 9 (TE)  ---> NC (Leave floating / unconnected)
GC9B72 Pin 10 (SDO)---> NC (Leave floating / unconnected)
```

---

## ⚙️ Firmware Configuration & Flashing

This pinout is pre-configured in `src/config.h` under the `SCREEN_360` definition. 

To build and flash the 360×360 firmware:

```bash
pio run -e esp32c3_360 -t upload
```

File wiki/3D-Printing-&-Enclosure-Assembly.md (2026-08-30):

# 🖨️ 3D Printing & Enclosure Assembly

All enclosure CAD models for **Tiny AI Limits** are **100% support-free FDM 3D printable**, engineered with tight tolerances, anti-shadow conical bevels, and integrated cable strain reliefs.

---

## 📦 STL Model Files (`round 240x240/enclosure/`)

| File Name | Component | Function |
| :--- | :--- | :--- |
| `gc9a01_front_bezel.stl` | **Front Bezel Display Carrier** | Holds the 1.28" LCD with an anti-shadow conical aperture and M3 counterbores. |
| `gc9a01_main_housing.stl` | **Main Housing Bucket** | Encloses the ESP32-C3 SuperMini with a lowered USB-C port and M3 pilot holes. |
| `gc9a01_stand_tier1_base.stl` | **Tier 1 Base Plate** | Weighted desk footprint with 4 alignment pillars and rubber feet recesses (ideal for Wood PLA). |
| `gc9a01_stand_tier2_trunk.stl` | **Tier 2 Pedestal Trunk** | Sculpted monolithic trunk with 4 slide sockets and an $18^\circ$ ergonomic viewing V-saddle. |
| `gc9a01_desk_stand.stl` | **Unified Desk Stand** | Single-piece monolithic alternative to the two-tier pedestal. |
| `gc9a01_cyberdeck_enclosure.scad` | **Parametric OpenSCAD Source** | Full parametric source code allowing customizable dimensions and tolerances. |

---

## 🖨️ Recommended Slicer Settings

| Slicer Parameter | Recommended Value | Notes |
| :--- | :--- | :--- |
| **Material** | PLA, PETG, or Wood-filled PLA | PETG for heat resistance; Wood PLA for the base tier. |
| **Layer Height** | `0.16 mm` – `0.20 mm` | `0.16 mm` recommended for smooth conical bezel curves. |
| **Wall Loops / Perimeters** | `3` or `4` walls | Ensures strong M3 screw threading without cracking. |
| **Infill Density & Pattern** | `20%` Gyroid or Grid | Gives optimal mechanical rigidity and weight. |
| **Supports** | **NONE (Disabled)** | All overhangs and bridges are designed at $\le 45^\circ$. |
| **Brim** | Optional | Recommended for small footprint parts if bed adhesion is weak. |

---

## 🔧 Step-by-Step Mechanical Assembly

```
     [ FRONT BEZEL ]       [ GC9A01 LCD ]     [ MAIN HOUSING ]        [ 4x M3 SCREWS ]
       ┌─────────┐           ┌─────────┐        ┌─────────┐             ══════>
       │ ╭─────╮ │  <──────  │ ╭─────╮ │ <────  │ ╭─────╮ │  <────────  ══════>
       │ │ LCD │ │           │ │     │ │        │ │ ESP │ │             ══════>
       │ ╰─────╯ │           │ ╰─────╯ │        │ ╰─────╯ │             ══════>
       └─────────┘           └─────────┘        └─────────┘
                                                     │
                                                     ▼
                                          ┌──────────────────────┐
                                          │ TIER 2 PEDESTAL      │
                                          │ ($18^\circ$ V-Saddle)│
                                          └──────────┬───────────┘
                                                     │
                                                     ▼
                                          ┌──────────────────────┐
                                          │ TIER 1 BASE (Wood)   │
                                          │ + Non-slip Feet      │
                                          └──────────────────────┘
```

### 1. Mount the Display into the Front Bezel
* Gently press the GC9A01 circular display into the front bezel carrier.
* Ensure the anti-shadow conical bevel frames the active display area without obstruction.

### 2. Route Wiring into Main Housing
* Pass the soldered silicone wires and ESP32-C3 SuperMini into the main housing bucket.
* Align the USB-C port with the rear cutout in the bucket.

### 3. Fasten the Enclosure
* Mate the front bezel to the main housing.
* Secure the sandwich using four **M3 × 6mm** or **M3 × 8mm** socket head screws into the corner pilot holes. Do not overtighten.

### 4. Assemble the Two-Tier Desk Pedestal
* Insert the 4 alignment pillars of the **Tier 1 Base Plate** into the matching sockets of the **Tier 2 Pedestal Trunk**. (Use a drop of cyanoacrylate CA glue for permanent bonding if desired).
* Attach four small self-adhesive silicone/rubber bumper feet into the bottom recesses of the base plate.
* Seat the assembled display module into the $18^\circ$ tilted V-saddle cradle notch.

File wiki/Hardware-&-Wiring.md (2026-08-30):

# 🔌 Hardware & Wiring Guide

This document provides complete technical specifications, component sourcing recommendations, pinout diagrams, and assembly schematics for the **Tiny AI Limits** hardware.

---

## 🛒 Bill of Materials (BOM)

| Item | Component | Key Specification | Qty | Approx. Cost | Sourcing Links |
| :--- | :--- | :--- | :---: | :---: | :--- |
| **MCU** | ESP32-C3 SuperMini | RISC-V 160MHz, 4MB Flash, USB-C CDC, 2.4GHz Wi-Fi/BLE | 1 | \$2.50 – \$4.00 | [AliExpress](https://aliexpress.com) / [Amazon](https://amazon.com) |
| **Display** | GC9A01 1.28" IPS Round LCD | 240×240 IPS, 4-Wire Hardware SPI, 3.3V Logic | 1 | \$4.00 – \$6.50 | [Waveshare](https://waveshare.com) / [AliExpress](https://aliexpress.com) |
| **Fasteners** | M3 Socket Head Screws | M3 × 6mm or M3 × 8mm Stainless Steel | 4 | < \$1.00 | Local Hardware / Amazon |
| **Wiring** | 28–30 AWG Silicone Wire | Ultra-flexible stranded silicone wire | 7 | < \$0.50 | Generic |
| **Enclosure** | 3D Printed PETG / PLA | 2-tier stand, main bucket, front bezel | 1 set | ~\$1.00 (filament) | Self-printed |

---

## 📟 Microcontroller: ESP32-C3 SuperMini Pinout

The **ESP32-C3 SuperMini** is an ultra-compact (22.5mm × 18mm) development board featuring an Espressif ESP32-C3 RISC-V 32-bit single-core processor running at 160 MHz with native USB-C CDC serial communication.

```
                  ┌──────────────────────┐
                  │   [ USB-C CONNECTOR ]│
                  │                      │
         GPIO 0  ─┤ [ ]              [ ] ├─ 5V (VBUS)
         GPIO 1  ─┤ [ ]              [ ] ├─ GND
         GPIO 2  ─┤ [ ]              [ ] ├─ 3V3
         GPIO 3  ─┤ [ ]              [ ] ├─ GPIO 10
         GPIO 4  ─┤ [ ]              [ ] ├─ GPIO 9 (BOOT)
         GPIO 5  ─┤ [ ]              [ ] ├─ GPIO 8
         GPIO 6  ─┤ [ ]              [ ] ├─ GPIO 7
                  └──────────────────────┘
```

---

## 🖥️ GC9A01 1.28" Display Pinout & Hardware SPI

The **GC9A01** is a high-contrast circular TFT IPS LCD panel with 240×240 pixel resolution and a wide viewing angle. It communicates via high-speed 4-wire SPI (clocked at up to 40MHz in firmware).

```
   GC9A01 Pin      ESP32-C3 Pin      Signal Name       Description
 ═══════════════════════════════════════════════════════════════════════════════
   VCC             3V3               Power (3.3V)      3.3V Power Rail (Max 80mA)
   GND             GND               Ground            System Common Ground
   SCL / SCLK      GPIO 4            SPI_SCK           Hardware SPI Clock Line
   SDA / MOSI      GPIO 6            SPI_MOSI          Hardware SPI Data In (Master Out)
   DC              GPIO 7            TFT_DC            Data / Command Select Line
   CS              GPIO 5            TFT_CS            Chip Select (Active LOW)
   RST / RES       GPIO 1            TFT_RST           Hardware Display Reset
   BLK             GPIO 0 (or 3V3)   TFT_BL            Backlight PWM Dimming / Enable
 ═══════════════════════════════════════════════════════════════════════════════
```

> [!IMPORTANT]
> **Logic Level Warning:** The GC9A01 is a **3.3V logic** device. Always power the display's **VCC** from the ESP32-C3 **3V3** pin, NOT the 5V pin. Connecting 5V directly to the display logic pins will permanently damage the controller IC.

---

## 📐 Detailed Wiring Schematics

### 1. Direct Soldered Compact Assembly (Recommended for 3D Enclosure)

For the cleanest enclosure fit, use 40mm lengths of 30 AWG flexible silicone wire soldered directly between the ESP32-C3 castellated/through-hole pads and the back of the GC9A01 module.

```
       GC9A01 Circular Display                     ESP32-C3 SuperMini
   ┌──────────────────────────────┐              ┌────────────────────┐
   │ ( ) ( ) ( ) ( ) ( ) ( ) ( )  │              │                    │
   │ VCC GND SCL SDA DC  CS  RST  │              │                    │
   └──┬───┬───┬───┬───┬───┬───┬───┘              │                    │
      │   │   │   │   │   │   │                  │                    │
      │   │   │   │   │   │   └────────────────> │ GPIO 1 (RST)       │
      │   │   │   │   │   └────────────────────> │ GPIO 5 (CS)        │
      │   │   │   │   └────────────────────────> │ GPIO 7 (DC)        │
      │   │   │   └────────────────────────────> │ GPIO 6 (MOSI)      │
      │   │   └────────────────────────────────> │ GPIO 4 (SCK)       │
      │   └────────────────────────────────────> │ GND                │
      └────────────────────────────────────────> │ 3V3                │
                                                 │                    │
                                                 │ [ USB-C PORT ]     │
                                                 └────────────────────┘
```

---

## 💡 Backlight Brightness Control (PWM)

The firmware configures **GPIO 0** using the ESP32 LEDC (LED Control) hardware PWM peripheral:
* **PWM Channel:** 0
* **PWM Frequency:** 5000 Hz
* **PWM Resolution:** 8-bit (0 – 255 levels)

When `BLK` is left unconnected or bridged to `3V3`, the backlight runs at 100% full brightness. Connecting `BLK` to `GPIO 0` allows dynamic dimming and night mode schedules.

---

## ⚡ Power Supply Considerations

* **Active Consumption:** ~95 mA to 140 mA (Wi-Fi polling + 100% display backlight).
* **Peak Surge:** ~280 mA during Wi-Fi transmission bursts.
* **Recommended Supply:** Any standard USB 2.0/3.0 port or 5V 1A USB-C wall charger.

---

## 🛠️ Step-by-Step Soldering Checklist

1. **Tin the pads:** Apply lead-free solder with flux to both the GC9A01 breakout header pads and the ESP32-C3 SuperMini edge pins.
2. **Cut silicone wires:** Strip ~1.5mm insulation from each end of seven 40mm wires.
3. **Solder in order:** Begin with GND and 3V3 power rails, followed by the high-speed SPI lines (SCL, SDA), then control lines (DC, CS, RST, BLK).
4. **Insulate:** Place a small square of Kapton tape or non-conductive foam between the rear metal shielding of the display and the back of the ESP32 board to prevent short circuits when seated in the 3D-printed enclosure.

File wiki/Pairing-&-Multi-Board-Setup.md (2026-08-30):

# 🔐 Pairing & Multi-Board Setup

In a shared office, co-working space, or household with multiple developers running **Tiny AI Limits** on the same local Wi-Fi network, devices must never accidentally intercept a colleague's token telemetry or private agent states.

To ensure strict privacy and 100% deterministic device-to-workstation mapping, **Tiny AI Limits** implements a dedicated **Cryptographic Pairing Protocol**.

---

## 🛡️ The Pairing Security Model

```
       WORKSTATION A                                    WORKSTATION B
  (Companion App: pair_id_A)                       (Companion App: pair_id_B)
              │                                                │
              │  mDNS: _tinyscreen._tcp                        │  mDNS: _tinyscreen._tcp
              │  TXT: pair_id=pair_id_A                        │  TXT: pair_id=pair_id_B
              │                                                │
              ▼                                                ▼
  ┌───────────────────────┐                        ┌───────────────────────┐
  │   TINY SCREEN #1      │                        │   TINY SCREEN #2      │
  │   (NVS: pair_id_A)    │                        │   (NVS: pair_id_B)    │
  │                       │                        │                       │
  │ [PULSING GREEN CROWN] │                        │ [PULSING GREEN CROWN] │
  │   Paired to Dev A     │                        │   Paired to Dev B     │
  └───────────────────────┘                        └───────────────────────┘
```

1. **Unique Host Token (`pair_id`):** When the companion app first launches, it generates a persistent UUIDv4 token stored in `~/.tiny_ai_screen/config.json`.
2. **NVS Pinning:** During initial USB-C setup, the host's `pair_id` is written into the ESP32-C3's non-volatile storage (NVS flash partition).
3. **One-Way Cryptographic Pinning:** Once paired, the board **strictly rejects** any mDNS advertisements or HTTP responses whose `pair_id` does not match its stored token.
4. **No Cross-Talk Fallback:** If a paired board loses connection to its host, it will **never** latch onto another developer's companion app. It will display a disconnected warning until its assigned host returns.

---

## 👑 Status Crown Arc Visual Semantics

The top crown arc of the circular HUD immediately communicates network, pairing, and connection health:

```
            ╭─────────────────────────────╮
          ╭─╯   TOP CROWN STATUS ARC      ╰─╮
         ╭╯                                 ╰╮
```

| Crown Arc Visual | Connection State | Operational Meaning |
| :--- | :--- | :--- |
| 🟢 **Pulsing Emerald Green** | **Paired & Active** | Authenticated to your specific companion app. Data is 100% verified. |
| 🟡 **Solid / Pulsing Amber** | **Connected (Unpaired)** | Board is connected to Wi-Fi but has no stored `pair_id`. Falling back to first available companion. |
| 🔴 **Solid Red** | **Offline / Disconnected** | Cannot reach Wi-Fi network or host companion is unreachable. |

---

## ⚡ Pairing Methods

### Method 1: Direct Serial Setup (Recommended)
1. Plug your ESP32-C3 into your workstation via USB-C.
2. Open `http://localhost:5000/setup` in Chrome or Edge.
3. Click **"Connect Board (Direct Serial Setup)"**.
4. Enter your Wi-Fi credentials and click **"Configure & Pair"**.
5. The browser automatically injects your workstation's `pair_id` into the board's NVS over serial.

---

### Method 2: Pair an Existing / Remote Board
If your board is already connected to Wi-Fi via standard Improv-WiFi:
1. Open `http://localhost:5000/setup`.
2. Scroll to the **"Pair an Existing Board"** card.
3. Enter the board's local IP address (e.g. `192.168.1.150`).
4. Click **"Send Pair Request"**. The companion app will transmit its `pair_id` over the local network to permanently bind the device.

---

## 🔄 DHCP & IP Address Migration

If your workstation receives a new local IP address via DHCP lease renewal:
* The companion app updates its mDNS TXT record immediately.
* The ESP32-C3's background mDNS resolver matches the `pair_id` in the TXT record, extracts the new IP address, and updates its internal route table seamlessly without requiring a re-flash.

---

## 🏷️ Unique Per-Device Hostnames

To prevent DNS hostname collisions when multiple boards operate on the same subnet, each device constructs its mDNS hostname from the last 4 characters of its hardware MAC address:

$$\text{Hostname} = \texttt{tinyscreen-} + \text{MAC}[4..5] + \texttt{.local}$$

*(For example: `tinyscreen-F030.local` or `tinyscreen-8A1C.local`).*

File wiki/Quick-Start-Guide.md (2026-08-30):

# 🚀 Quick Start Guide

Get your **Tiny AI Screen** assembled, flashed, and paired with your development environment in under 15 minutes!

---

## ⏱️ What You'll Need
* **ESP32-C3 SuperMini** microcontroller board.
* **GC9A01 1.28" Circular IPS Display** (SPI interface, 240×240 resolution).
* USB-C data cable.
* 7 jumper wires (or soldering tools for direct hookup).
* Python 3.10+ installed on your host machine.
* PlatformIO CLI or VS Code PlatformIO extension.
* Google Chrome or Microsoft Edge (for WebSerial setup).

---

## Step 1: Wire the Display

Connect your GC9A01 circular display to the ESP32-C3 SuperMini using this hardware SPI pin mapping:

```
  GC9A01 Display Pin               ESP32-C3 SuperMini Pin
 ┌───────────────────┐             ┌─────────────────────┐
 │ VCC               │ ──────────> │ 3V3                 │
 │ GND               │ ──────────> │ GND                 │
 │ SCL / SCLK        │ ──────────> │ GPIO 4              │
 │ SDA / MOSI        │ ──────────> │ GPIO 6              │
 │ DC                │ ──────────> │ GPIO 7              │
 │ CS                │ ──────────> │ GPIO 5              │
 │ RST / RES         │ ──────────> │ GPIO 1              │
 │ BLK               │ ──────────> │ GPIO 0 (or 3V3)     │
 └───────────────────┘             └─────────────────────┘
```

> [!TIP]
> Connecting **BLK** to **GPIO 0** enables software backlight brightness control and dimming. If your display module does not break out BLK, it is tied internally to 3.3V.

---

## Step 2: Build & Flash the Firmware

1. **Clone the repository:**
   ```bash
   git clone https://github.com/Kimishiba/Tiny-AI-Limits.git
   cd Tiny-AI-Limits
   ```

2. **Plug in your ESP32-C3** via USB-C.

3. **Build and upload using PlatformIO:**
   ```bash
   # Build the firmware
   python -m platformio run

   # Flash the firmware over USB
   python -m platformio run --target upload
   ```

   *(Once uploaded, the screen will boot and display the initial pairing screen with a spinning circular radar animation).*

---

## Step 3: Launch the Companion Backend

The Python companion backend monitors your active AI agents, calculates rolling quotas, fetches weather, and advertises the local mDNS service.

1. **Create and activate a virtual environment:**
   ```bash
   python3 -m venv .venv
   source .venv/bin/activate  # On Windows: .venv\Scripts\activate
   ```

2. **Install requirements:**
   ```bash
   pip install -r backend/requirements.txt
   ```

3. **Launch the backend server:**
   ```bash
   python backend/app.py
   ```
   *(Or on macOS, simply double-click `TinyScreen.command`)*

The server will start at `http://localhost:5000` and begin advertising `_tinyscreen._tcp.local.` via mDNS.

---

## Step 4: WebSerial Provisioning & Gauge Pairing

1. Open **[http://localhost:5000/setup](http://localhost:5000/setup)** in **Google Chrome** or **Microsoft Edge**.
2. Click **"Connect Board (Direct Serial Setup)"**.
3. Select your ESP32-C3 serial port from the browser prompt (e.g. `usbmodem...` on macOS or `COMx` on Windows).
4. Enter your 2.4GHz Wi-Fi network SSID and Password.
5. Click **"Configure & Pair"**.

```
╔═════════════════════════════════════════════════════════════════╗
║                      PAIRING SUCCESSFUL!                        ║
║  Host Pair ID: e83f12a9-c091-49b8-a726-0e7841c5d98a             ║
║  Board Status: CONNECTED & PAIRED                               ║
║  Crown Status: Pulsing Emerald Green Arc                        ║
╚═════════════════════════════════════════════════════════════════╝
```

The device will immediately connect to your local Wi-Fi, locate your host machine via mDNS, sync its first telemetry payload, and enter active HUD mode!

---

## Step 5: Choose Your Gauges & Providers

On the **[Setup Page](http://localhost:5000/setup)**:
* **Left Gauge:** Choose between *Claude (Anthropic)*, *Google Antigravity*, *OpenRouter*, *DeepSeek*, *Groq*, *Mistral*, *Cursor*, *Copilot*, or *Gemini*.
* **Right Gauge:** Select your secondary AI provider.
* **Mode Selection:**
  * Toggle **Standard Quota Mode** (5-hour rolling reset window, percentage remaining).
  * Or toggle **Enterprise Mode** (live spend in `$`, 24-hour token volume, custom daily budget).
* **Save Preferences:** Settings apply instantly over the air.

---

## ⏭️ Next Steps
* Learn how to customize hardware and 3D print an enclosure: [[3D Printing & Enclosure Assembly|3D-Printing-&-Enclosure-Assembly]]
* Understand the multi-board collision prevention system: [[Pairing & Multi-Board Setup|Pairing-&-Multi-Board-Setup]]
* Check deep firmware internals: [[Firmware Architecture|Firmware-Architecture]]

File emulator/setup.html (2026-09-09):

TS

TINY AI SCREEN // SETUP

tv Emulator wifi WiFi Setup

settings_ethernet HARDWARE PROVISIONING

# Set Up Your Tiny AI Screen

Connect your ESP32-C3 companion device to your local Wi-Fi network directly from this browser page — zero code modification, no reflashing required.

01

Plug the ESP32-C3 board into this computer via USB-C

02

Click Connect & Set Up WiFi below and select the board's serial port

03

Enter your Wi-Fi SSID & Password in the prompt

04

The device auto-discovers this companion daemon via mDNS (_tinyscreen._tcp)

wifi Connect & Set Up WiFi

warning

Web Serial API Unavailable: Your current browser does not support Web Serial communication over USB. Please open this page in Google Chrome or Microsoft Edge on desktop.

lock

Security Context Required: Web Serial requires a secure context. Please make sure this page is accessed via http://localhost:5000/setup or over HTTPS.

READY

Device provisioning ready. Plug in your board via USB-C and click the button above.

cable Direct USB Serial Setup (Alternative)

If the button above does not list your network or reports Wi-Fi disabled, use this direct Web Serial tool:

refresh 1. Select Port & Scan Wi-Fi

link 2. Save & Connect

tune HUD GAUGE CONFIGURATION

## Select Display AI Quotas

Choose which 2 AI services are mapped to the physical GC9A01 dual radial HUD arcs (Left Gauge & Right Gauge). The backend automatically scans local credentials and tokens across your active tools.

arrow_back Left Radial Arc (Gauge 1)

Detecting...

Gauge 1 Mode / Plan:

Daily Budget:

arrow_forward Right Radial Arc (Gauge 2)

Detecting...

Gauge 2 Mode / Plan:

Daily Budget:

account_balance_wallet Anthropic Claude Telemetry & Plan Settings

Claude Account Plan:

Enterprise mode displays live 24h token volume on the HUD gauge.

Daily Spending Budget ($ USD):

Target budget for the left radial gauge fill ring ($0.00 → $10.00).

save Save Gauge Selection

lightbulb WS2812B AMBIENT & STATUS LEDS

## Agent Waiting Animation

Configure the physical WS2812B LED alert played on your desk whenever an AI agent pauses and requires human confirmation or input.

Animation Style:

Brightness (0% – 100%):

Hardware-clamped to protect USB current budgets (≤ 250mA).

Number of LEDs (1 – 64):

Exact count for individual LEDs, strips, or rings (e.g. 1, 4, 8, 16).

SAVE LED CONFIGURATION

link PAIR AN EXISTING BOARD

## Pair a Board to This Computer

Setting up over USB above pairs the board automatically. Use this only if you set the board up with Connect & Set Up WiFi (which can only send Wi-Fi credentials), or if this computer's address changed and the board can no longer find it. Enter the board's address — shown at the end of the Wi-Fi setup dialog, and printed on the board's serial output at boot.

link Pair Board

DISCOVERY PROTOCOL

sensors Zero-Config mDNS

No hardcoded IPs or manual gateway configuration. The board browses _tinyscreen._tcp and pairs automatically.

RUNTIME COMPATIBILITY

memory ESP32-C3 RISC-V

Standardized Improv-WiFi protocol with brownout-tuned RF power and WPA2/WPA3 PMF auto-negotiation.

STATUS SYNCHRONIZATION

sync Live Token Gauges

Streams real-time Antigravity 5h quotas, Claude Code usage, and animated robot expressions directly to the display.

TINY AI SCREEN // NEO-RAW

Emulator WiFi Setup Firmware Docs (https://github.com)

© 2026 TINY AI SCREEN. NEO-RAW SYSTEM DESIGN.

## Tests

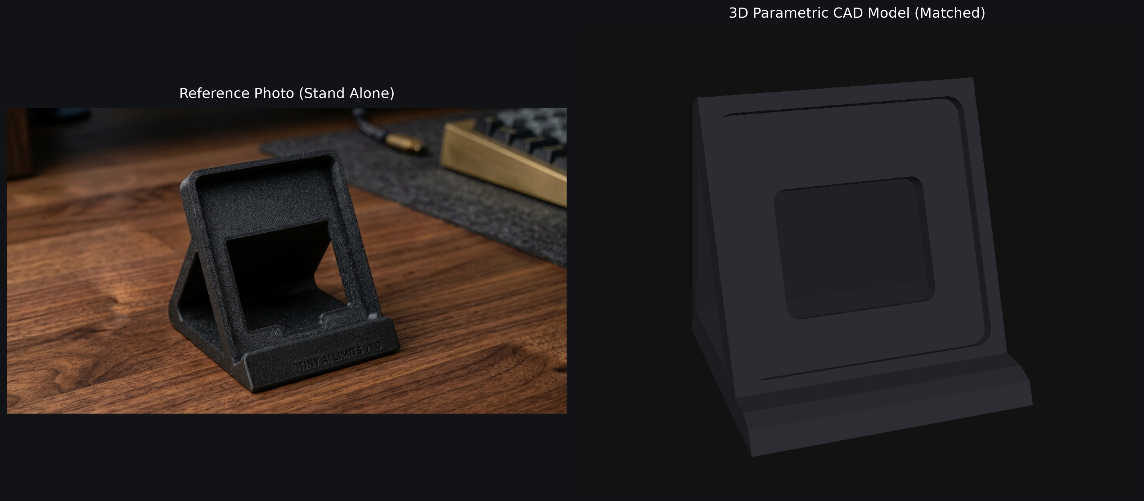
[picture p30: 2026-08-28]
round 240x240/assets/stand_verification_render.png

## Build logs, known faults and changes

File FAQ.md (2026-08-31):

# Frequently Asked Questions (FAQ)

## What is Tiny AI Limits & Desktop Companion?

It is an open-source, Wi-Fi enabled desktop telemetry companion powered by the ultra-compact ESP32-C3 SuperMini microcontroller. It brings your AI developer environment to life with physical desktop hardware — monitoring real-time token quotas, **daily USD ($) spend**, and token telemetry across **Anthropic Claude**, **Google Antigravity**, **OpenRouter**, **DeepSeek**, and more, alerting you when AI agents require plan approvals, and serving as an expressive animated desk companion and synchronized clock.

## Which display does the hardware use?

There is a single build: the **GC9A01 1.28" Circular IPS Cyberdeck Edition**, an industrial sci-fi desktop pod featuring a vibrant 1.28" Circular 240×240 IPS Color Display driven over SPI.

## Which microcontroller is used?

The project uses the ultra-compact **ESP32-C3 SuperMini** microcontroller.

## Where can I find the Bill of Materials (BOM) and purchase parts?

The comprehensive Bill of Materials (BOM) with verified purchasing links can be found in `BOM/BOM.md`, and quick-start shopping kits can be found in `BOM/README.md`.

## Are 3D printable enclosures available?

Yes, all enclosure CAD models are 100% support-free FDM 3D printable and available in both parametric OpenSCAD sources and verified watertight STLs in the `round 240x240/enclosure/` directory.

## How do I build and flash the firmware?

You can use PlatformIO to build and flash the firmware over USB-C. First, install PlatformIO, then run:

```bash
python -m platformio run
python -m platformio run --target upload
```

## How do I set up Wi-Fi on the device?

With the device plugged in via USB-C, open `http://localhost:5000/setup` in Google Chrome or Microsoft Edge (which use the Web Serial API). Use the "Direct Serial Setup" section: select the board's serial port, scan for networks, and enter your Wi-Fi credentials. The device saves them to flash, and the same step pairs it to your computer.

## Why does my board show someone else's token quotas?

This happens when more than one person runs the companion app on the same Wi-Fi. Older firmware asked the network "who is running a companion app?" and used whichever answered first — which could be a colleague's machine.

The fix is **pairing**: your board stores your computer's address and a `pair_id`, and talks only to that machine. Re-run "Direct Serial Setup" on `http://localhost:5000/setup` to pair a board, or use the "Pair an Existing Board" box if the board is already on Wi-Fi.

If you set the board up with the "Connect & Set Up WiFi" button, it is **not** paired — that protocol can only carry Wi-Fi credentials. Use the "Pair an Existing Board" box afterwards.

## How can I tell whether my board is paired?

Watch the status arc at the top of the display: pulsing green means paired & connected, **amber** means connected but unpaired, and red means no connection.

Unpaired means the board is reading from whichever companion app answered first, so on a shared network the figures may not be yours.

You can also send `STATUS` over the serial console, which reports `paired_host` and `pair_id`.

## My board stopped finding the companion app after a router restart

Your computer's IP probably changed. A paired board re-finds it automatically by matching its `pair_id` against the mDNS records, usually within a minute.

If it does not recover, check that the companion app is running, then re-pair with the "Pair an Existing Board" box on the setup page using the board's IP.

A board that has been paired will **not** fall back to picking another companion app, even if it can no longer reach its own. It shows no data and waits to be re-paired. That is deliberate: showing nothing is better than showing someone else's numbers.

## Can I run several boards on one network?

Yes. Each board derives a unique hostname from its MAC address (for example `tinyscreen-F030.local`), so they will not clash with each other.

## How do I rotate the display for different mounting or cable routing orientations?

You can rotate the screen orientation in 90° increments at any time:
- **macOS Menu Bar:** Click the companion app status icon (`🖥️`) and select **🔄 Screen Orientation** to pick `0° (Standard)`, `90° (Clockwise)`, `180° (Inverted)`, or `270° (Counter-Clockwise)`.
- **Browser Emulator / REST API:** Click the **🔄 ROTATE** button on `http://localhost:5000/emulator` or issue a `POST /api/rotate` request.
- The ESP32 screen automatically updates its orientation on the next telemetry poll and saves the setting to flash memory (NVS) so it persists through power cycles.

The board prints its hostname on the serial console at boot, and the setup page reports it when you connect over serial.

## How does Enterprise / Spend Mode work for users without hourly quotas?

If you are on an Enterprise, Team, or Pay-As-You-Go account (such as Anthropic Claude Enterprise or custom API keys), you do not have a 5-hour rolling limit.

In **Enterprise Mode**, the companion app:
1. Replaces the percentage remaining with your live **USD ($) expenditure** for the day (`$0.13`).
2. Displays your total 24-hour token volume in the footer (`28.2k TOK`).
3. Tracks your progress against a configurable **Daily Budget ($ USD)** on the radial arc.

You can switch between **Standard Quota** and **Enterprise Mode** for any provider on the Web Setup page at `http://localhost:5000/setup`.

## How are model token prices calculated?

The companion backend automatically calculates model-specific pricing per 1,000,000 tokens for all assistant turns executed locally within the day:
* **Claude 3.7 Sonnet / 3.5 Sonnet:** \$3.00 input / \$15.00 output / \$3.75 cache write / \$0.30 cache read
* **Claude 3.5 Haiku:** \$0.80 input / \$4.00 output / \$1.00 cache write / \$0.08 cache read
* **Claude 3 Opus:** \$15.00 input / \$75.00 output / \$18.75 cache write / \$1.50 cache read

## Can I track cloud LLMs like OpenRouter or DeepSeek?

Yes! You can independently assign the Left and Right radial arcs to any supported provider:
* **Local CLIs (zero-config):** Anthropic Claude Code, Google Antigravity.
* **Cloud API Services:** OpenRouter, DeepSeek, Mistral, Groq (just enter your API key in `http://localhost:5000/setup`).

## Can I test the interface without building the physical hardware?

Yes! The project includes an interactive browser prototype and visualizer where you can preview and interact with all screens, animations, and telemetry states in real time:

- **Full Display Emulator**: `http://localhost:5000/emulator`

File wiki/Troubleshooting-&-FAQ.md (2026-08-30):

# 🩺 Troubleshooting & Frequently Asked Questions (FAQ)

Find quick solutions to common hardware, firmware, network, and companion setup issues.

---

## 🔍 Diagnostic Matrix & Troubleshooting Guide

### 1. Hardware & Flashing Issues

#### ❓ The ESP32-C3 port does not appear or PlatformIO fails to upload
* **Cause:** Native USB CDC is in an unbooted state or wrong USB cable.
* **Fix:**
  1. Ensure you are using a **data-capable USB-C cable**, not a charge-only cable.
  2. Hold down the **BOOT** button (GPIO 9) on the ESP32-C3 SuperMini, plug in the USB-C cable, release BOOT, then run `python -m platformio run --target upload`.
  3. On Linux, ensure your user belongs to `dialout`: `sudo usermod -a -G dialout $USER`.

#### ❓ Display is blank/black or backlight does not turn on
* **Cause:** Power rail not connected or `BLK` pin floating.
* **Fix:**
  1. Verify display `VCC` is connected to ESP32 **3V3** (not 5V) and `GND` to **GND**.
  2. If `BLK` is unconnected, wire `BLK` to `GPIO 0` or bridge `BLK` to `3V3` to force full backlight illumination.

#### ❓ Screen shows white noise, static, or scrambled pixels
* **Cause:** SPI clock speed too high for wire lengths, or loose `MOSI`/`SCLK` connection.
* **Fix:**
  1. Check your solder joints on `GPIO 4` (SCLK) and `GPIO 6` (MOSI).
  2. In `platformio.ini`, try lowering `-DSPI_FREQUENCY=40000000` to `27000000`.

---

### 2. Network & mDNS Issues

#### ❓ Board fails to connect to Wi-Fi
* **Cause:** Network is 5 GHz only or captive portal.
* **Fix:**
  * ESP32-C3 microcontrollers only support **2.4 GHz Wi-Fi** (802.11 b/g/n). Ensure you connect to a 2.4 GHz SSID. Enterprise WPA2 networks with RADIUS or web captive portals are not supported.

#### ❓ Board connects to Wi-Fi but displays a Red Crown Arc (Host Disconnected)
* **Cause:** mDNS (`_tinyscreen._tcp.local`) is blocked across router subnets or host firewall.
* **Fix:**
  1. Ensure the Python companion app (`python backend/app.py`) is running on your workstation.
  2. Verify your workstation and ESP32 are on the exact same Wi-Fi subnet / router.
  3. If your network router blocks multicast DNS packets (common on corporate/guest networks), navigate to `http://localhost:5000/setup` and use **"Pair an Existing Board"** by entering the device IP directly.

---

### 3. Pairing & Multi-Board Issues

#### ❓ Board shows an Amber Crown Arc instead of Green
* **Cause:** The board is connected to Wi-Fi and reading data via unauthenticated mDNS fallback, but has not been paired with a unique `pair_id`.
* **Fix:**
  * Open `http://localhost:5000/setup` in Chrome/Edge, click **"Connect Board (Direct Serial Setup)"**, and click **"Configure & Pair"**. Once the `pair_id` is written to NVS, the crown will pulse Emerald Green.

#### ❓ How do I completely factory-reset a board?
* **Fix:** Connect via WebSerial or serial monitor (`115200` baud) and send the text command:
  ```text
  RESET
  ```
  This will wipe all stored NVS Wi-Fi credentials and pairing UUIDs, rebooting the device into initial pairing radar mode.

---

## 💬 Frequently Asked Questions (FAQ)

### Can I use a square or rectangular display instead of the GC9A01 circular display?
Yes! The repository also includes ST7789 240×240 square display and SSD1306 OLED drivers in earlier branches. However, the radial HUD gauges and circular crown arc are specifically optimized for the 1.28" GC9A01 round IPS display.

### Can I track custom API spend limits from local LLMs (Ollama / vLLM)?
Yes. You can implement a custom provider class inside `backend/providers/` inheriting from `BaseProvider`. The companion backend will automatically load and expose it to the `/setup` configuration dropdown.

### Does the Python companion backend require root or administrator privileges?
No. The backend runs completely as a standard user process and requires no special privileges.

### How much power does the device consume?
Between 95 mA and 140 mA at 5V (~0.5W to 0.7W), making it safe to power from any USB port on your PC, monitor hub, or desk charger.

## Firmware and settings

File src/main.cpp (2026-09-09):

#include <Arduino.h>
#include <SPI.h>
#include <Arduino_GFX_Library.h>
#include <font/glcdfont.h>
#include <WiFi.h>
#include <ESPmDNS.h>
#include <HTTPClient.h>
#include <WebServer.h>
#include <DNSServer.h>
#include <ArduinoJson.h>
#include <esp_wifi.h>
#include <Preferences.h>
#include <ImprovWiFiLibrary.h>
#include <Update.h>
#include <atomic>
#include <memory>
#include "boot_logo.h"
#include "config.h"
#include "drivers/led_controller.h"

DNSServer dnsServer;

#if defined(SCREEN_360) || defined(SCREEN_GC9B72_360)
#include "drivers/display_gc9b72.h"
Arduino_DataBus *gcBus = createGC9B72Bus();
Arduino_GFX *gcGfx = createGC9B72Display(gcBus);
#else
#include "drivers/display_gc9a01.h"
Arduino_DataBus *gcBus = createGC9A01Bus();
Arduino_GFX *gcGfx = createGC9A01Display(gcBus);
#endif

bool gc9a01Initialized = false;
int currentDisplayRotation = 0;
std::atomic<bool> globalForceRedraw{false};
static SemaphoreHandle_t spiMutex = NULL;
static SemaphoreHandle_t stateMutex = NULL;
static TaskHandle_t backendTaskHandle = NULL;
static std::atomic<bool> isOTAInProgress{false};

// Zero-allocation templated wrapper guarding SPI bus access
template <typename F>
inline void safeGfxOperation(F&& gfxFunc) {
    if (!spiMutex || xSemaphoreTake(spiMutex, pdMS_TO_TICKS(100)) == pdTRUE) {
        gfxFunc();
        if (spiMutex) xSemaphoreGive(spiMutex);
    }
}

// Zero-allocation templated wrapper guarding shared telemetry & state structs
template <typename F>
inline void safeStateOperation(F&& stateFunc) {
    if (!stateMutex || xSemaphoreTake(stateMutex, pdMS_TO_TICKS(50)) == pdTRUE) {
        stateFunc();
        if (stateMutex) xSemaphoreGive(stateMutex);
    }
}

WebServer server(80);

ClaudeLimits claudeData;
AntigravityLimits agData;
GaugeInfo leftGauge;
GaugeInfo rightGauge;
WeatherInfo weatherData;
AgentStatus agentData;
TimeInfo timeData;
LedConfig ledConfig;
LedController ledController(WS2812_PIN, WS2812_MAX_LEDS, WS2812_DEFAULT_ACTIVE_LEDS);

long lastKnownTokensToday = -1;
unsigned long lastTokenActivityMs = 0;

unsigned long lastBackendPoll = 0;
unsigned long lastBackendPollSuccessMs = 0;

bool wifiConnected = false;
bool backendConnected = false;
String backendUrl = "";

// Pairing: which companion app this board belongs to. When pairedHost is set
// the board talks only to that host and never falls back to picking whichever
// companion answers mDNS first, which is how it used to end up showing
// another user's quota data on a shared network.
String pairedHost = "";
uint16_t pairedPort = 0;
String pairedId = "";
// Latch: set the first time a board is ever paired and never cleared. A board
// that has been paired once must not fall back to first-responder discovery
// again, even if its stored host later stops answering -- that fallback is
// what let it pick up another user's companion app.
bool everPaired = false;
Preferences pairPrefs;

// Defined with the data-fetching code below, used by the web server above it.
bool savePairing(const String& host, uint16_t port, const String& id);
bool isValidIPv4(const String& s);
void applyPairedBackendUrl();
String deviceHostname();

Preferences wifiPrefs;
ImprovWiFi improvSerial(&Serial);
bool provisioningMode = false;

// ==========================================
// FACE & BLINKING ANIMATION ENGINE
// ==========================================
enum BlinkPhase {
    EYES_OPEN,
    EYES_CLOSING,
    EYES_CLOSED,
    EYES_OPENING
};

struct FaceEngine {
    BlinkPhase blinkPhase = EYES_OPEN;
    unsigned long phaseStartTime = 0;
    unsigned long nextBlinkTime = 2500;
    float currentOpenPct = 1.0f;

    int targetPupilX = 0;
    int targetPupilY = 0;
    float currentPupilX = 0.0f;
    float currentPupilY = 0.0f;
    unsigned long nextLookTime = 3000;

    bool isDoubleBlink = false;
    int blinkCountInBurst = 0;
};

FaceEngine face;
unsigned long animTicks = 0;

void updateFacePhysics(unsigned long now) {
    animTicks++;

    switch (face.blinkPhase) {
        case EYES_OPEN:
            face.currentOpenPct = 1.0f;
            if (now >= face.nextBlinkTime) {
                face.blinkPhase = EYES_CLOSING;
                face.phaseStartTime = now;
            }
            break;

        case EYES_CLOSING: {
            unsigned long elapsed = now - face.phaseStartTime;
            if (elapsed >= 30) {
                face.blinkPhase = EYES_CLOSED;
                face.phaseStartTime = now;
                face.currentOpenPct = 0.08f;
            } else {
                face.currentOpenPct = 1.0f - (float)elapsed / 30.0f * 0.92f;
            }
            break;
        }

        case EYES_CLOSED: {
            unsigned long elapsed = now - face.phaseStartTime;
            face.currentOpenPct = 0.08f;
            if (elapsed >= 38) {
                face.blinkPhase = EYES_OPENING;
                face.phaseStartTime = now;
            }
            break;
        }

        case EYES_OPENING: {
            unsigned long elapsed = now - face.phaseStartTime;
            if (elapsed >= 38) {
                face.blinkPhase = EYES_OPEN;
                face.currentOpenPct = 1.0f;
                face.blinkCountInBurst++;

                if (!face.isDoubleBlink && random(0, 100) < 25 && face.blinkCountInBurst < 2) {
                    face.isDoubleBlink = true;
                    face.nextBlinkTime = now + random(75, 180);
                } else {
                    face.isDoubleBlink = false;
                    face.blinkCountInBurst = 0;
                    face.nextBlinkTime = now + random(1800, 4000);
                }
            } else {
                face.currentOpenPct = 0.08f + (float)elapsed / 38.0f * 0.92f;
            }
            break;
        }
    }

    if (now >= face.nextLookTime) {
        int r = random(0, 100);
        if (r < 40) {
            face.targetPupilX = 0;
            face.targetPupilY = 0;
        } else if (r < 60) {
            face.targetPupilX = random(-5, 6);
            face.targetPupilY = 0;
        } else if (r < 80) {
            face.targetPupilX = random(-5, 6);
            face.targetPupilY = random(-2, 3);
        } else {
            face.targetPupilX = 0;
            face.targetPupilY = random(-2, 3);
        }
        face.nextLookTime = now + random(1500, 5000);
    }

    face.currentPupilX += (face.targetPupilX - face.currentPupilX) * 0.25f;
    face.currentPupilY += (face.targetPupilY - face.currentPupilY) * 0.25f;
}

// ==========================================
// GC9A01 (240x240 ROUND) C++ RENDERING ENGINE
// ==========================================
#define GC_COLOR_BLACK       0x0000
#define GC_COLOR_WHITE       0xFFFF
#define GC_COLOR_CYAN        0x073F // Electric Cyan (#00E5FF)
#define GC_COLOR_ORANGE      0xFD20 // Safety Orange (#FF7A00)
#define GC_COLOR_AMBER       0xFDC0 // Hazard Amber (#FFB800)
#define GC_COLOR_YELLOW      0xFFE0 // Neon Spark Yellow
#define GC_COLOR_CARD_TOP    0x2126 // Lighter Slate (#222633)
#define GC_COLOR_CARD_BOT    0x10A3 // Deeper Obsidian (#12141C)
#define GC_COLOR_CARD_BORDER 0x2988 // Border Slate (#2B3042)
#define GC_COLOR_SLATE_GRAY  0x9D37 // Muted Slate (#94A3B8)
#define GC_COLOR_ICE_BLUE    0x3DFE // Weather Rain Blue (#38BDF8)
#define GC_COLOR_DARK_AMBER  0x2080
#define GC_COLOR_RED         0xF800 // Safety Red (#FF0000)

// Digit transition flip states
int prevDigits[4] = {-1, -1, -1, -1};
float flipProgress[4] = {1.0f, 1.0f, 1.0f, 1.0f};

// Vector 7-segment / condensed numeral drawing
// High-Resolution Heavy Bold Vector Numerals (28px wide, 54px tall, 8px ultra-bold strokes)
void drawVectorDigit(int x, int y, int digit, uint16_t color) {
    int t = 8;
    int w = 28;
    int h = 54;
    int midY = y + h / 2 - t / 2;
    int botY = y + h - t;
    int rightX = x + w - t;

    switch (digit) {
        case 0:
            gcGfx->fillRoundRect(x, y, w, t, 2, color);
            gcGfx->fillRoundRect(x, botY, w, t, 2, color);
            gcGfx->fillRoundRect(x, y, t, h, 2, color);
            gcGfx->fillRoundRect(rightX, y, t, h, 2, color);
            break;
        case 1:
            gcGfx->fillRoundRect(x + (w - t) / 2, y, t, h, 2, color);
            gcGfx->fillRoundRect(x + (w - t) / 2 - 7, y, 7, t, 1, color);
            gcGfx->fillRoundRect(x + 2, botY, w - 4, t, 1, color);
            break;
        case 2:
            gcGfx->fillRoundRect(x, y, w, t, 2, color);
            gcGfx->fillRoundRect(rightX, y, t, h / 2 + 2, 2, color);
            gcGfx->fillRoundRect(x, midY, w, t, 2, color);
            gcGfx->fillRoundRect(x, midY, t, h / 2 + 2, 2, color);
            gcGfx->fillRoundRect(x, botY, w, t, 2, color);
            break;
        case 3:
            gcGfx->fillRoundRect(x, y, w, t, 2, color);
            gcGfx->fillRoundRect(rightX, y, t, h, 2, color);
            gcGfx->fillRoundRect(x + 4, midY, w - 4, t, 2, color);
            gcGfx->fillRoundRect(x, botY, w, t, 2, color);
            break;
        case 4:
            gcGfx->fillRoundRect(x, y, t, h / 2 + 2, 2, color);
            gcGfx->fillRoundRect(x, midY, w, t, 2, color);
            gcGfx->fillRoundRect(rightX, y, t, h, 2, color);
            break;
        case 5:
            gcGfx->fillRoundRect(x, y, w, t, 2, color);
            gcGfx->fillRoundRect(x, y, t, h / 2 + 2, 2, color);
            gcGfx->fillRoundRect(x, midY, w, t, 2, color);
            gcGfx->fillRoundRect(rightX, midY, t, h / 2 + 2, 2, color);
            gcGfx->fillRoundRect(x, botY, w, t, 2, color);
            break;
        case 6:
            gcGfx->fillRoundRect(x, y, w, t, 2, color);
            gcGfx->fillRoundRect(x, y, t, h, 2, color);
            gcGfx->fillRoundRect(x, midY, w, t, 2, color);
            gcGfx->fillRoundRect(rightX, midY, t, h / 2 + 2, 2, color);
            gcGfx->fillRoundRect(x, botY, w, t, 2, color);
            break;
        case 7:
            gcGfx->fillRoundRect(x, y, w, t, 2, color);
            gcGfx->fillRoundRect(rightX, y, t, h, 2, color);
            break;
        case 8:
            gcGfx->fillRoundRect(x, y, w, t, 2, color);
            gcGfx->fillRoundRect(x, botY, w, t, 2, color);
            gcGfx->fillRoundRect(x, midY, w, t, 2, color);
            gcGfx->fillRoundRect(x, y, t, h, 2, color);
            gcGfx->fillRoundRect(rightX, y, t, h, 2, color);
            break;
        case 9:
            gcGfx->fillRoundRect(x, y, w, t, 2, color);
            gcGfx->fillRoundRect(x, y, t, h / 2 + 2, 2, color);
            gcGfx->fillRoundRect(x, midY, w, t, 2, color);
            gcGfx->fillRoundRect(rightX, y, t, h, 2, color);
            gcGfx->fillRoundRect(x, botY, w, t, 2, color);
            break;
        default:
            break;
    }
}

void drawVectorDigitHalf(int x, int y, int digit, uint16_t color, bool topHalfOnly, float yScale = 1.0f) {
    int t = 8;
    int w = 28;
    int h = (int)(54 * yScale);
    if (h < 2) return;
    int midY = y + h / 2 - t / 2;
    int botY = y + h - t;
    int rightX = x + w - t;

    auto drawBar = [&](int bx, int by, int bw, int bh, int r) {
        int clipY = y + h / 2;
        int endY = by + bh;
        if (topHalfOnly) {
            if (by >= clipY) return;
            if (endY > clipY) bh = clipY - by;
        } else {
            if (endY <= clipY) return;
            if (by < clipY) {
                bh = endY - clipY;
                by = clipY;
            }
        }
        if (bw <= 0 || bh <= 0) return;
        gcGfx->fillRoundRect(bx, by, bw, bh, r, color);
    };

    switch (digit) {
        case 0:
            drawBar(x, y, w, t, 2);
            drawBar(x, botY, w, t, 2);
            drawBar(x, y, t, h, 2);
            drawBar(rightX, y, t, h, 2);
            break;
        case 1:
            drawBar(x + (w - t) / 2, y, t, h, 2);
            drawBar(x + (w - t) / 2 - 7, y, 7, t, 1);
            drawBar(x + 2, botY, w - 4, t, 1);
            break;
        case 2:
            drawBar(x, y, w, t, 2);
            drawBar(rightX, y, t, h / 2 + 2, 2);
            drawBar(x, midY, w, t, 2);
            drawBar(x, midY, t, h / 2 + 2, 2);
            drawBar(x, botY, w, t, 2);
            break;
        case 3:
            drawBar(x, y, w, t, 2);
            drawBar(rightX, y, t, h, 2);
            drawBar(x + 4, midY, w - 4, t, 2);
            drawBar(x, botY, w, t, 2);
            break;
        case 4:
            drawBar(x, y, t, h / 2 + 2, 2);
            drawBar(x, midY, w, t, 2);
            drawBar(rightX, y, t, h, 2);
            break;
        case 5:
            drawBar(x, y, w, t, 2);
            drawBar(x, y, t, h / 2 + 2, 2);
            drawBar(x, midY, w, t, 2);
            drawBar(rightX, midY, t, h / 2 + 2, 2);
            drawBar(x, botY, w, t, 2);
            break;
        case 6:
            drawBar(x, y, w, t, 2);
            drawBar(x, y, t, h, 2);
            drawBar(x, midY, w, t, 2);
            drawBar(rightX, midY, t, h / 2 + 2, 2);
            drawBar(x, botY, w, t, 2);
            break;
        case 7:
            drawBar(x, y, w, t, 2);
            drawBar(rightX, y, t, h, 2);
            break;
        case 8:
            drawBar(x, y, w, t, 2);
            drawBar(x, botY, w, t, 2);
            drawBar(x, midY, w, t, 2);
            drawBar(x, y, t, h, 2);
            drawBar(rightX, y, t, h, 2);
            break;
        case 9:
            drawBar(x, y, w, t, 2);
            drawBar(x, y, t, h / 2 + 2, 2);
            drawBar(x, midY, w, t, 2);
            drawBar(rightX, y, t, h, 2);
            drawBar(x, botY, w, t, 2);
            break;
        default:
            break;
    }
}

// Helper function for pixel-perfect centered text in Adafruit_GFX / Arduino_GFX
void gcPrintCentered(const char* str, int centerX, int y, uint16_t color) {
    if (!str) return;
    int len = strlen(str);
    int textW = len * 6 - 1;
    gcGfx->setTextColor(color);
    gcGfx->setCursor(centerX - textW / 2, y);
    gcGfx->print(str);
}

// Draw individual 5x7 character rotated tangent to a circle (tangent upwards/clockwise, top facing outwards)
void drawRotatedCurvedChar(char c, int cx, int cy, float radius, float angleDeg, uint16_t color) {
    if (c < 32 || c > 126) return;
    int charIdx = (int)c;

    float rad = angleDeg * 0.0174532925f;
    float charCenterX = (float)cx + cosf(rad) * radius;
    float charCenterY = (float)cy + sinf(rad) * radius;

    // Tangent vector pointing upwards / clockwise along the left perimeter (angleDeg + 90 deg)
    float cosT = cosf((angleDeg + 90.0f) * 0.0174532925f);
    float sinT = sinf((angleDeg + 90.0f) * 0.0174532925f);
    // Normal vector pointing outwards towards bezel (angleDeg)
    float cosN = cosf(rad);
    float sinN = sinf(rad);

    for (int col = 0; col < 5; col++) {
        uint8_t line = pgm_read_byte(&font[charIdx * 5 + col]);
        float dx = (float)(col - 2); // along tangent
        for (int row = 0; row < 7; row++) {
            if (line & 0x01) {
                float dy = (float)(row - 3); // along normal: negative = towards bezel (top of char), positive = towards center (bottom)
                int px = (int)roundf(charCenterX + dx * cosT - dy * cosN);
                int py = (int)roundf(charCenterY + dx * sinT - dy * sinN);
                gcGfx->drawPixel(px, py, color);
            }
            line >>= 1;
        }
    }
}

// Draw a string curving smoothly along the left circular perimeter starting from the bottom up to the top
void drawRotatedCurvedString(const char* str, int cx, int cy, float radius, float startDeg, float stepDeg, uint16_t color) {
    if (!str) return;
    int len = strlen(str);
    for (int i = 0; i < len; i++) {
        float charAngle = startDeg + (i * stepDeg);
        drawRotatedCurvedChar(str[i], cx, cy, radius, charAngle, color);
    }
}

void drawGC9A01AnimatedFlipCard(int posX, int posY, int cardW, int cardH, int oldDigit, int newDigit, float progress) {
    int midY = posY + cardH / 2;
    int halfH = cardH / 2;

    uint16_t colTop = gcGfx->color565(34, 38, 51);     // #222633 Slate Top
    uint16_t colBot = gcGfx->color565(18, 20, 28);     // #12141C Obsidian Bot
    uint16_t colBorder = gcGfx->color565(43, 48, 66);  // #2B3042 Card Border
    uint16_t colSeam = gcGfx->color565(52, 58, 78);    // #343A4E Crease Line
    uint16_t colLug = gcGfx->color565(18, 21, 31);     // #12151F Lug Bracket
    uint16_t colPin = gcGfx->color565(138, 150, 171);  // #8A96AB Steel Pin

    int numX = posX + (cardW - 28) / 2;
    int numY = posY + (cardH - 54) / 2;

    if (progress >= 1.0f || oldDigit == newDigit) {
        // Static resting card
        gcGfx->fillRoundRect(posX, posY, cardW, halfH, 4, colTop);
        gcGfx->fillRoundRect(posX, midY, cardW, halfH, 4, colBot);
        gcGfx->drawRoundRect(posX, posY, cardW, cardH, 4, colBorder);

        gcGfx->drawFastHLine(posX + 1, midY - 1, cardW - 2, GC_COLOR_BLACK);
        gcGfx->drawFastHLine(posX + 1, midY, cardW - 2, colSeam);

        drawVectorDigit(numX, numY, newDigit, GC_COLOR_WHITE);
        gcGfx->drawFastHLine(posX + 2, midY, cardW - 4, GC_COLOR_BLACK);
    } else {
        // --- 3D PERSPECTIVE FLIP ANIMATION ---
        // 1. Static Top Background (Shows NEW digit)
        gcGfx->fillRoundRect(posX, posY, cardW, halfH, 4, colTop);
        drawVectorDigitHalf(numX, numY, newDigit, GC_COLOR_WHITE, true);

        // 2. Static Bottom Background (Shows OLD digit)
        gcGfx->fillRoundRect(posX, midY, cardW, halfH, 4, colBot);
        drawVectorDigitHalf(numX, numY, oldDigit, gcGfx->color565(236, 238, 244), false);

        // 3. Falling / Unfolding 3D Flap
        if (progress < 0.5f) {
            // Phase 1: Top half of OLD digit folds downward
            float scale = cos(progress * 3.14159f); // 1.0 -> 0.0
            int flapH = max(1, (int)(halfH * scale));
            int flapY = midY - flapH;

            // Redraw top visible part
            gcGfx->fillRect(posX, posY, cardW, halfH - flapH, colTop);
            drawVectorDigitHalf(numX, numY, newDigit, GC_COLOR_WHITE, true);

            // Draw falling flap
            gcGfx->fillRect(posX, flapY, cardW, flapH, colTop);
            drawVectorDigitHalf(numX, flapY, oldDigit, GC_COLOR_WHITE, true, scale);
        } else {
            // Phase 2: Bottom half of NEW digit unfolds downward
            float scale = -cos(progress * 3.14159f); // 0.0 -> 1.0
            int flapH = max(1, (int)(halfH * scale));

            // Redraw bottom visible part
            gcGfx->fillRect(posX, midY + flapH, cardW, halfH - flapH, colBot);
            drawVectorDigitHalf(numX, numY, oldDigit, gcGfx->color565(236, 238, 244), false);

            // Draw unfolding flap
            gcGfx->fillRect(posX, midY, cardW, flapH, colBot);
            drawVectorDigitHalf(numX, midY - (int)(26 * scale), newDigit, gcGfx->color565(236, 238, 244), false, scale);
        }

        // Draw borders & seam
        gcGfx->drawRoundRect(posX, posY, cardW, cardH, 4, colBorder);
        gcGfx->drawFastHLine(posX + 1, midY - 1, cardW - 2, GC_COLOR_BLACK);
        gcGfx->drawFastHLine(posX + 1, midY, cardW - 2, colSeam);
    }

    // Flank retention hinge brackets (lug width = 4, height = 10, extending 2px outside)
    gcGfx->fillRoundRect(posX - 2, midY - 5, 4, 10, 1, colLug);
    gcGfx->drawRoundRect(posX - 2, midY - 5, 4, 10, 1, colBorder);
    gcGfx->drawFastHLine(posX - 1, midY, 2, colPin);

    gcGfx->fillRoundRect(posX + cardW - 2, midY - 5, 4, 10, 1, colLug);
    gcGfx->drawRoundRect(posX + cardW - 2, midY - 5, 4, 10, 1, colBorder);
    gcGfx->drawFastHLine(posX + cardW - 1, midY, 2, colPin);
}
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
void loop() {
    if (isOTAInProgress || !gc9a01Initialized) {
        vTaskDelay(pdMS_TO_TICKS(50));
        return;
    }

    unsigned long now = millis();

    // 1. Unified Serial Listener (Direct & Improv) & Web Server
    handleSerialCommunication();
    if (wifiConnected) {
        server.handleClient();
    }

    // 2. Render Active Display (Uninterrupted ~30 FPS rendering)
    if (now - lastFrameTime >= frameIntervalMs) {
        lastFrameTime = now;

        // GC9A01 Round IPS HUD (Render full cyberpunk flip clock HUD)
        safeGfxOperation([now]() {
            updateFacePhysics(now);
            drawGC9A01RoundFlipUI();
        });
    }

    // 3. Auto-reconnect Wi-Fi
    static unsigned long lastWiFiCheck = 0;
    if (now - lastWiFiCheck >= 20000) {
        lastWiFiCheck = now;
        if (WiFi.status() != WL_CONNECTED) {
            wifiConnected = false;
            if (!provisioningMode) {
                WiFi.reconnect();
            }
        } else {
            wifiConnected = true;
        }
    }

    // 4. Offline Demo Clock Tick & System Heartbeat LED
    static unsigned long lastSecondTick = 0;
    static bool heartbeatState = false;
    if (now - lastSecondTick >= 1000) {
        lastSecondTick = now;
        // Blink blue LED every second on 240x240; keep solid HIGH on 360x360 to prevent backlight blinking
#if !defined(SCREEN_360) && !defined(SCREEN_GC9B72_360)
        digitalWrite(8, heartbeatState ? LOW : HIGH);
#endif

        safeStateOperation([]() {
            timeData.seconds++;
            if (timeData.seconds >= 60) {
                timeData.seconds = 0;
                timeData.minutes++;
                if (timeData.minutes >= 60) {
                    timeData.minutes = 0;
                    timeData.hours = (timeData.hours + 1) % 24;
                }
            }
        });
    }

    // 5. WS2812B Addressable LED Status Light (Non-blocking update)
    bool isWaitingInput = false;
    safeStateOperation([&]() {
        isWaitingInput = agentData.waiting_for_input;
    });
    ledController.update(isWaitingInput, backendConnected, false);
}

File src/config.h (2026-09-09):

#pragma once
#include <Arduino.h>

#define FIRMWARE_VERSION "0.5"

// ==========================================
// PIN CONFIGURATION (ESP32-C3 SuperMini)
// ==========================================
// SPI Bus Pin Configurations
#if defined(SCREEN_360) || defined(SCREEN_GC9B72_360)
#define IS_SCREEN_360 1
#define SCREEN_WIDTH  360
#define SCREEN_HEIGHT 360

#define DISPLAY_SCK_PIN  3   // SCL -> Board Pin 3 (GPIO 3)
#define DISPLAY_MOSI_PIN 4   // SDA -> Board Pin 4 (GPIO 4)
#define DISPLAY_RST_PIN  5   // RST -> Board Pin 5 (GPIO 5)
#define DISPLAY_DC_PIN   6   // DC  -> Board Pin 6 (GPIO 6)
#define DISPLAY_CS_PIN   7   // CS  -> Board Pin 7 (GPIO 7)
#define DISPLAY_BLK_PIN  0   // Backlight PWM/Enable -> GPIO 0 (or GPIO 8)

#define R_OUTER_MIN 151
#define R_OUTER_MAX 160
#define R_THIN_MIN  141
#define R_THIN_MAX  143
#define R_BEZEL_1   174
#define R_BEZEL_2   175
#define R_HAZARD_MIN 172
#define R_HAZARD_MAX 177

#else
#define IS_SCREEN_360 0
#define SCREEN_WIDTH  240
#define SCREEN_HEIGHT 240

#define DISPLAY_SCK_PIN  4   // SCL -> GPIO 4
#define DISPLAY_MOSI_PIN 6   // SDA -> GPIO 6
#define DISPLAY_DC_PIN   7   // DC  -> GPIO 7
#define DISPLAY_CS_PIN   5   // CS  -> GPIO 5
#define DISPLAY_RST_PIN  1   // RST -> GPIO 1
#define DISPLAY_BLK_PIN  -1  // Backlight hardwired to VCC on 7-pin display

#define R_OUTER_MIN 101
#define R_OUTER_MAX 107
#define R_THIN_MIN  94
#define R_THIN_MAX  95
#define R_BEZEL_1   116
#define R_BEZEL_2   117
#define R_HAZARD_MIN 115
#define R_HAZARD_MAX 118
#endif

// Legacy aliases for backwards compatibility
#define GC9A01_SCK_PIN  DISPLAY_SCK_PIN
#define GC9A01_MOSI_PIN DISPLAY_MOSI_PIN
#define GC9A01_DC_PIN   DISPLAY_DC_PIN
#define GC9A01_CS_PIN   DISPLAY_CS_PIN
#define GC9A01_RST_PIN  DISPLAY_RST_PIN
#define GC9A01_BLK_PIN  DISPLAY_BLK_PIN
#define GC9B72_SCK_PIN  DISPLAY_SCK_PIN
#define GC9B72_MOSI_PIN DISPLAY_MOSI_PIN
#define GC9B72_DC_PIN   DISPLAY_DC_PIN
#define GC9B72_CS_PIN   DISPLAY_CS_PIN
#define GC9B72_RST_PIN  DISPLAY_RST_PIN
#define GC9B72_BLK_PIN  DISPLAY_BLK_PIN

// WS2812B Addressable LED Status Configuration (ESP32-C3 SuperMini)
#define WS2812_PIN 10
#define WS2812_MAX_LEDS 64
#define WS2812_DEFAULT_ACTIVE_LEDS 16

// ==========================================
// TIMING & THRESHOLDS
// ==========================================
const unsigned long wifiConnectTimeoutMs = 8000;
const unsigned long backendPollInterval = 3000;
const unsigned long sleepIdleThresholdMs = 15UL * 60UL * 1000UL;
const long claudeHeavyUsageThreshold = 2500000;

// ==========================================
// DATA STRUCTURES
// ==========================================
struct ClaudeLimits {
    long tokensToday = 0;
    int limit = 100;
    int remaining = 100;
    String reset_time = "";
    int reset_in_seconds = -1;
    String reset_str = "";
};

struct AntigravityLimits {
    int limit = 200;
    int remaining = 200;
    int used = 0;
    String period = "5h";
    String reset_time = "";
    int reset_in_seconds = -1;
    String reset_str = "";
};

struct WeatherInfo {
    float temp = 23.5;
    int hours_until_rain = -1;
    String location = "DESKTOP";
};

struct SingleAgentInfo {
    String name = "";
    String source = "antigravity"; // antigravity or claude
    String state = "IDLE"; // WAITING, WORKING, COMPLETE, IDLE
    String detail = "";
    uint16_t color = 0x9D37; // default muted slate
};

struct AgentStatus {
    bool waiting_for_input = false;
    bool work_completed = false;
    bool has_active_agents = false;
    int active_agent_count = 0;
    SingleAgentInfo active_agents[8];
    String prompt_text = "APPROVE PLAN";
    String completion_text = "WORK COMPLETE";
};

struct LedConfig {
    String waiting_anim = "breathe";
    uint8_t brightness = 35;
    uint16_t active_leds = 16;
};

struct TimeInfo {
    int hours = 12;
    int minutes = 0;
    int seconds = 0;
    String time_str = "12:00:00";
    String date_str = "FRI AUG 21";
};

struct GaugeInfo {
    String id = "claude";
    String label = "CLD";
    String name = "Claude";
    String mode = "standard"; // "standard" | "enterprise"
    String cost_str = "$0.00";
    String curved_text = "";
    int percent = 100;
    uint16_t color = 0x07FF; // Cyan
    String reset_str = "READY";
};

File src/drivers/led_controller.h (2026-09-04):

/**
 * @file led_controller.h
 * @brief WS2812B LED status controller for ESP32-C3 SuperMini using NeoPixelBus.
 * 
 * Hardware: ESP32-C3 RMT DMA peripheral (NeoEsp32Rmt0Ws2812xMethod)
 * Zero CPU blocking during transmission — 100% safe for concurrent WiFi & SPI display.
 * 
 * Made by Antigravity
 */

#pragma once

#include <Arduino.h>
#include <NeoPixelBus.h>
#include <algorithm>
#include <cmath>

#ifndef WS2812_PIN
#define WS2812_PIN 10
#endif

#ifndef WS2812_MAX_LEDS
#define WS2812_MAX_LEDS 64
#endif

#ifndef WS2812_DEFAULT_ACTIVE_LEDS
#define WS2812_DEFAULT_ACTIVE_LEDS 16
#endif

// Hard brightness clamp (~39% duty cycle) to guarantee <= 250mA draw on USB rail
#define MAX_BRIGHTNESS_CLAMP 100 

enum class LedWaitingAnim {
    OFF = 0,
    SOLID,
    BREATHE,
    RADAR,
    HEARTBEAT,
    HAZARD
};

class LedController {
public:
    LedController(uint8_t pin = WS2812_PIN, 
                  uint16_t maxLeds = WS2812_MAX_LEDS, 
                  uint16_t activeLeds = WS2812_DEFAULT_ACTIVE_LEDS)
        : _pin(pin),
          _maxLeds(maxLeds),
          _activeLeds(std::min(activeLeds, maxLeds)),
          _strip(maxLeds, pin),
          _brightness(35),
          _currentAnim(LedWaitingAnim::BREATHE),
          _lastFrame(0),
          _wasActive(false) {}

    void begin() {
        _strip.Begin();
        clear();
    }

    uint8_t getSafeMaxBrightness() const {
        // Dynamic Power Budget: max 350mA allocated to the LED rail.
        // Full amber (R:255, G:170) draws ~35mA per pixel at 100% duty cycle.
        // max_safe_brightness = (350mA * 100) / (activeLeds * 35mA) = 1000 / activeLeds
        uint16_t safeMax = (uint16_t)(1000 / std::max((uint16_t)1, _activeLeds));
        return (uint8_t)std::min((uint16_t)MAX_BRIGHTNESS_CLAMP, safeMax);
    }

    void setActiveLedCount(uint16_t count) {
        _activeLeds = std::max((uint16_t)1, std::min(count, (uint16_t)WS2812_MAX_LEDS));
        _brightness = std::min(_brightness, getSafeMaxBrightness());
    }

    uint16_t getActiveLedCount() const {
        return _activeLeds;
    }

    void setBrightness(uint8_t brightness) {
        _brightness = std::min(brightness, getSafeMaxBrightness());
    }

    uint8_t getBrightness() const {
        return _brightness;
    }

    void setAnimation(LedWaitingAnim anim) {
        _currentAnim = anim;
    }

    LedWaitingAnim getAnimation() const {
        return _currentAnim;
    }

    void setAnimationByName(const String& name) {
        if (name.equalsIgnoreCase("breathe")) _currentAnim = LedWaitingAnim::BREATHE;
        else if (name.equalsIgnoreCase("radar")) _currentAnim = LedWaitingAnim::RADAR;
        else if (name.equalsIgnoreCase("heartbeat")) _currentAnim = LedWaitingAnim::HEARTBEAT;
        else if (name.equalsIgnoreCase("hazard")) _currentAnim = LedWaitingAnim::HAZARD;
        else if (name.equalsIgnoreCase("solid")) _currentAnim = LedWaitingAnim::SOLID;
        else _currentAnim = LedWaitingAnim::OFF;
    }

    void clear() {
        for (uint16_t i = 0; i < _maxLeds; i++) {
            _strip.SetPixelColor(i, RgbColor(0, 0, 0));
        }
        _strip.Show();
    }

    /**
     * @brief Non-blocking render update. Must be called in loop().
     * Rate-limited to ~30 FPS to minimize bus overhead.
     */
    void update(bool waiting_for_input, bool backendConnected, bool isSleeping) {
        const uint32_t now = millis();

        // Disconnect, sleep, or idle guard: turn off LEDs immediately
        if (!waiting_for_input || !backendConnected || isSleeping || _currentAnim == LedWaitingAnim::OFF) {
            if (_wasActive) {
                clear();
                _wasActive = false;
            }
            return;
        }

        // Throttle animation rendering to ~30 FPS (every ~33ms)
        if (now - _lastFrame < 33) return;
        _lastFrame = now;
        _wasActive = true;

        switch (_currentAnim) {
            case LedWaitingAnim::SOLID:
                runSolid();
                break;
            case LedWaitingAnim::BREATHE:
                runBreathe(now);
                break;
            case LedWaitingAnim::RADAR:
                runRadar(now);
                break;
            case LedWaitingAnim::HEARTBEAT:
                runHeartbeat(now);
                break;
            case LedWaitingAnim::HAZARD:
                runHazard(now);
                break;
            default:
                clear();
                break;
        }

        _strip.Show();
    }
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

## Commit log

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2026-08-20 Switch to SSD1306 OLED display, fix ESP32-C3 WiFi auth failures, move credentials out of source
    Lower WiFi TX power and disable modem sleep to fix a persistent AUTH_EXPIRE
    handshake failure against the home router; move WiFi credentials into a
    gitignored secrets.h. Backend gains an emulator route, CORS headers, and a
    proper 5h-window Antigravity usage scan.
    [main.cpp]
2026-08-20 Show Antigravity quota as remaining percentage instead of raw count
    The raw used/limit numbers were meaningless since the "limit" is a
    guessed local calibration value, not a real published quota. A
    percentage reads correctly regardless of what the underlying ceiling
    is set to.
    [main.cpp]
2026-08-21 Fix intermittent WiFi AUTH_FAIL against WPA2/WPA3-mixed enterprise APs
    Diagnosed by scanning target-SSID BSSIDs before connecting: the office
    guest network runs on Ubiquiti UniFi APs (OUI AC:23:16) in WPA2/WPA3
    mixed mode. The ESP32 WiFi stack negotiates PMF (802.11w) with these
    unreliably, causing repeated AUTH_FAIL / handshake timeouts even with
    the correct password -- it would connect maybe 1 in a few boots.
    Force PMF off via esp_wifi_set_config before connecting, bypassing
    what WiFi.begin() negotiates by default. Also bumped the connect
    timeout from 15s to 30s since successful handshakes on this network
    still take longer and more retries than a typical home router.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
    [main.cpp]
2026-08-21 Auto-discover backend via mDNS instead of a hardcoded IP; add face animation UI, enclosure files, and QBIT emulator prototype
    The backend IP had to be hand-updated every time the Mac switched
    networks. The ESP32 now resolves the Mac's Bonjour hostname
    (backend_mdns_host in secrets.h) via mDNS at boot and on connection
    failure, falling back to a fixed IP only on networks that block mDNS
    multicast (confirmed happening on the office guest WiFi, even though
    plain unicast between clients works fine there).
    Also includes a new animated face/eyes screen and split-HUD screen,
    3D-printable enclosure files, and a QBIT emulator prototype page.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
    [bottom_base.stl, desk_console_oled13_esp32c3.scad, full_assembly_preview.stl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]
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2026-08-21 Replace fake Claude token limit with real today's-usage count; fix header text overlap
    Our corporate Claude plan has no monthly/weekly quota, so the old
    Xk/500k bar and progress fill were showing a fabricated ceiling.
    scan_claude_tokens_today() now reports real tokens processed today
    (input + output + freshly-cached context), deliberately excluding
    cache_read_input_tokens -- a single long session replays tens of
    millions of cheap cached-context tokens per turn, which would swamp
    the number with something proportional to turn count rather than
    real work. Calibrated a ~2.5M/day "heavy usage" threshold against 14
    days of actual history (typical days ran 250k-5.3M) for the tired-eyes
    animation a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
    [main.cpp]
2026-08-21 Fix agent-alert flash rate being unreadably fast at 30 FPS (fixes #4)
    renderAgentAlertScreen() toggled its invert state once per render call,
    which was fine back when the whole loop ran at ~2.5Hz (400ms delay per
    frame). Now that the face-animation refactor runs every screen at 30
    FPS, the same per-call toggle produced a ~15Hz flicker -- effectively
    unreadable as a "flash". Toggle on elapsed wall-clock time instead
    (350ms half-period) so the flash rate stays visible regardless of the
    render loop's frame rate.
    Verified end-to-end with a synthetic pending ask_question: alert
    triggers, board runs stably while it's active, and clears correctly
    once the synthetic transcript is removed.
    The othe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
    [main.cpp]
2026-08-21 Fix alert lingering ~15s after approval due to backend URL being discarded too eagerly
    fetchBackendData() cleared backendUrl on every single connection
    failure, forcing a full mDNS re-resolve before the next fetch could
    even be attempted. On this network's occasional transient blips, that
    froze all polled state -- including agentData.waiting_for_input -- for
    up to mdnsResolveCooldownMs (30s) with zero fetch attempts in between,
    since a fresh IP resolution was gated behind a cooldown that a single
    blip shouldn't have triggered in the first place.
    Now only discard the URL after 3 consecutive failures (~9s of genuine
    unreachability), and shrink the mDNS cooldown to 10s since queries are
    cheap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
    [main.cpp]
2026-08-21 Provision WiFi over USB via Improv Wi-Fi; discover backend by mDNS service instead of hardcoded hostname
    Nothing is hardcoded per-user at compile time anymore. Previously,
    getting the board working required editing src/secrets.h (WiFi
    SSID/password, plus a hardcoded Mac hostname to find the backend) and
    recompiling -- only usable by the original developer, never a new
    recipient.
    WiFi: credentials are now provisioned at runtime over USB via the
    Improv Wi-Fi serial protocol (jnthas/Improv-WiFi-Library) and stored
    in NVS (Preferences). The board tries stored credentials at boot;
    absent or failing credentials (e.g. router password changed) fall
    through to a provisioning screen instead of gettin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
    [main.cpp]
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2026-08-21 Add sleeping-eyes idle animation and Claude statusLine quota hook
    Board now shows closed eyelids with drifting z's after 15 minutes of no
    change in tokens-today, instead of the normal blink/heavy-usage state.
    Also adds backend/claude_statusline.py, a Claude Code statusLine hook that
    caches the real rate_limits.five_hour/seven_day usage percentages (Pro/Max
    accounts only) to ~/.tiny_ai_screen/claude_rate_limits.json for future use
    by the companion backend.
    [main.cpp]
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2026-08-21 fix(enclosure): recompile manifold hollow STLs using OpenSCAD CSG boolean engine with verified cavities, ports, and screw holes
    [gc9a01_cyberdeck_enclosure.scad, gc9a01_desk_stand.stl, gc9a01_front_bezel.stl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]
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2026-08-24 feat(gc9a01): add 3D perspective flip card folding animation and zero-overlap micro-HUD telemetry badges
    [main.cpp]
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2026-08-24 fix(gc9a01): wipe outer radial band (radii 115-119) on alert exit to completely clear yellow/amber ring
    [main.cpp]
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2026-08-24 fix(gc9a01): full-screen hardware wipe on alert exit and 0.2deg subpixel resolution to eliminate perimeter dots
    [main.cpp]
2026-08-24 fix(gc9a01): clamp hours to 0..23 and minutes to 0..59 to prevent invalid 12:99 clock rendering
    [main.cpp]
2026-08-24 feat(enclosure): redesign GC9A01 3D enclosure with 36mm depth and 44x44mm cavity for DuPont connectors and upward pin headers
    [gc9a01_cyberdeck_enclosure.scad, gc9a01_desk_stand.stl, gc9a01_front_bezel.stl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]
2026-08-24 fix(enclosure): generate 100% watertight, genuinely hollow STL meshes using manifold3d boolean CSG
    [gc9a01_desk_stand.stl, gc9a01_front_bezel.stl, gc9a01_main_housing.stl]
2026-08-24 feat(enclosure): redesign desk stand to replicate concept render with sculpted two-tier pedestal and 22deg V-saddle cradle
    [gc9a01_cyberdeck_enclosure.scad, gc9a01_desk_stand.stl, gc9a01_stand_accent_base.stl]
2026-08-24 fix(enclosure): align ESP32-C3 mounting rails along X-axis with left USB-C port cutout
    [gc9a01_cyberdeck_enclosure.scad, gc9a01_main_housing.stl]
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2026-08-24 feat(enclosure): slim pod depth to 26.0mm for sleek concept-accurate proportions while maintaining full internal clearance
    [gc9a01_cyberdeck_enclosure.scad, gc9a01_desk_stand.stl, gc9a01_main_housing.stl]
2026-08-24 feat(enclosure): add bottom DuPont wire drop trench and expand stand cable channel to 20mm for zero bottom pin collision
    [gc9a01_cyberdeck_enclosure.scad, gc9a01_desk_stand.stl, gc9a01_front_bezel.stl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]
2026-08-24 fix(enclosure): make 2mm screen-mounting holes full through-holes on front bezel for clear visibility and accessibility
    [gc9a01_cyberdeck_enclosure.scad, gc9a01_front_bezel.stl]
2026-08-24 fix(enclosure): make screen mounting holes 1.75mm blind pilot holes from the rear pocket to grip M2 threads while leaving front face solid
    [gc9a01_cyberdeck_enclosure.scad, gc9a01_front_bezel.stl]
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2026-08-24 fix(enclosure): eliminate bottom slit from main housing pod, restoring 100% solid enclosed outer walls and updating engineering technical drawings
    [gc9a01_cyberdeck_enclosure.scad, gc9a01_desk_stand.stl, gc9a01_front_bezel.stl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]
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2026-08-24 fix(enclosure): ensure 4 corner M2 pilot screw holes in main housing are cleanly open and subtracted in single-pass CSG
    [gc9a01_main_housing.stl]
2026-08-24 fix(enclosure): chamfer internal cavity to preserve 4 massive solid corner screw pillars with open M2 pilot holes in main housing
    [gc9a01_cyberdeck_enclosure.scad, gc9a01_main_housing.stl]
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2026-08-24 feat(enclosure): add wide 36.4-degree sloping inner conical aperture to front bezel to prevent display shadows
    [gc9a01_cyberdeck_enclosure.scad, gc9a01_front_bezel.stl]
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2026-08-24 feat(enclosure): rework desk stand into minimalist L-shaped tilted bracket with cradle shelf
    [gc9a01_cyberdeck_enclosure.scad, gc9a01_desk_stand.stl]
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2026-08-24 feat(enclosure): redesign Tier 2 as a sculpted monolithic trapezoidal pedestal block with continuous draft angles on all 4 sides
    [gc9a01_cyberdeck_enclosure.scad, gc9a01_desk_stand.stl, gc9a01_stand_tier1_base.stl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]
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2026-08-24 fix(enclosure): fix cradle cutter rotation axis to create true upright 14 degree pod saddle
    [gc9a01_cyberdeck_enclosure.scad, gc9a01_desk_stand.stl, gc9a01_stand_tier2_trunk.stl]
2026-08-24 fix(enclosure): widen stand top to 62mm to provide 3.6mm solid side walls connecting front chin and sides
    [gc9a01_cyberdeck_enclosure.scad, gc9a01_desk_stand.stl, gc9a01_stand_tier1_base.stl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]
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2026-08-24 fix(enclosure): enlarge desk stand cradle slot to fit 30mm round screen pod
    [gc9a01_cyberdeck_enclosure.scad, gc9a01_desk_stand.stl, gc9a01_stand_tier2_trunk.stl]
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2026-08-24 feat(enclosure): add DuPont wire clearance trench and elevate USB-C port centerline to 8.25mm
    [gc9a01_cyberdeck_enclosure.scad, gc9a01_main_housing.stl]
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2026-08-24 fix(enclosure): add 0.1mm clearance to front housing screen pocket
    - Increased circular PCB pocket diameter to 38.8mm (+0.1mm clearance per side)
    - Increased glass retention step diameter to 36.2mm
    - Increased bottom connector tab width to 23.8mm and pocket depth to 3.3mm
    - Regenerated 100% watertight manifold STL and 300 DPI technical drawing blueprints
    [gc9a01_cyberdeck_enclosure.scad, gc9a01_front_bezel.stl]
2026-08-25 feat(enclosure): add snap-fit retention clips, top relief notch, and +0.1mm screen cutout clearance
    - Added 4x integrated cantilever snap clips (+/-40 deg upper, +/-130 deg lower) with 45-deg lead-in ramps and flex relief slots
    - Added expanded top relief notch (18.0mm x 23.0mm) for screen solder/ribbon overhang
    - Increased screen cutout clearance by an additional +0.1mm (PCB pocket dia 39.0mm, glass step dia 36.4mm, tab width 24.0mm)
    - Regenerated 100% watertight manifold STL (gc9a01_front_bezel.stl)
    [gc9a01_cyberdeck_enclosure.scad, gc9a01_front_bezel.stl]
2026-08-25 fix(enclosure): use internal blind snap detents with 100% solid front face
    - Replaced through-slots with 4x internal blind snap detents molded into the pocket wall
    - Preserved 100% solid, smooth front cosmetic faceplate with zero through-cuts
    - Maintained expanded top relief notch (18.0mm x 23.0mm) and +0.1mm clearance
    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
    [gc9a01_cyberdeck_enclosure.scad, gc9a01_front_bezel.stl]
2026-08-25 fix(enclosure): fix Boolean tree so internal retention detents are physically present in pocket
    - Added detent teeth after pocket cut so they are not subtracted away
    - Shaped detent teeth with 45-deg lead-in insertion ramps and flat locking shoulders
    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
    [gc9a01_cyberdeck_enclosure.scad, gc9a01_front_bezel.stl]
2026-08-25 feat(enclosure): add blind flex relief trenches behind spring arms for physical bending compliance
    - Added 1.3mm wide blind flex relief trenches (depth Z=0 to 3.5mm) behind each 1.4mm spring arm
    - Allows cantilever arms to flex radially outwards into the blind air gap cavity during screen installation
    - Trenches stop strictly at Z=3.5mm leaving 100% solid, unpierced front faceplate (>2.0mm solid thickness)
    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
    [gc9a01_cyberdeck_enclosure.scad, gc9a01_front_bezel.stl]
2026-08-25 feat(enclosure): implement 3-sided U-slot isolation with top gap for spring compliance
    - Added 3-sided U-slot isolation cuts (left slit + right slit + back trench + top gap)
    - Created free cantilever beam with top clearance gap allowing free deflection on push-in
    - Kept front cosmetic faceplate 100% solid with zero through-cuts
    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
    [gc9a01_cyberdeck_enclosure.scad, gc9a01_front_bezel.stl]
2026-08-25 feat(enclosure): implement tapered friction ribs and housing forward clamping
    - Reverted fragile cantilever cuts and restored 100% solid, robust 5.5mm front bezel plate
    - Added 4x smooth tapered friction ribs (0.0mm at entrance to 0.25mm at seat) for snug drop-in hold
    - Added housing forward compression clamping when assembling with 4 corner M3 bolts
    - Retained +0.1mm screen clearance (pocket dia 39.0mm) and 18.0x23.0mm top relief notch
    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
    [gc9a01_cyberdeck_enclosure.scad, gc9a01_front_bezel.stl]
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2026-08-25 fix(enclosure): remove floating rim tabs on main housing for 100% support-free printability
    - Restored completely planar top rim on main housing (Z=27.5mm)
    - Eliminated unsupported mid-air overhang tabs over cavity
    - Screen is retained securely via front bezel precision tapered friction ribs and flush bolting
    - Regenerated 100% watertight manifold STLs
    [gc9a01_cyberdeck_enclosure.scad, gc9a01_main_housing.stl]
2026-08-25 feat(enclosure): implement Solution 2 reverse catch detents locking screen forward
    - Replaced forward-tapering wedge ribs with straight cylindrical pocket (dia 39.0mm)
    - Added 4x discrete 0.35mm reverse catch shelves at rear entrance (Z=1.1mm)
    - Forward-locking shelves trap PCB from behind and keep it held flush against front glass stop
    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
    [gc9a01_cyberdeck_enclosure.scad, gc9a01_front_bezel.stl]
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2026-08-25 fix(enclosure): fix split tooth geometry so exactly 4 single retention tabs exist
    - Replaced intersecting ramp cutters with clean monolithic 3D hull geometry
    - Eliminated split ridges so exactly 4 single forward-holding catch tabs exist total
    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
    [gc9a01_cyberdeck_enclosure.scad, gc9a01_front_bezel.stl]
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2026-08-25 fix(wifi): stop board getting permanently stuck in provisioning after one failed connect (#30)
    * fix(wifi): stop board from getting permanently stuck in provisioning after one failed boot connect
    The ESP32-C3's link to the router is occasionally flaky (AUTH_EXPIRE /
    4-way-handshake timeouts on some auth attempts, confirmed via serial
    logs). Previously, if the very first connection attempt in setup()
    failed, provisioningMode was set permanently and loop()'s auto-reconnect
    explicitly skipped retrying while in that mode -- stranding the board
    with no WiFi until a manual reset or re-provisioning, even though a
    retry would very likely succeed.
    loop() now retries the stored credentials periodica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
    [main.cpp]
2026-08-26 feat: add cyber boot logo, enclosure top tolerance, and wifi mDNS fixes (#32)
    - Display high-contrast Cyber Kimishiba boot logo on GC9A01 screen init
    - Increase front bezel top relief notch tolerance (+6mm width, +3mm height)
    - Include mDNS service host label improvements in companion app
    - Update Web Serial provisioning and scan result parser
    [gc9a01_cyberdeck_enclosure.scad, gc9a01_front_bezel.stl]
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2026-08-26 feat(firmware): give each board a unique mDNS hostname
    Every board called MDNS.begin("tinyscreen"), so two boards on the same
    subnet fought over tinyscreen.local (#33).
    The name is now derived from the last two bytes of the efuse MAC, e.g.
    tinyscreen-F030, and is reported in the STATUS serial response so the
    setup page can show which board it is talking to.
    Read via ESP.getEfuseMac() so it also works before the WiFi driver has
    started. Note the byte order: esp_efuse_mac_get_default() packs the MAC
    into a little-endian u64, so pulling a u16 out in one shot yields the two
    suffix bytes reversed relative to the MAC printed on the board.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
    [main.cpp]
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2026-08-26 feat(setup): send the companion address when provisioning a board
    Completes the pairing path for #33. Until now nothing sent the pairing
    fields, so the firmware support added in c0e4d3a was unreachable.
    The setup page reads GET /whoami before writing to serial and appends
    the companion's host, port and pair_id to the credentials line. A
    browser cannot read its own machine's LAN address, so it asks the
    backend for it. If /whoami fails the page falls back to the two-field
    line and the board discovers via mDNS as before.
    SSID and password are percent-escaped. Spaces are escaped along with
    tab, CR, LF and '%': the firmware trims each field, which would
    otherwise silently eat a leading or trail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
    [main.cpp]
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2026-08-26 feat: latch pairing, require pair_id, and show unpaired state on screen
    Resolves the three decisions left open on #33.
    Latch (pair/ever in NVS): a board that has been paired even once never
    falls back to first-responder discovery again, even if it loses track of
    its host. It shows no data and waits to be re-paired rather than risk
    adopting another user's companion. Boards that have never been paired
    keep the old discovery behaviour, so nothing in the field breaks.
    Require pair_id: savePairing() now rejects an empty id and returns bool.
    Without an id a board cannot re-find its companion after a DHCP change,
    and a half-paired board is a state not worth reasoning about. The setup
    page already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
    [main.cpp]
2026-08-26 fix(wifi): fix Improv WiFi handshake timeout and add manual backend URL override (#36)
    Two independent issues found while debugging the board failing to
    provision/connect at a new location:
    1. Improv WiFi's browser-side handshake (the "CONNECT & SET UP WIFI"
    button) always timed out ("Error fetching current state: TIMEOUT"),
    even with the board already idle and connected. Root cause:
    ImprovWiFi::handleSerial() consumes exactly one byte per call, but
    every call site in this firmware only called it once per loop tick
    (once per 500ms during the boot-time WiFi connect wait, or once per
    loop() iteration otherwise). A full Improv packet (11+ bytes) could
    take multiple ticks t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
    [main.cpp]
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2026-08-26 chore: report backend state in STATUS, bump to 0.4.0
    STATUS now includes backend_connected, backend_url and the consecutive
    failure count. Without them there was no way to tell a board that could
    not reach its companion from one being refused by it, which is exactly
    what the status LED colour depends on.
    Earned during hardware testing: a red status dot turned out to be the
    test tooling resetting the board over serial rather than any fault in
    the indicator, and these fields are what settled it.
    Version goes to 0.4.0 for the pairing release (firmware and companion
    app share the tag).
    [main.cpp]
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2026-08-27 Fix: Trigger yellow alert and GRANT PERM when agent is waiting for tool permission (#52)
    * feat(antigravity): display time left until 5h quota reset (#47)
    - Add format_reset_time helper calculating remaining reset countdown seconds and formatted string (e.g. '4h 57m', '42m', 'READY')
    - Expose reset_time, reset_in_seconds, and reset_str under antigravity payload in /data
    - Update GC9A01 240x240 firmware (src/main.cpp) to alternate AGY badge between remaining % and reset countdown
    - Mirror 3.5s alternating reset countdown on emulator (emulator/index.html)
    - Add comprehensive unit tests in backend/tests/test_agent_status.py (21/21 tests passing)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
    [main.cpp]
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2026-08-27 feat(ui): Add Concept A Telemetry Packet Ping animation to top connection arc (#56)
    * feat(ui): add Concept A telemetry packet ping animation to top connection arc
    - Track backend poll success timestamp in ESP32 firmware
    - Animate center-out neon emerald ripple on GC9A01 top connection crown
    - Settle into calm resting dim emerald state when idle
    - Update web emulator with synchronized 3s telemetry poll ping animation
    - Add GIF generator tool and assets
    * fix(ui): suppress top bar telemetry ping during active agent alerts
    - Give visual priority to approval hazard flashing and work completion alerts
    - Pause te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
    [main.cpp]
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2026-08-28 fix(weather): resolve rain detection for active weather codes and sub-hour timestamps (#64)
    * fix(enclosure): correct text engraving orientation for direct rear exterior viewing
    - Orient debossed branding so it reads correctly from left to right when viewing the device from the rear
    - Sync generate_stl.py, generate_option1_test.py, and gc9a01_cyberdeck_enclosure.scad
    - Re-export verified 100% watertight binary STLs
    * feat(enclosure): round the rear ESP32 retaining pillars in Option 1 test model
    - Replace pointy chamfered tops with smooth cylindrical rounded shoulders (R=2.0mm)
    - Align height with side guide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
    [esp32_s3_supermini_carrier.stl, gc9a01_main_housing.stl]
2026-08-28 feat(claude): Claude Enterprise 24h USD Cost and Token Telemetry (#62)
    * feat(claude): add enterprise 24h usage cost and token telemetry
    - Implement multi-model USD pricing calculator for Sonnet 3.7/3.5, Haiku, Opus, cache reads and writes
    - Add 24h and calendar-day token volume and cost scanner in Claude provider
    - Render dynamic '$X.XX SPENT' curved text along gauge radius and 'XXXk TOK' reset footer on GC9A01 screen
    - Expand ESP32 StaticJsonDocument buffer to 4096 to prevent overflow with enterprise telemetry
    - Add Claude plan toggle and daily budget inputs to web setup interface and emulator
    - Add 50/50 passing test suite coverage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
    [gc9a01_u_bracket_kickstand.stl]
2026-08-28 docs: Document Universal Enterprise Spend Mode, Pricing Engine & Daily Budgets (#65)
    * fix(enclosure): rebuild cradle with clean 2D extruded continuous U-walls
    - Eliminate all boolean cutter cubes and slicing chamfers
    - Extrude unified continuous side guide walls and rear cheeks directly in 2D
    - Eliminate all facet slivers, steps, and degenerate mesh artifacts
    - Retain continuous 1.0mm bottom support ledges and clean compliant cantilever snap arm
    - Verified 100% watertight manifold mesh across all 6 models
    * docs: document universal enterprise spend mode, pricing engine, and daily budget tracking
    - Add detai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
    [gc9a01_main_housing.stl]
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2026-08-28 feat(enclosure): enlarge bottom case debossed letters by 25% (#59)
    - Align height with side guide walls (Z=2.0 to 8.2mm)
    -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
    [gc9a01_cyberdeck_enclosure.scad, gc9a01_front_bezel.stl, gc9a01_main_housing.stl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]
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2026-08-30 test: add complete unit test suite with mock fixtures and edge cases (#75)
    * feat: multi-agent vertical scrolling when active agents exceed screen capacity (fixes #73)
    - Expand active agent capacity from 3/4 to 8 agents in backend and ESP32 firmware
    - Implement smooth ping-pong vertical yo-yo scroll on GC9A01 circular display
    - Add top (y=44..54) and bottom (y=184..196) corridor guard band masking
    - Implement Canvas clipping and synchronized scroll in web emulator
    - Add multi-agent unit test and live display test scenario
    Implemented via Mistral Devstral (mistral/devstral) on FreeLLMAPI.
    * test: add complete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
    [main.cpp]
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
